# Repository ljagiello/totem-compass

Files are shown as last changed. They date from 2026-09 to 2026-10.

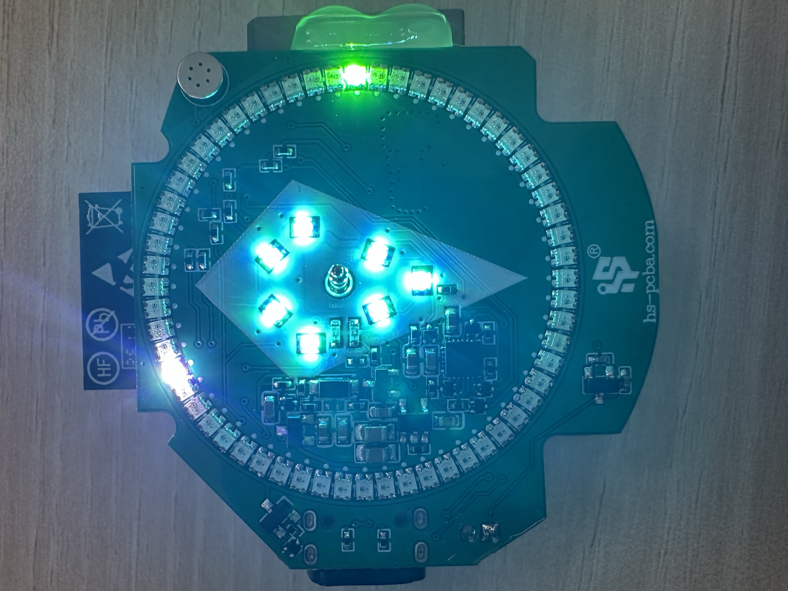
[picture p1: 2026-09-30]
hardware/totem-v3.5-reference/measure/photos/led.jpg

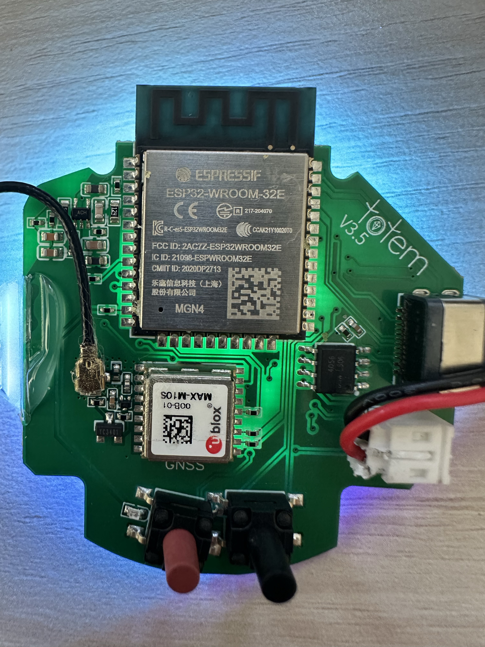
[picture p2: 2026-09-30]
hardware/totem-v3.5-reference/measure/photos/radio.jpg

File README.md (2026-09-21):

# Totem Compass firmware — reverse engineering

Independent, unofficial reverse-engineering notes for the **Totem Compass** ESP32
firmware (**v5.0.3**; v5.0.2 was analyzed first, see
[What changed in 5.0.3](docs/firmware/changes-5.0.3.mdx)), produced by static analysis of the
publicly downloadable firmware images and the companion mobile app, plus a BLE client tested
against the author's own device. Not affiliated with or endorsed by Totem Labs.

## Key findings

- The device is an **ESP32** (Xtensa LX6) running **MicroPython v1.25.0** on **ESP-IDF v5.4**.
- Totem's application is **Python**, frozen into the image as bytecode across **94 frozen modules** in v5.0.3 (96 in v5.0.2), plus 2 non-frozen on-flash `.py` files.
- Three radios share the 2.4 GHz band: **BLE** (phone app), **ESP-NOW** ("Unity Mesh",
  Totem-to-Totem), and **WiFi** (station-mode OTA; the hotspot path is sunset).
- Application messages use a shared `(cat_id, cmd_id)` model with a common chunking layer.

## Documentation

Full docs live in [`docs/`](docs/) as a [Mintlify](https://mintlify.com) site.

```bash
cd docs
npm i -g mint    # or: npx mint@latest
mint dev         # preview at http://localhost:3000
```

Start at [`docs/index.mdx`](docs/index.mdx). The 2.4 GHz protocol capture — with a
completeness matrix — is under [`docs/protocols/`](docs/protocols/).

## Go client: `totemctl`

A Bluetooth LE client that speaks the same protocol as the official app: the
ConnStatus-Ready handshake, Live/Static/Peer records, and the half-duplex TX
handoff. No pairing or keys are needed.

```bash
go install github.com/ljagiello/totem-compass/cmd/totemctl@latest

totemctl scan                     # find Totems (double-press the power button first)
totemctl info                     # name, firmware, battery, position, settings
totemctl watch                    # stream live data and peer updates
totemctl peers                    # bonded Totems and points of interest
totemctl name "Base Camp"         # rename
totemctl compass --lock on --north off --blink on
totemctl power eco --blink on     # or: normal
totemctl wifi scan                # networks the Totem can see
totemctl wifi set <ssid>          # network used for firmware updates; asks for the password
totemctl peer color <mac> hot_pink
totemctl poi add --name "Main Stage" --lat 50.0671 --lon 19.9124 --sticky
totemctl location --lat 50.0671 --lon 19.9124  # feed a phone-style GNSS fix + clock
```

Pick a device with `-d <address substring>`, using an address `totemctl scan`
prints: every Totem advertises as "totem", so the name set with `totemctl name`
cannot select one. Get machine-readable output with `--json`, and log every
frame with `--trace`. `totemctl help <command>` lists each command's flags.

Every global flag can also be set as a `TOTEM_<FLAG>` environment variable
(`TOTEM_DEVICE`, `TOTEM_HALF_DUPLEX`, …) or in a config file with the long flag
names as keys (`device: <address from totemctl scan>`). The default location is
`totemctl/config.yaml` under the user config directory (`~/Library/Application
Support` on macOS, `~/.config` on Linux), or pass `--config`.

`compass` and `power` send a frame that always sets peer blink, which the Totem
does not report, so they need `--blink on|off`; set it once with `blink: on` in
the config file or `TOTEM_BLINK`.

The Ready frame's schema id selects one of two device transmit loops. The
client defaults to the legacy full-duplex loop (schema 0: notifications plus
app-level acks), which works on every platform. The newer half-duplex loop
(`--half-duplex`) sends indications and drops a record unless it is confirmed
within 500 ms; CoreBluetooth subscribes these characteristics for
notifications only, so that mode stalls on macOS.

Verified on hardware from macOS: `scan` and `info` on firmware 4.1.3 and 5.0.3; `watch` and
`compass --lock on|off` round-trips on 4.1.3. The other commands are built from the
v5.0.2/v5.0.3 bytecode (their handlers are identical in both) and covered by unit tests
only.

| Package | Contents |
| --- | --- |
| [`protocol/`](protocol/) | frame builders and decoders, no BLE dependency; tested against vectors built with the firmware's own `struct` formats |
| [`client/`](client/) | scanning, connecting, subscriptions, acks and TX-window handling on [`tinygo.org/x/bluetooth`](https://github.com/tinygo-org/bluetooth) (tested on macOS; the library also supports Linux/BlueZ and Windows) |
| [`cmd/totemctl/`](cmd/totemctl/) | the CLI |

## ESP32 emulator: `totememu`

An ESP32 running TinyGo that joins the ESP-NOW mesh as another Totem: it pairs with a real
Totem through the normal Touch Crystal pairing and then exchanges peer status with it every
radio window. It models the rest of the device too — the halo and the crystal, the Touch
Crystal and the two buttons, the power state and its battery curve, an update over WiFi —
and keeps its name, colour and bonds in flash across a power cut. Hardware-tested against
firmware 5.0.3. See [`docs/reference/esp32-emulator.mdx`](docs/reference/esp32-emulator.mdx).

```bash
tinygo flash -target esp32-generic -ldflags "-X main.owned=<your Totem's MAC>" ./cmd/totememu

totemctl mesh pair                # hold the Totem's Touch Crystal next to the board
totemctl mesh watch               # decode every frame the Totem sends it (--raw, --tx, --json)
totemctl mesh status              # the emulator and its peers
totemctl mesh clock               # give the board this computer's time
totemctl mesh send pos 50.0671 19.9124 3   # where it is
totemctl mesh send sim walk 90             # and where it goes: walk, drive or still
totemctl mesh send batt 40                 # also: sos, heading, flat, unbond, selftest
totemctl mesh send touch crystal hold 1500 # a gesture, as a finger would make it
totemctl mesh send leds                    # what the ring and the crystal are doing
```

The `mesh` commands find the board's USB serial port by itself (or take `--port`,
`TOTEM_PORT`, `port:` in the config file). They open it without toggling DTR/RTS, so the
board does not reboot, and they decode the raw frames on the host with the `mesh` package.

| Package | Contents |
| --- | --- |
| [`mesh/`](mesh/) | ESP-NOW frame codec (peer, locate, Smart Group), tested against frames packed with the firmware's own `struct` formats |
| [`emulator/`](emulator/) | the Totem logic: pairing, radio windows, clock sync, locate reply and relay, Smart Group member, the halo and crystal, the touch and button gestures, the power state and the WiFi update, and a model of the GNSS receiver, compass, motion sensor and battery; host-tested |
| [`store/`](store/) | the settings and bonds a reboot keeps, as an append-only journal in one flash sector |
| [`cmd/totememu/`](cmd/totememu/) | the ESP32 firmware and its serial console |

## Scope & ethics

The firmware analysis is static and no service was attacked; the releases API and firmware
objects are served publicly. The only code run against hardware is `totemctl`, over BLE, and
`totememu`, over ESP-NOW, both on the author's own Totem. See
[`docs/reference/methodology.mdx`](docs/reference/methodology.mdx). Use them only with devices
you own. The mesh and demi-god paths can affect other people's Totems nearby, so `totemctl`
does not send those commands, and `totememu` talks only to the Totems it is built for, never
hosts a Smart Group and never sends demi-god commands.

## License

Licensed under the [Apache License 2.0](LICENSE).

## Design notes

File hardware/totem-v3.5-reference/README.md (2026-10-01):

# Totem v3.5 — reference design

A working circuit built from the parts identified on a Totem v3.5, with the
values chosen by calculation and checked in ngspice.

**This is a reconstruction, not a recovery.** The parts and the MCU pin
assignments are established — the parts off the board, the pins out of the
firmware, both cited in [the hardware page](../../docs/reference/hardware.mdx).
Everything else here is *designed to satisfy those facts*, not traced from the
PCB. Resistor values, the regulator topology, the LED supply arrangement: all
chosen here. Where a value is derived from something the firmware does, the
derivation is shown, and that is the strongest claim any of it makes.

Passive values cannot be recovered from photographs of an assembled board.
What can be done is to work out what they would have to be for the firmware to
behave as it does, and then check that circuit holds up. That is what this is.

## What the firmware pins down

Two constants in the firmware constrain the analog design tightly enough to
solve for it.

### The battery divider is determined, not chosen

The firmware converts its ADC reading with a fixed calibration
(`docs/subsystems/power.mdx`, `compass.dis:1446`):

```python
battery_volt = 0.0017 * self.v_supply.read() + 0.206
```

`ADC.read()` returns 0..4095. Writing the whole chain out, with `k` the
divider ratio, `VFS` the ATTN_11DB full scale and `Voff` the ADC's input
offset:

```
cal(V) = 0.0017 * 4095 * (k*V - Voff)/VFS + 0.206
```

For `cal(V) == V` at every V, both coefficients must match:

```
k    = VFS / (0.0017 * 4095) = 3.3 / 6.9615 = 0.4741
Voff = 0.206 * VFS / 6.9615  = 97.7 mV
```

The offset is not fitted — it falls out of the same two equations, and
**97.7 mV is the ESP32 ADC's well-known input offset**. That it lands there
is the evidence the model has the right shape, and it is why the `+0.206` in
the firmware is an ADC artefact rather than a fudge.

A resistor marked `124` — 120 kΩ — is on the board. Taking that as the top
leg, the ratio asks for 108.2 kΩ below it, and no standard series has that
(E96 goes 107, 110; E192 107, 109). An earlier version named a 108 kΩ
part, which is not made; the nearest that is, 109 kΩ, reads a full cell
17 mV high, over the 10 mV the checks allow. So this board uses
**113 kΩ over 102 kΩ**, both E96 and both made in 0.1%: k within 0.08% of
the firmware's, drawing 19.5 µA.
Simulated, the firmware's own calibration then reads the cell **true to
3.3 mV** across 3.4–4.2 V, against 68 mV for the 120k/100k pair tried first.

### GPIO 39 is a VBUS divider, not the charger's status pin

`modes.is_charging = self.v_in.value()` — high means charging. The TP4056's
`CHRG` is open-drain and pulls **low** while charging, and GPIO 34–39 have no
internal pull of any kind, so an open-drain source would float when idle.
Both facts are wrong for `CHRG` and right for a divider off VBUS, which also
matches the firmware's own name for it: `v_in`, the input voltage.

100 kΩ over 150 kΩ clears the logic threshold at a sagging 4.40 V charger and
stays under the absolute maximum at 5.25 V, with margin at both ends.

## Verification

```
cd sim && python3 check.py
```

Requires `ngspice` (`brew install ngspice`). Each deck computes; `check.py`
decides whether the number is allowed, and prints a line per claim. Current
state: **18 passed, 0 failed, 1 known limit recorded**.

| Block | Result |
| --- | --- |
| `batt_sense` | Pin at 1.993 V on a full cell, inside the ADC's 150–2450 mV window. Calibration true to 3.3 mV. Divider (113k over 102k) draws 19.5 µA |
| `vbus_sense` | 2.64 V at 4.40 V in (165 mV over V<sub>IH</sub>), 3.15 V at 5.25 V (450 mV under absolute max). 21 µA |
| `ldo_headroom` | Rail holds 3.293 V at a 3.4 V cell under a 532 mA peak — 293 mV over the ESP32's minimum. Fails only at 3.107 V, *below* the firmware's cutoff |
| `led_budget` | With the 1515's 15.5 mA per pixel: normal use is 0.15 C, all 67 pixels at full white at the firmware's brightness 0.62 C; 1 C would take 107. Known limit: the pixels want 3.5 V and the firmware runs the cell to 3.15 V |

The digital parts are modelled as current sinks at their datasheet peaks, and
the regulator and charger behaviourally, because no vendor models are to hand.
These verify the design's arithmetic, not anyone's silicon.

The whole board is simulated too, built from the schematic's own netlist
rather than from a hand-written deck:

```
cd sim && python3 board_sim.py
```

**78 passed, 0 failed, 1 known limit**, over five corners (cell at 4.2, 3.8
and 3.4 V; the 2N7002's threshold at 2.1 and 2.5 V). Each corner runs one
4.5-second sequence — off, press on, press while running, ring on and off,
firmware power-off, on again, held through a firmware power-off, released —
and checks the rail, GPIO 4's voltage limits and the cell's idle drain at each
step. Steady-state checks cover the rail at a TX peak with the ring lit across
the firmware's battery bands, every pixel at full white, both sense dividers
and charging. The known limit is the ring's supply at a 3.45 V cell, 3.34 V
against the 1515 LEDs' 3.5 V rating, which the reference board shares: its
ring hangs off the cell the same way.

## The board

`schematic/totem.kicad_pcb`, made by scripts in `pcb/` from the schematic
and from measurements of the reference board's photographs (`measure/`,
whose README says how, and how well, each number is known):

```
cd pcb
KP=/Applications/KiCad/KiCad.app/Contents/Frameworks/Python.framework/Versions/Current/bin/python3
$KP build.py      # outline, parts where the photos put them, nets, planes, rules
python route.py   # the router (numpy, scipy, opencv)
$KP apply.py      # tracks and vias into the board, zones filled
$KP models.py     # 3D models for the parts KiCad's library has none for
python3 fab.py    # everything for the fab and the assembler -> pcb/fab/
```

**To have boards made, hand over `pcb/fab/totem-v3.5-assembly-package.zip`.** It
holds gerbers and drills (and ODB++ and IPC-2581), the BOM and placement file,
assembly drawings, the schematic, a STEP model, and
[`pcb/ASSEMBLY.md`](pcb/ASSEMBLY.md): what to order, how to assemble, bring up
and program the board, and what to measure before ordering.

Four layers, 1.6 mm: signals on both outer layers, In1 solid GND, In2 3V3.
Tracks 0.13 mm and 0.13 mm apart, power nets 0.4 mm with 0.2 mm; vias
0.45/0.2 mm; copper 0.3 mm from the edge — a mainstream 4-layer process with
margin. The GNSS antenna feed is a straight, via-free 0.38 mm microstrip on
F.Cu over In1: 50 Ω on a standard 1.6 mm 4-layer stack-up (about 0.21 mm of
7628 prepreg under the top layer); order that stack-up, or re-size the line
for another. The LED side's ring is powered through a VLED pour outside the
ring, fed at C16 and, past the one place the ring's data has to cross it,
at D159.

Both sides carry parts (the LED side: ring, crystal, motion sensor and
magnetometer, microphone, the charge LEDs, the power latch), so assembly is
double-sided. The placement file is KiCad's;
assembly houses differ in how they read rotations on the bottom side, so
check their preview of the LED side — the ring's orientation rule is that
each LED's DI and VDD pads face out.

**`kicad-cli pcb drc --schematic-parity --severity-all`: 0 violations,
0 unconnected pads, 0 footprint errors.** Three places where the reference
board is closer than KiCad's courtyard and silkscreen margins allow (the
TP4056 0.3 mm from the module, the SOS LED between its switch's legs) are
narrow rules in `schematic/totem.kicad_dru`, each with its reason. The
router (`pcb/route.py`) also checks every net's connectivity itself before
it hands over.

What is the reference board's and what is not:

| | |
| --- | --- |
| Outline, notches, the tab | Measured: ±0.3 mm on the left half and bottom, **±1.3 mm in height on the right side** (the two photos disagree there) |
| ESP32, MAX-M10S, TP4056, LDO, u.FL, P-FET, switches, SOS LED | Measured from their pads |
| The ring | Measured: centre (−2.02, 2.45), radius 18.24 mm, 60 LEDs every 6°, **1.5 mm packages** |
| The crystal, its pogo-pin post, the IMU's site, the microphone | Measured |
| The two charge LEDs and their two resistors in the crystal, the JST's pins | Measured from close-ups of the LED side |
| The motion sensor and magnetometer | This design's: the reference board's ICM-20948 is obsolete, so an ST LSM6DSV16X sits on its site with an LIS2MDL beside it (below) |
| Passives, the latch, the ring's driver | This design's, placed beside what they serve |
| About 25 small parts in the reference board's LED-side cluster below the crystal, and a column of about 8 between the ring and the crystal | Photographed, not copied: their values and nets run under the parts and on inner layers. This design's own circuit does the jobs they must do (latch, ring switch, decoupling) |
| Every trace | Routed here; the original's are not recoverable |

**Measure these on the reference board before ordering** — each is where a
photograph could not settle it:

- **The board's height at the right edge**, and the distance from the USB-C
  to the lower-right notch: the right side is known to ±1.3 mm.
- **The USB-C.** The original's is a through-hole-shell part: on the LED
  side its four plated slots sit 4.80 mm either side of the centre line in
  two rows 3.0 mm apart, with two round holes 6.5 mm apart (measured,
  `measure/`). No catalogue footprint checked matches that (HRO
  TYPE-C-31-M-12, GCT USB4105 and USB4125, SHOU HAN TYPE-C 6P and its
  recessed 6P). The one used here, a power-only GCT USB4135, is the library
  part that clears the ring behind it; its plug face ends up **about 0.6 mm
  or more further in** than the original's (1.75 mm overhang). Check it
  against the case, and measure the original's if it can be taken out.
- **The JST** is the through-hole S2B-PH-K-S on the reference board's own
  pin positions (their solder joints, 1.96 mm apart, show on the LED side);
  its housing overhangs the lower-right chamfer as the original's does.
  Check the cable's exit against the case.
- **Button stem height.** The switches are 6 x 6 mm top-actuated tact
  switches with tall stems that go through the rear cover; the BOM names a
  9.5 mm one. The stem has to be matched to the cover.
- **The touch pogo pin**: a gold spring-loaded pin standing on the 2.5 mm
  pad at the centre of the crystal (close-up photo). Measure its length,
  barrel and travel on the reference unit: its length sets the pressure on
  the crystal.

Two things are derived, not seen:

- **Where the ring starts and which way it counts.** The links between the
  ring's LEDs run on an inner layer on the reference board, so its chain can
  not be followed. The firmware maps a bearing to pixel
  `(60 − bearing // 6) mod 60`, counter-clockwise-positive under its
  Madgwick convention, with pixel 0 along the IMU's +X; the IMU's marking puts
  +X toward the buttons. So D100 is the LED nearest the buttons and the chain
  runs counter-clockwise seen from the LED side. If the compass shows
  mirrored or rotated on the first board, this is where to look.
- **The sensors' axes.** U5 (LSM6DSV16X) and U6 (LIS2MDL) sit square to the
  board and to each other, each with pin 1 at its upper-left seen from the
  radio side (`pcb/build.py`). Their axes in the board's frame follow from
  that, from ST's axis drawings (DS13510 Figure 5, DS12144 Figure 2) and from
  their being on the LED side, which mirrors them. Confirm on the first
  board before trusting a heading: lay it flat and see which axis reads 1 g,
  then turn it and see which magnetometer axis follows north.

### Parts changed from the reference board

The board is built from parts in production. Each was checked on DigiKey or
LCSC on 2026-09-30; these are the ones that changed:

| Reference board / earlier version | Here | Why |
| --- | --- | --- |
| TDK ICM-20948 (U5) | ST **LSM6DSV16X** (U5) + **LIS2MDL** (U6), both on I2C0, interrupts to IO32 and IO33 | DigiKey: obsolete, "no longer manufactured". The ST pair is current and its sensors are better on every figure both datasheets give (table below) |
| CUI CMC-4013-SMT-TR microphone | Same Sky **CMC-4013-2-SMT-TR** | Obsolete; the -2 has the same 4 mm can and -42 dB, and its pads fall inside this footprint's |
| Everlight 19-217 red LED (SOS) | Lite-On **LTST-C191KRKT** | Not available; the green of the same series is discontinued |
| Charger status outputs left open (earlier version) | Two 0603 LEDs, red and green (D4, D5), with 1k each | The reference board has two 0603 LEDs in the crystal below the touch post; colours not visible unlit |
| SMD JST S2B-PH-SM4-TB (earlier version) | THT **S2B-PH-K-S** | The reference board's is through-hole (above) |
| "PTS645SH95SMTR92 LFS" (earlier version) | **PTS645SK95SMTR92 LFS** | The earlier part number does not exist; SK95 is the 9.5 mm SMT variant in stock |
| 108k cell-sense resistor (earlier version) | **109k** | No 108k is made (above) |

The motion sensors, from the three datasheets (TDK DS-000189 Rev 1.6;
ST DS13510 Rev 4, DS12144 Rev 6), typical values:

| | ICM-20948 | LSM6DSV16X + LIS2MDL |
| --- | --- | --- |
| Gyro noise density | 0.015 dps/√Hz | 0.0028 dps/√Hz |
| Gyro zero-rate drift over temperature | ±0.05 dps/°C | ±0.006 dps/°C |
| Accelerometer noise density | 230 µg/√Hz | 60 µg/√Hz |
| Accelerometer offset drift over temperature | ±0.80 mg/°C | ±0.07 mg/°C |
| Magnetometer initial offset | ±300 µT | ±6 µT |
| Magnetometer noise | not specified | 0.3 µT RMS |

The LIS2MDL's datasheet asks for currents above 10 mA to be kept "a few
millimeters away" (section 5.2): it sits 4.8 mm inside the ring's LEDs and
13 mm from the latch, and the router keeps every power net's track and via
3.5 mm from its centre (`MAG_KEEPOUT` in `pcb/route.py`). The charger, 5.4 mm
away on the radio side, carries its current only while charging.

## The schematic, and its ERC

```
cd schematic && python3 totem.py
```

Requires `skidl` (`pip3 install --user skidl`). The circuit is described as
code rather than drawn, which makes the connectivity machine-checkable:
SKiDL's ERC looks for pins left floating and for nets with two things driving
them. It writes `totem.net`, a KiCad netlist, and `totem.erc`.

**Current state: 0 ERC errors and 0 ERC warnings.**

An earlier version left the TP4056's `CHRG` and `STDBY` status outputs open
and ERC reported both. They now drive the two charge LEDs the reference
board has in its crystal, so nothing is left open on purpose.

Netlist generation separately reports 27 `No footprint for …` errors. Those
are not design faults — no footprints are assigned because this is a
schematic-level design with no board layout intended.

Getting there took four real corrections, which is the argument for running it
at all rather than drawing a diagram and trusting it:

- Three `POWER-OUT` conflicts, where I had the TP4056's two `BAT` pins and the
  cell all declared as independent drivers of `VBAT`. Pins 5 and 6 are one
  node on the die, and the cell shares that node rather than fighting it.
- A fourth on `GND`, from declaring connector grounds as drivers.
- `TEMP` left floating. The TP4056 needs it tied off when no thermistor is
  fitted, which is easy to forget and silent when forgotten.
- The regulator's `EN` left floating — which is where the GPIO 4 power gate
  has to live, so the warning was pointing at a missing part of the design.

A fifth was mine rather than the design's, and is worth recording because of
how it hid. Trying to silence the two status-pin warnings, I imported a name
SKiDL 2.3.0 does not export. The script then died on the import — but the
run before it had been `rm -f totem.erc` followed by the script with output
sent to `/dev/null`, so an empty file was left behind and read back as a
clean result. **An absent report is not a passing one.** `check.py` fails
loudly on a missing measurement for the same reason; this checker now
insists the ERC file exists before believing it.

### Real symbols, and what that bought

Parts come from **KiCad's own symbol libraries** wherever they exist —
ESP32-WROOM-32E, MAX-M10S, ICM-20948, WS2812B, and the passives — so the
netlist carries real package pin numbers rather than labels invented here.
Only the TP4056 is still declared inline, because KiCad has no symbol for it.

This is not cosmetic. On the module, pins 4 and 5 are named `SENSOR_VP` and
`SENSOR_VN` — GPIO 36 and GPIO 39, the microphone and the VBUS sense.
Wiring against the real symbol is what puts those on the correct physical
pins. Two things the real symbols caught that a hand-written pin list could
not:

- **`EN` was unconnected.** The ESP32 will not run with its enable floating,
  and it needs the pull-up and capacitor that give it a power-on reset. The
  hazard of a pin list written by hand is that a pin nobody thought of is
  also a pin nobody notices is missing.
- **`RESV` is typed NO-CONNECT** on the ICM-20948 symbol, and I had tied it
  to ground. The symbol is authored from the datasheet, so it wins.

### The sheet

```
python3 gen_sch.py                                    # writes totem.kicad_sch
kicad-cli sch erc --output totem_erc.rpt totem.kicad_sch
kicad-cli sch export svg --output . totem.kicad_sch   # writes totem.svg
```

**Open `totem.kicad_sch` in KiCad.** It is generated from the same `totem.py`
the ERC checks, so the drawing cannot drift away from the netlist, and it
embeds KiCad's own symbol definitions — the drawing of a resistor is KiCad's
drawing of a resistor.

It is drawn the way a schematic is drawn. **Rails carry KiCad's power
symbols** at each pin, which is how every real sheet does it and which took
about 150 labels off the drawing. **Short point-to-point runs are wired**, so
a divider or an RC is a line you can follow. **Signals with several
destinations keep a label**, which is also what a real sheet does.

A first version put a label on every pin instead. It passed ERC and was
unreadable — nothing on it *looked* connected, which fails the only job a
schematic has.

Long routes are deliberately not drawn, and ERC is the reason. Routing every
two-ended net with an automatic corner produced this:

```
[multiple_net_names]: Both ESP_EN and POWER_EN are attached to the same items
```

A wire endpoint had landed on another net's wire and shorted two separate
nets together — a drawing that looked right and was electrically wrong. Runs
longer than 45 mm are labelled rather than routed for that reason. Laying
those out properly is hand work in KiCad, on top of this file.

**KiCad's own ERC: 0 errors, 2 warnings.** Both are explainable and left
reported. `SDO/AD0` is the ICM-20948's address-select pin strapped low, which
KiCad notes because a bidirectional pin is sitting on a power net. `PROG` is
isolated because U3 is not on the sheet at all — the TP4056 has no KiCad
symbol, so it is the one part that cannot be drawn, and `gen_sch.py` says so
when it runs rather than quietly omitting it.

Getting there took three rounds, each of which is a thing a hand-drawn sheet
would have hidden:

- **124 off-grid endpoints**, from a 40 mm margin that is not a multiple of
  KiCad's 1.27 mm grid. With a label on every pin, one careless constant is
  one violation per pin.
- **35 unconnected pins**, now carrying explicit no-connect markers, which is
  how a schematic says "deliberately" rather than leaving a reader to guess.
- **A symbol that drew as nothing.** `AP2127K-3.3` *extends* `AP2204K-1.5`,
  so its own block holds properties and no pins at all. Embedded as it comes,
  the regulator would have landed on the sheet with no pins to attach a wire
  to. `kicad_sexp.py` flattens inherited symbols for that reason.

### The earlier drawing, and why it went

SKiDL 2.3.0 cannot draw this circuit: both `generate_svg` and
`generate_schematic` crash in its `kicad10` backend on the real multi-unit
symbols (`gen_svg.py:310`, `AttributeError: 'NoneType' object has no
attribute 'net'`). That is why `gen_sch.py` exists and writes the sheet
directly.

An earlier SVG did exist, made when the parts were simplified inline
definitions, and it was **deleted rather than kept**: once the parts became
real symbols it no longer matched the netlist, and a picture that disagrees
with the netlist is worse than no picture.

## Three findings worth keeping

**The firmware protects the hardware, not the other way round.** The 3V3 rail
only collapses below the ESP32's 3.0 V minimum at a cell voltage of 3.107 V.
The firmware gives up on the cell around 3.4 V, so it always stops first —
about 290 mV of margin.

**Every pixel at full white is 2.41 A, or 2.41 C.** A 1000 mAh pouch cell is
good for about 1 C, so the ring simply cannot be filled white at the default
brightness; the ceiling is 27.8 pixels. This is not a flaw in the design, it
is a constraint the firmware already respects — it lights north and the peers,
and eco mode blanks the ring entirely. It does mean any future animation that
fills the ring has a current budget to answer to.

**The pixels are under-supplied at the bottom of the discharge.** WS2812B want
VDD ≥ 3.5 V and the firmware runs the cell to 3.4 V, leaving them 100 mV
short. The strips cannot move to the 3V3 rail instead — that is further below
their minimum, and 2.4 A through a linear regulator is not a circuit anyone
builds. Either the fitted pixels are a low-voltage variant, or colour accuracy
degrades near empty. Both are testable on the bench; neither is settled here.

A fourth is a caution rather than a finding: 481 mW in the pass element at a
full cell would be 120 °C of rise in a SOT-23-5 at θ<sub>JA</sub> ≈ 250 °C/W.
That figure is the **peak**, at a 500 mA radio transmit burst with a
low duty cycle, so it is transient and the average is far below it. A design
that drew that continuously would need a different package or a switcher.

## Not covered

- **The reference board's traces and inner layers.** Not recoverable from an
  assembled board; this board is routed afresh (see "The board").
- **The GNSS UART pins** on the module side are taken from the firmware's
  `UART(1, rx=16, tx=17)`, not traced.
- **The `J22B` SOT-23-5 and the `A7` / `65KS` SOD-123s** on the LED side.
  Legible markings, nets untraced. The `A7` is the usual marking of a
  1N4148W, which this design's latch uses; the rest are left out rather than
  drawn in wrongly. (What was listed here as a separate "U6" SOIC-14 marked
  `I2948` is the IMU itself, photographed at an angle.)
- **The power gate's topology** is designed to the firmware's behaviour, not
  recovered: GPIO 4 read as an input while running, re-opened as an output and
  driven low to switch off. It is simulated in every corner above.

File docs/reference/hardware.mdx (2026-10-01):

---
title: "Totem hardware"
description: "The parts on a Totem v3.5 board and the nets between them, read off the PCB and matched to the pins the firmware drives."
---

Every other page here was derived from the firmware image. This one starts at the other end:
a **Totem v3.5** opened up and photographed, then matched against the pins the firmware
actually drives. Each net below has a part at one end and a cited line of bytecode at the
other.

<Warning>
  **This is a net-level schematic, not a reverse-engineered one.** It says which parts exist
  and what each MCU pin is connected to. It does not give passive values, series resistors,
  divider ratios or trace routing: those live under the components and on inner layers, and
  no photograph of an assembled board can recover them. Nothing here is guessed to fill a
  gap — where the answer is not known, the page says so.
</Warning>

Confidence markers mean what they do elsewhere in these docs. **Confirmed** additionally
means a part number legible on the silkscreen, or a count taken from the photograph and
matched independently in the bytecode. **Inferred** means the photograph is consistent and
nothing contradicts it.

<Note>
  **To build one:** a working board designed from this page is in
  [`hardware/totem-v3.5-reference`](https://github.com/ljagiello/totem-compass/tree/main/hardware/totem-v3.5-reference).
  It has the reference board's outline and its major parts where the photographs put them;
  its passive values and traces are its own, and it uses parts in production where the
  original's are not: an ST LSM6DSV16X and LIS2MDL in place of the obsolete ICM-20948, among
  others (its README, Parts changed). The file to hand to a fab and an assembler is
  `pcb/fab/totem-v3.5-assembly-package.zip`, with
  [`ASSEMBLY.md`](https://github.com/ljagiello/totem-compass/blob/main/hardware/totem-v3.5-reference/pcb/ASSEMBLY.md)
  inside: what to order, how to assemble, bring up and program the board.
</Note>

## Bill of materials

| # | Part | Marking | Role |
| --- | --- | --- | --- |
| U1 | **Espressif ESP32-WROOM-32E** | `ESP32-WROOM-32E`, FCC ID `2AC7Z-ESP32WROOM32E`, IC `21098-ESPWROOM32E`, CMIIT ID `2020DP2713` | Application CPU, WiFi, BLE and ESP-NOW, with its own PCB meander antenna |
| U2 | **u-blox MAX-M10S** | `MAX-M10S`, `u-blox`, silkscreen `GNSS` | GNSS receiver: GPS, Galileo, BeiDou and GLONASS concurrently |
| U3 | **TP4056 LiPo charger** | `4056`, lot `L30B`, SOP-8 | Single-cell linear charger, between J1 and J2, with its programming resistors alongside. The marking is a bare `4056`, so a marking-compatible clone is not excluded |
| U4 | **Regulator (probable)** | `ACH`, SOT-23-5 | Sits in a group of capacitors on the radio side. Package, position and decoupling are those of a 3V3 LDO; a three-letter code is shared across manufacturers, so **no part is claimed** |
| U5 | **InvenSense ICM-20948** | `I2948`, `B23LA1`, `2602` | The 9-axis part: gyroscope, accelerometer **and** magnetometer in one 3x3 mm QFN-24 on the LED side, on I²C bus 0. The firmware names it — `c_icm20948_mag.Icm20948Mag` ([Navigation](/subsystems/navigation)) — and its on-die magnetometer is an AK09916 reached through `imu.mag()`. The marking agrees: `I2948` is TDK's top mark for the ICM-20948, `2602` a 2026 week-2 date code. It is legible only at a grazing angle under flash; head-on the lid looks blank, and an earlier version of this table listed the two views as two parts (`U5`, unmarked, and `U6`, a "SOIC-14" — the QFN's edge pads seen obliquely). **There is no separate magnetometer chip on this board** |
| D? | **Diode** | `A7`, SOD-123 | The standard marking for a 1N4148W small-signal diode |
| Q? | **SOT-23-5** | `J22B` (also read `J2ZB`) | On the LED side beside the IMU; nets untraced |
| Q? | **SOT-23** | `63K5`, `UMW` | On the LED side in the cluster below the crystal; UMW is the maker's mark. Part not identified, nets untraced |
| D?, D? | **Two 0603 single-colour LEDs** | — | On the LED side, inside the crystal below the touch post, each with an 0603 resistor beside it (close-up photographs). **Inferred:** the TP4056's charge-status LEDs (`CHRG`, `STDBY`), which nothing in the firmware drives. Colours not visible unlit |
| — | **Chip resistor** | `124` | 120 kΩ |
| MK1 | **MEMS microphone** | — | Ported can beside the halo. Read as an ADC level, not an audio peripheral |
| DS1…DS60 | **Halo ring** | — | 60 addressable RGB LEDs, WS2812-style, GRB order (**confirmed**). **1.5 x 1.5 mm packages**: measured 1.50 mm wide at a 1.91 mm pitch on an 18.24 mm radius (`hardware/totem-v3.5-reference/measure/`), which a 2 x 2 mm WS2812B-2020 could not fit; castellated pads on the ring's outer and inner edges, as the XL-1515RGBC-WS2812B's |
| DS61…DS67 | **Touch Crystal cluster** | — | 7 more under the moulded light pipe (**confirmed**), mirror-symmetric about the ring's vertical axis around a central spring post: pairs at three heights and one below |
| DS68 | **SOS indicator** | — | A discrete LED on its own pin, not part of either strip |
| SW1 | **Power button** | black cap | Tactile switch. Also the power latch — see below |
| SW2 | **SOS button** | red cap | Tactile switch |
| TP1 | **Touch Crystal post** | — | A gold spring-loaded (pogo) pin standing on a pad at the centre of the crystal, pressing on the light pipe (close-up photographs) |
| J1 | **USB-C receptacle** | — | Through-hole shell: four plated slots and two round holes show on the LED side. Charging only. The board has no USB-UART bridge (the one QFN is the IMU, above) and the ESP32-WROOM-32E has no USB of its own, so no data can reach the module through this port; updates come over Wi-Fi ([OTA](/subsystems/ota)) |
| J2 | **JST battery connector** | — | Two-pin, red and black. Through-hole: its two pins' solder joints show on the LED side, 1.96 mm apart (the PH series' 2 mm pitch) |
| J3 | **u.FL / IPEX connector** | — | One coaxial pigtail, sitting **directly below U2** with U1 carrying its own PCB antenna. The GNSS antenna |
| BT1 | **LiPo cell** | `805080`, `1000mAh`, `3.7Wh`, `3.7V`, dated `2023.05.18` | Single cell in the housing |
| — | **PCB** | `Totem v3.5`, `hs-pcba.com` | Board revision and contract manufacturer |

## Schematic

```mermaid
flowchart TB
    USB["J1 USB-C"] -->|VBUS| CHG["U3 TP4056<br/>single-cell charger"]
    CHG <-->|BAT| J2["J2 JST"]
    J2 <--> BT["BT1 LiPo 1000mAh 3.7V"]
    J2 -->|VBAT| LDO["U4 regulator<br/>SOT-23-5 'ACH'"]
    LDO -->|3V3| U1

    U1["U1 ESP32-WROOM-32E<br/>CPU + WiFi + BLE + ESP-NOW"]

    J2 -.->|divider| A34["GPIO 34 ADC<br/>battery volts"]
    CHG -.->|"CHRG, open drain"| A39["GPIO 39 in<br/>is_charging"]
    A34 --> U1
    A39 --> U1

    U1 ---|"UART 115200, UBX"| U2["U2 u-blox MAX-M10S<br/>GPS+GAL+BDS+GLO"]
    U2 --- J3["J3 u.FL antenna"]

    U1 ---|"I2C0 SDA 25 / SCL 26"| U5["U5 ICM-20948<br/>gyro + accel + magnetometer"]

    MK1["MK1 MEMS microphone"] -->|"GPIO 36 ADC"| U1
    SW2["SW2 SOS button"] -->|"GPIO 0, pull-up"| U1
    TP1["TP1 touch pad"] -->|"GPIO 27 cap touch"| U1
    SW1["SW1 power button"] <-->|"GPIO 4 in/out"| U1
    U1 -->|"GPIO 4 driven low"| GATE["external power gate"]
    GATE -.->|releases| LDO

    U1 -->|"GPIO 18 data"| RING["DS1-DS60 halo ring"]
    U1 -->|"GPIO 19 enable"| RING
    U1 -->|"GPIO 21 data"| CRY["DS61-DS67 crystal"]
    U1 -->|"GPIO 14"| SOSLED["DS68 SOS LED"]
```

## Net list

Every row's pin comes from the firmware and is cited; the destination is what the
photographs show at the other end.

| Net | Pin | Direction | Destination | Source |
| --- | --- | --- | --- | --- |
| `RING_DATA` | **GPIO 18** | out | DS1…DS60 | [LEDs](/subsystems/leds) |
| `RING_EN` | **GPIO 19** | out, pull-up | Halo ring | [LEDs](/subsystems/leds) |
| `CRYSTAL_DATA` | **GPIO 21** | out | DS61…DS67 | [LEDs](/subsystems/leds) |
| `TOUCH` | **GPIO 27** | cap touch | TP1 | [Power](/subsystems/power) — literal confirmed, role inferred |
| `BTN_PWR` / `PWR_LATCH` | **GPIO 4** | in, pull-up; re-opened as out | SW1 and the power gate | [Power](/subsystems/power) |
| `BTN_SOS` | **GPIO 0** | in, pull-up | SW2 | [Power](/subsystems/power) |
| `SOS_LED` | **GPIO 14** | out, pull-down | DS68 | [Power](/subsystems/power) |
| `VBAT_SENSE` | **GPIO 34** | ADC, `ATTN_11DB` | Divider off BT1 | [Power](/subsystems/power) |
| `CHG_PRESENT` | **GPIO 39** | in | A divider off VBUS, not U3's `CHRG` — see below | [Power](/subsystems/power) |
| `MIC` | **GPIO 36** | ADC, `ATTN_11DB` | MK1 | [Power](/subsystems/power) |
| `I2C0_SDA` | **GPIO 25** | bidirectional | U5 | [Navigation](/subsystems/navigation) |
| `I2C0_SCL` | **GPIO 26** | out | U5 | [Navigation](/subsystems/navigation) |
| `GNSS_TX` / `GNSS_RX` | **not recovered** | UART | U2 | [Navigation](/subsystems/navigation) |

The pull-ups named above are the ESP32's **internal** ones, since that is what the firmware
asks for (`Pin.PULL_UP`). Whether external pull-ups are also fitted — on I²C they normally
must be — is not visible.

## Notes on the interesting nets

### GPIO 4 is the power button and the power latch

While the Totem runs, GPIO 4 is an input with a pull-up and reads SW1. To switch off, the
firmware re-opens the *same pin* as an output and drives it low, releasing an external
hardware gate:

```python
Pin(4, Pin.OUT, Pin.PULL_UP).off()
```

That is the real "off" ([Power](/subsystems/power)). Button and latch share one net, so the
board cannot read the button while it is asserting the latch — which is exactly what powering
down means.

### Charging and regulation are separate parts

U3 is a **charger only**: a TP4056 takes VBUS from the USB-C receptacle and charges the cell,
and that is all it does. It does not supply the board. The 3V3 the ESP32 runs on comes from
U4, the SOT-23-5 sitting in its own group of capacitors, fed from the battery rather than
from USB — which is why the Totem runs identically on and off the cable, and why `GPIO 34`
reads the cell rather than the supply.

`GPIO 39` is **not** wired to the TP4056's `CHRG` pin, though that is the first guess and I
made it here before checking. Two facts rule it out:

- `modes.is_charging = self.v_in.value()` ([Power](/subsystems/power)), so the pin reads
  **high** while charging. `CHRG` is open-drain and pulls **low** while charging. The
  polarity is backwards.
- GPIO 34–39 on the ESP32 are input-only and have **no internal pull resistors at all**, and
  `Pin(39, Pin.IN)` asks for none. An open-drain output with no pull-up would float whenever
  it was not charging, and the firmware would read noise.

The firmware's own name for it is `v_in` — input voltage. A divider from VBUS satisfies both
facts: high when the cable is in, pulled to ground by the lower resistor when it is out, and
the thing being sensed is the supply rather than the charger's state.

### The microphone is a loudness sensor

`mic.read_u16` on GPIO 36 feeds Vibe Mode, which drives the halo from sound level
(`new_vibe.dis:478`). Nothing in the image decodes audio, and there is no I²S peripheral in
play: the MEMS part is sampled as an analogue level.

### The GNSS link is binary, and the firmware configures it

The receiver is driven over **UBX** at 115200 with `CFG-UART1OUTPROT-NMEA` **off** and
`CFG-MSGOUT-UBX_NAV_PVT_UART1` on, so it emits NAV-PVT every epoch and no `$G…` text at all
([Navigation](/subsystems/navigation)). The Totem does not merely read its receiver, it tells
it what to be.

### Both LED strips are one peripheral

Ring and crystal are separate data pins but the same driver, timing and wire order: WS2812
timings of 400/850/800/450 ns through `machine.bitstream`, three bytes per pixel, **GRB**,
no white channel ([LEDs](/subsystems/leds)).

## What is not known

These are gaps, not omissions, and each one names the photograph that would close it:

| Unknown | What would resolve it |
| --- | --- |
| U4 (`ACH`) and Q? (`J22B`) | Same: legible, unidentified. Three- and four-letter codes are reused across manufacturers |
| GNSS UART pin numbers | The traces leaving U2 are visible but not followable past the module's pads; a deeper decode of the UART init is the better route |
| Passive values, divider ratios, series resistors | A bare board, or the manufacturer's files. Not recoverable from an assembled one — the single `124` above is the exception that shows the rule |
| External pull-ups on I²C | Same |

Flash with the halo switched off is what produced most of the markings above; the earlier set
had the board lit by its own LEDs, which erased them. It also took a grazing angle to read
U5's laser marking at all: head-on, the lid reads as blank.

## How this differs from the emulator board

The [ESP32 emulator](/reference/esp32-emulator) runs on a LILYGO T-Beam SUPREME — a different
board with different parts:

| | Totem v3.5 | T-Beam SUPREME |
| --- | --- | --- |
| MCU | ESP32-WROOM-32E | ESP32-S3 |
| GNSS | u-blox MAX-M10S | u-blox MAX-M10S, the same module and firmware (SPG 5.10) |
| GNSS protocol | UBX binary, NMEA off, firmware-configured | NMEA text, **no configuration sent at all** |
| Power | integrated path, GPIO 4 latch | AXP2101 PMU on I²C |
| IMU and magnetometer | one ICM-20948 on I²C bus 0, 9-axis | two parts: QMI8658 on SPI, QMC6310 at 0x3c on I²C |
| Microphone | yes, GPIO 36 | none |
| LEDs | 60 + 7 addressable | none |

The T-Beam SUPREME is sold with either a u-blox MAX-M10S or a Quectel L76K, so the emulator
asks its receiver at boot and logs the answer (`gnss receiver`, and `gnss=` on the status
line). The bench board's receiver was identified that way: its UBX-MON-VER reply reads `MOD=MAX-M10S`,
`FWVER=SPG 5.10`, and it rejects Quectel's `PCAS` commands. Left unconfigured it solves from
GPS, Galileo, BeiDou and QZSS at once (its GSA sentences carry system IDs 1, 3, 4 and 5), with
GLONASS off.

Measured side by side on one desk, in the same minute: **the Totem reported 18 satellites and
±2.2 m, the T-Beam 5–8 satellites and 3–13 m.** The receiver is not the reason: it is the same
part. What is known to differ is what surrounds it. The Totem's firmware configures its
receiver and the emulator sends nothing, and the bench T-Beam has no cell fitted, so its
receiver has no backup power and every power-up is a cold start. Which of these (or the antenna,
or how long each had been running) accounts for the gap has not been measured. Everything the
emulator derives from its own position — a peer's bearing most of all — inherits the gap until
it is.

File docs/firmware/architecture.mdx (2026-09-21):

---
title: "Application architecture"
description: "The MicroPython application: 94 frozen modules (v5.0.3) and how they are layered."
---

## Layered view

Totem's firmware is a MicroPython application organized into a small number of
packages plus a set of top-level modules — **94** frozen modules in v5.0.3 (v5.0.2: 96;
the unused `imu_fusion.py` and `io_mgr.py` were removed). From the bottom up:

```text
┌─────────────────────────────────────────────────────────────┐
│  Application    compass.py · compassing.py · main.py          │
│                 project_main.py · new_vibe.py · chat_msg.py    │
├─────────────────────────────────────────────────────────────┤
│  Comms          f_ble/ (BLE)   espnow*/peer* (ESP-NOW mesh)    │
│                 data_upload_v2 · svc_ble_transfer · ota_ble    │
├─────────────────────────────────────────────────────────────┤
│  Sense & act    ubx_gnss · imu_fusion_auto · mag_wmm_data      │
│                 leds · animations · touch_button_v2             │
│                 button · device_power · ds18x20                 │
├─────────────────────────────────────────────────────────────┤
│  Platform lib   f_lib/ (wifi, requests, task_mgr, rtc, gzip,   │
│                 tarfile, logger, file_mgr, firmware_ota…)       │
├─────────────────────────────────────────────────────────────┤
│  Runtime        MicroPython v1.25.0 · asyncio · espnow · ble    │
│                 (native, on ESP-IDF v5.4)                       │
└─────────────────────────────────────────────────────────────┘
```

## Packages

### `f_lib/` — platform library

Reusable infrastructure used by everything above it.

| Module | Role |
| --- | --- |
| `wifi.py`, `wifi_v2.py` | station/AP control, connect, scan |
| `requests.py` | HTTP client (used by OTA and cloud sync) |
| `task_mgr.py`, `async_helpers.py`, `generators.py` | asyncio task orchestration |
| `event_manager.py` (top-level) | pub/sub event bus (`evt_*` events) |
| `rtc_mem.py` | the RTC-memory allocator — frames retained in `machine.RTC().memory()` across a reset |
| `rtc_v2.py` | *not* RTC storage: `class RTCv2(machine.RTC)` adding calendar/timestamp maths |
| `file_mgr.py`, `gzip.py`, `tarfile.py`, `unpack.py` | file + archive handling for `.tgz` OTA packages |
| `firmware_ota.py`, `firmware_rollback.py`, `firmware_helpers.py` | OTA slot write + rollback |
| `neopixel_v2.py` | the addressable-LED driver — `leds.py` imports `NeoPixel` from here |
| `bitwise.py`, `helpers.py`, `logger.py` | utilities and structured logging |

### `f_ble/` — Bluetooth LE

| Module | Role |
| --- | --- |
| `peripheral.py` | builds the BLE advertising payload (`gen_advertise_payload`) |
| `ble_lite.py` | `BleLite` GATT peripheral: `advertise`/`advertise_burst`, `enable`/`disable`, `register_services`, `add_characteristic`, connection lifecycle (`irq_cb`, `disconnect`) |
| `ble_data.py` | GATT data types: `Characteristic` (flag bits), `Service`, `Conn` (connection status), `BleErr` |
| `chunking.py` | fragmenting large payloads into chunks (`FileTransfer`, `gen_transfer_buff`, `download_ota`/`download_vfs`) |
| `file_upload.py` | chunked file transfer with resume/ACK (`FileUploader`: `request`, `_send_header`, `_stream`, pause gates) |

### `f_ota/` — update engine

| Module | Role |
| --- | --- |
| `main.py` | OTA orchestration |
| `hotspot.py` | phone-hotspot update flow (`totemupdate` SSID) — now **sunset**; WiFi OTA (`Performing Firmware update via WiFi`) is the active update path |
| `install_ota.py` | write + activate the new slot |
| `config.py`, `system.py`, `f_assets.py` | update config, system helpers, asset fetch |

## Top-level modules by subsystem

<Tabs>
  <Tab title="Compass & nav">
    `compass.py`, `compassing.py`, `ubx_gnss.py`, `nav_helpers.py`, `nav_logger.py`,
    `imu_fusion_auto.py`, `mag_wmm_data.py`, `task_mag_declination.py`
  </Tab>
  <Tab title="LEDs">
    `leds.py`, `animations.py`, `f_lib/neopixel_v2.py`.
    (`neopixel.py` and `apa106.py` are also frozen but are
    [dead code](/reference/modules) — nothing imports them.)
  </Tab>
  <Tab title="Input & sensors">
    `button.py`, `touch_button_v2.py`, `peripherals.py`, `ds18x20.py`, `onewire.py`,
    `new_vibe.py`
  </Tab>
  <Tab title="Mesh & peers">
    `espnow.py`, `espnow_conn_v2.py`, `espnow_msg.py`, `aioespnow.py`,
    `peer_auto_bond.py`, `peer_helpers.py`, `peer_management.py`
  </Tab>
  <Tab title="Comms & upload">
    `ble_controller.py`, `ble_core.py`, `ble_manager.py`, `svc_ble_transfer.py`,
    `data_upload_v2.py`, `ota_ble.py`, `ota_block_writer.py`, `ota_callback.py`,
    `ota_daemon.py`, `chat_msg.py`
  </Tab>
  <Tab title="Power & system">
    `device_power.py`, `wdt_manager.py`, `stats.py`, `debugger.py`,
    `demi_god.py`, `flashbdev.py`, `inisetup.py`, `webrepl.py`, `mip/`
  </Tab>
</Tabs>

The full list with one-line descriptions is on the [module reference](/reference/modules),
which also rates each module **DECODED / PARTIAL / NAME-ONLY** so you can tell which of
the roles above were read out of the bytecode and which are still guesses. Of the 68 Totem
application modules, 28 are decoded, 27 are partial, and 13 have never been read.

## Concurrency model

The application is **asyncio-based**. `f_lib/task_mgr.py` and the frozen `asyncio`
package schedule long-running coroutines (BLE service loop, mesh outbox drain, GNSS
polling, LED animation ticks, background checks). Many tasks wait on `evt_*` events from
the `event_manager` bus before doing work, so subsystems can be paused and resumed — for
example, `evt_ble_active` and `evt_battery_usable` gate BLE and battery-dependent tasks,
and Vibe Mode (`new_vibe`) waits on events such as `evt_non_eco_mode` and
`evt_led_override_off`. (The v5.0.2 log lines `task started, waiting on enable events` /
`task cancelled` came from Vibe Mode's `_DBG` telemetry and no longer exist in v5.0.3.)

In v5.0.3 `compass.start` launches the ESP-NOW comms task through
`enow_v2.communicate_supervised`, which restarts it if it crashes (v5.0.2 launched
`communicate_v2` directly).

A separate async watchdog-feed loop (`wdt_manager.py` / `WdtManager`) runs alongside
`task_mgr` and asyncio: it feeds the hardware WDT via `wdt_feed_loop` / `feed_now`, but
is disabled while any `WdtConditions` condition or `WdtBlockers` blocker is active
(`_should_enable` returns False). v5.0.3's blockers are `log rotate`, `vfs write`, and the
new `wlan kick` (`WLAN_KICK = 2`, set by `ble_manager` around its WiFi-driver kick). When
the loop is running, a stalled event loop stops the feed and lets the watchdog fire.

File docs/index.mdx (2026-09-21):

---
title: "Totem Compass Firmware"
description: "Reverse-engineering documentation for the Totem Compass ESP32 firmware, version 5.0.3."
---

<Note>
This is independent, unofficial reverse-engineering documentation produced by static
analysis of publicly downloadable firmware images. It is not affiliated with or
endorsed by Totem Labs. No services were attacked. Findings come from reading the firmware
binaries and the companion mobile app. The BLE protocol was additionally exercised with the
`totemctl` client against the author's own device (firmware 4.1.3 and 5.0.3), and the ESP-NOW
mesh with an [ESP32 emulator](/reference/esp32-emulator) that bonded with that device; where
that changed a conclusion, the page says so.
</Note>

## What this documents

The **Totem Compass** is a festival navigation and social device: a handheld puck with
a ring of addressable LEDs (called the "halo" in the companion app; `RING_PX_COUNT` in
firmware), a light-up capacitive touch crystal (the app's "Touch Crystal";
`CRYSTAL_PX_COUNT` plus the ESP32 `touch_pad` peripheral), a GNSS receiver, an IMU, and
three 2.4 GHz radios. Groups of Totems bond into a mesh so friends can find
each other, send taps and messages, and navigate to a shared point.

This site documents firmware **v5.0.3** at the level recoverable from the binary. It started
from v5.0.2; [What changed in 5.0.3](/firmware/changes-5.0.3) lists the differences.

- The firmware is an **ESP32** application built on **ESP-IDF v5.4**.
- The device runs **MicroPython v1.25.0**; all of Totem's own logic is **Python**,
  frozen into the image as compiled bytecode across **94 modules** (plus 2 on-flash VFS
  source files, `boot.py` and `webrepl_cfg.py`, for 96 total `.py` files; v5.0.2 had 96
  frozen modules).
- Three radios share the 2.4 GHz band: **BLE** (phone app), **ESP-NOW** (Totem-to-Totem
  mesh, called the "Unity Mesh" in the companion app; `MODE_ESP_NOW_*` / `MESH_*` in
  firmware), and **WiFi** (station-mode OTA updates; the device-hosted hotspot path is sunset).

<CardGroup cols={2}>
  <Card title="Firmware architecture" icon="microchip" href="/firmware/architecture">
    MicroPython app layout, the 94 frozen modules, and how they fit together.
  </Card>
  <Card title="2.4 GHz protocols" icon="tower-broadcast" href="/protocols/overview">
    BLE, ESP-NOW mesh, WiFi OTA — message format, categories, and framing.
  </Card>
  <Card title="Navigation stack" icon="location-crosshairs" href="/subsystems/navigation">
    u-blox GNSS, AssistNow, IMU fusion, and World Magnetic Model declination.
  </Card>
  <Card title="OTA & download URL" icon="download" href="/reference/download-url">
    How updates are fetched and how the firmware URL is constructed.
  </Card>
</CardGroup>

## Firmware at a glance

| Property | Value |
| --- | --- |
| Product | Totem Compass |
| Version | 5.0.3 (S3 branch `totem`), release id 339: `f_ota/system.py` constants `release_code = '5.0.3'`, `release_id = 339`; the device reports the same in its BLE Static Data |
| SoC | ESP32 (original), Xtensa dual-core (LX6, inferred), chip id 0 (inferred; `ESP_CHIP_ID_ESP32`) |
| Framework | ESP-IDF v5.4 (`-dirty`) |
| Runtime | MicroPython v1.25.0 (`MicroPython v1.25.0-dirty on 2026-09-16`) |
| Build date | Sep 12 2026, 16:11:34 |
| Image size | 1,699,872 bytes |
| SHA-256 (image file) | `bfe1f5a4c39790d068ab4f041a6a56766f4b21f48289518d83d831b323450dc4` (of the flashable `.bin`; matches the release API and the download) |
| App ELF SHA-256 | `97a29359fa06661ac57840a7d041650ed1fdb08aca8712ec2373d91ea37b5777` (`esp_app_desc_t.app_elf_sha256`, pins the source ELF; a distinct value from the image-file hash above) |
| Flash | 4 MB, DIO @ 40 MHz (read from the image header via `esptool`) |
| Segments | 7 (see [memory map](/firmware/memory-map)) |

## How complete is this?

The **inventory** is complete: all 94 frozen modules are identified and every one of them
appears in these docs. The **analysis** is not.

Of the 68 modules that are Totem's own code (the other 26 are stock MicroPython and empty
package inits), 28 have had their behaviour read out of the bytecode, 27 are partly
decoded, and **13 are documented by name only and have never been read** — including
`f_lib/logger.py`, which 41 of the other modules import. By volume of disassembly, that is
roughly 55% decoded, 35% partial, 10% untouched.

The [module reference](/reference/modules) rates every module individually and ranks what
is left, so you can tell a verified claim from a plausible guess before relying on it.

## How to read this documentation

Findings are graded by how directly the binary supports them:

<AccordionGroup>
  <Accordion title="Confirmed" icon="circle-check">
    Directly present in the image: version strings, module names, GATT UUIDs,
    struct/format strings, log messages, and the observed `(cat_id, cmd_id)` pairs.
  </Accordion>
  <Accordion title="Inferred" icon="circle-half-stroke">
    Strongly implied by symbol names and log text but assembled by the analyst
    (for example, the role of a module or the meaning of a command namespace).
  </Accordion>
  <Accordion title="Needs bytecode disassembly" icon="circle-question">
    Exact numeric values that live only inside frozen bytecode — the complete
    `cmd_id` enumeration and the precise binding of each `struct` format to a message.
    See [methodology](/reference/methodology) for how to close these gaps.
  </Accordion>
</AccordionGroup>

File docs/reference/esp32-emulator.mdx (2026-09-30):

---
title: "ESP32 emulator"
description: "An ESP32 running TinyGo that joins the ESP-NOW mesh as another Totem."
---

`cmd/totememu` turns a stock ESP32 into a Totem on the [ESP-NOW mesh](/protocols/espnow-mesh).
It pairs with a real Totem over the air, and from then on the two exchange peer status every
radio window like any two bonded Totems. It is written in Go and built with TinyGo and
[`tinygo.org/x/espradio`](https://github.com/tinygo-org/espradio).

A Totem's GNSS receiver, magnetometer, motion sensor and power chip are modelled too, so the
emulator reports a position that moves, a compass, a battery that drains and a clock
(see [simulated hardware](#simulated-hardware)). On a board that has those parts, its own
drivers replace the model — which is what the [T-Beam S3 Supreme](#the-t-beam-s3-supreme)
does for the position, the clock, the battery and the orientation.

**Hardware-tested** on 2026-09-19 with an ESP32-D0WD-V3 and a Totem on firmware 5.0.3:

- the bond completed through the normal Touch Crystal pairing;
- the Totem unicast its status to the emulator every second, and acknowledged every frame the
  emulator sent;
- a walk at 5 km/h and a drive at 50 km/h arrived with the position, speed, compass, heading of
  motion and clock the firmware expects, including the duplicate status a Totem sends once a
  peer is more than 30 m away;
- the bond came back by itself after the board rebooted.

On 2026-09-20, with the settings store and the `rx` command:

- the settings sector survived a power cycle: the name, the boot count and the bond came
  back, and the bonded peer was in the node before the radio heard anything;
- an injected locate request was answered, and relayed with the hop count stepped and the
  last-hop position replaced by the board's own;
- an injected Smart Group invitation was joined while pairing was open, and the board never
  transmitted a `(7,0)` host beacon.

## Layout

| Package | Role |
| --- | --- |
| `mesh` | codec for the peer `(0, cmd)`, locate `(2,0)` and Smart Group `(7,x)` frames, field by field as in [message format](/protocols/message-format#peer-frame-0-cmd). Tested against frames packed by CPython's `struct` with the firmware's own formats, and fuzzed. |
| `emulator` | the Totem itself: pairing handshake, radio windows, clock sync, locate reply and relay, Smart Group member. Pure Go that takes frames and the time, and returns frames to send, so it is tested on the host with scenario tests and a fuzz target. |
| `emulator` (sensors) | `SensorSource`, and a `Sim` that walks or drives a track, keeps an odometer, drains a battery and points a compass. |
| `emulator` (orientation) | `OrientationTracker`, the firmware's two-state upright-or-flat machine with its thresholds, dwell times and hold times. Host tested. |
| `gnss` | NMEA in, fixes out, for a board with a receiver. Plain Go over bytes nobody on this side chose, so it is tested and fuzzed on the host. |
| `cmd/totememu` | the firmware: radio setup, the ESP-NOW receive ring, the serial console. Builds only with TinyGo (`tinygo && (esp32 \|\| esp32s3)` build tags). |
| `cmd/totememu/ring` | the receive ring's C (`ring.h`) compiled for the host, so it can be tested and fuzzed. |
| `store` | the settings a reboot keeps — the name, the crystal colour and the bonds, as a Totem keeps `config.json` — as an append-only journal in one flash sector. Pure Go, so it is tested and fuzzed on the host. |
| `cmd/totememu` (flash) | that journal's backend: the board's own SPI flash, driven from IRAM with the cache off. One driver per chip — `flash_esp32.*` and `flash_esp32s3.*` — because the two gate their caches differently. |
| `cmd/totememu` (board) | the parts of a specific board: `board_esp32s3.go` for its buses and pin map, and `pmu_`, `gnss_`, `imu_` and `chip_` files for what is on them. |

## Build and flash

Two binaries: the firmware, built with TinyGo and flashed to the board, and `totemctl`, built
with the ordinary Go toolchain and run on your machine. Everything below that begins `totemctl`
needs the second one, so it is worth having first:

```bash
go build -o totemctl ./cmd/totemctl
```

Then the firmware:

```bash
tinygo flash -target esp32-generic -port /dev/cu.usbserial-0001 \
  -ldflags "-X main.owned=8c94df7b0478" ./cmd/totememu
```

`main.owned` lists the ESP-NOW (WiFi station) MACs of your own Totems, comma-separated. It is
the MAC that `totemctl info` shows. `main.name` sets the name other Totems display (default
`emu_totem_` plus the last four hex digits of the board's MAC, such as `emu_totem_abb0`).

To pair, put the Totem next to the board and hold its Touch Crystal until the pairing
animation starts (about 1.2 s). The emulator notices the Totem's bond request and pairs
back. Bonding needs **RSSI ≥ −25 dBm** on both sides, so the two must nearly touch. The board
keeps the bond in flash, so a reboot comes up still bonded; it also takes a bond back when a
Totem that kept it in `config.json` sends a status frame.

## The T-Beam S3 Supreme

The emulator also runs on a LILYGO T-Beam S3 Supreme, an ESP32-S3 board that has the parts a
Totem has. On it the position, the speed, the course, the clock, the battery and the
orientation are read from hardware instead of modelled. The heading waits on one command, and
the reason is worth reading: a magnetometer **is** fitted and it works — it is the field around
it that is not the Earth's, until `mag calibrate` measures the difference (see below).

```bash
tinygo flash -target esp32s3-generic -port /dev/cu.usbmodem2101 \
  -ldflags "-X main.owned=8c94df7b0478" ./cmd/totememu
```

The USB-C socket goes straight to the chip, so there is no bridge chip and **no button to
hold**: a 1200-baud open on the running firmware's port drops the board into the ROM's
USB-Serial/JTAG, which is what `tinygo flash` then talks to.

That same wiring is why `totemctl` opens the port with DTR and RTS **deasserted** on a port
whose USB vendor id is Espressif's `303A`. On a board with a bridge chip, DTR and RTS reach
the chip through the auto-reset circuit, which pulls EN low only when RTS is asserted and DTR
is not, so asserting both — the library default — leaves the board running. Inside the S3
there is no such circuit and RTS drives EN directly, so the port merely being open held the
chip in reset: three seconds of reading returned nothing, and with both lines deasserted the
same read returned the boot log and every line after it.

### What is read, and what is not

| Reading | Where it comes from |
| --- | --- |
| Position, speed, course, clock | GNSS receiver on UART1, NMEA parsed by the `gnss` package. Which receiver (the board ships with a MAX-M10S or an L76K) is asked at boot, not assumed: see [Hardware](/reference/hardware) |
| Battery, and whether a cell is fitted at all | AXP2101 power chip on the second I2C bus |
| Orientation | QMI8658 IMU on the SPI bus, through `OrientationTracker` |
| Heading | the console until `mag calibrate` is run, then the QMC6310 magnetometer (below) |

The magnetometer is a **QMC6310 at 0x3c**, the N variant; the vendor's map allows for a U at
0x1c or a QMC6309 at 0x7c, and neither of those acknowledges. It identifies itself, its
register map is a magnetometer's, and it measures — but what it measures on this bench is
**2.27 gauss**, against an Earth field of 0.25 to 0.65 anywhere on the surface.

The reading is the same to three digits on every boot — around (1.92, -1.20, 0.00) g — which
is what a *fixed* magnetic offset looks like: something on the board or mounted with it,
rather than anything moving nearby. That is ordinary, it is called hard iron, and it is
removed by turning the sensor through every orientation and taking the center of the box the
readings sweep out. It is what the firmware's own 2D and 3D calibration runs do. Until it has
been done a bearing from this part would be confidently wrong, so the board takes none and
says so in the log, and the heading stays on the console.

`mag calibrate` is that turn. It watches for twenty seconds, takes the extremes each axis
reaches, and the center of the box they sweep out is the offset — then the heading comes from
the magnetometer, tilt-compensated with the IMU's pitch and roll, and keeps coming until the
board is rebooted. **It needs someone to pick the board up and turn it over**, slowly, through
every face.

A turn that was not one is refused rather than believed, which is the part worth testing: on a
board left sitting on a bench the twenty seconds gathered 389 readings whose axes moved 0.023,
0.026 and 0.046 gauss, against a floor of 0.15, and the calibration was declined. The center
of a reading that never moved is just where it was pointing, and accepting it would leave the
heading exactly as wrong as before while the board stopped saying it had no compass.

Two things this cost, both worth knowing before trusting a reading from this part:

- **It was written off as absent first.** Read over a bus that had not yet been made reliable,
  0x1c and 0x7c returned nothing and 0x3c returned 0xff — which reads as "no magnetometer, and
  the thing at 0x3c is the display". All three conclusions were wrong. Absence is established
  by a write now, because a write is the only transaction whose NACK this driver reports.
- **A range that did not stick.** The vendor's reset is 0x80, a pause, then zero, and writing
  the range in place of that final zero left the register reading 0x00 — the part stayed on its
  default scale and every reading came out six times too small, with nothing downstream able to
  tell. The driver writes the range and then reads it back.

The power chip is the gate to everything else: it feeds the sensors (ALDO1), the sensor bus
itself (ALDO2) and the GNSS receiver (ALDO4), and LILYGO ship ALDO4 switched off. The sensors
also have to be power **cycled** rather than switched on, which is LILYGO's own conclusion for
this board — "in order to avoid bus occupation, during initialization, the SD card and QMC
sensor are powered off and restarted" — with a quarter second between.

An operator can still take any reading back by hand. `pos`, `heading`, `batt`, `flat` and
`clock` all work, and the ones that hardware also fills say in the log that they have stopped
being read from it, because [`Controls`](#console) means a command must not quietly do nothing.

### Three things in TinyGo that do not reach this board

Worth writing down, because each one looked like broken hardware:

- **The console reads nothing.** `machine.Serial` on the S3 is the USB Serial/JTAG controller,
  and its driver moves bytes out of the receive FIFO in exactly one place: `Buffered`. The
  interrupt handler only masks the interrupt, and `ReadByte` answers `(0, nil)` on an empty
  buffer rather than an error — so the ESP32's "read it and check `err`" reported success for a
  byte nobody typed, and fed the line reader NULs forever while the host's input sat unread.
- **A UART at 9600 baud runs at the wrong speed.** `UART.Configure` sets `CLKDIV` to
  `40000000/baud` and nothing else. The integer part of that register is twelve bits, and 4166
  does not fit in 4095, so the value lands wrapped. On the board that arrived as 154 bytes of
  `0x00` in a second — a line that reads as a break rather than as data. The driver now
  pre-divides the crystal the way ESP-IDF does.
- **I2C stops working after a transaction or two, silently.** Ten reads of the AXP2101's
  identity register returned 0x4a once and then 0xff nine times; ten reads of a status register
  holding 0x20 alternated 0x20, 0xff, 0x20, 0xff. Nothing in the driver resets the controller
  after a failure, so no amount of retrying recovers it — and a failed *read* is not even
  reported, because a NACK on a transaction ending in a read is dropped. Every transaction now
  runs `Configure` first, and with that the same twenty reads all came back correct.

The last of those is also why the `i2c` command identifies parts by a known register value
rather than sweeping addresses: a sweep asked whether an address acknowledged, a question this
driver cannot answer, and reported 112 devices on each bus — every address, including two
magnetometer variants at once and an IMU that is wired to SPI.

**Hardware-tested** on 2026-09-28 with a T-Beam S3 Supreme (ESP32-S3FN8, 8 MB flash, base MAC
`48:ca:43:5a:cd:14`):

- boots, and the console works both ways over USB-Serial/JTAG;
- ESP-NOW starts, and the radio receives: the `selftest` command counted 209 frames on the mesh
  channel in three seconds;
- the flash driver's self-test passes on its scratch sector — erase 13 ms, a 64-byte write
  141 µs, the ROM descriptor reading device 0xc84017 — and the settings survive a reboot, with
  the boot count and journal sequence both climbing;
- the AXP2101 identifies itself, reports no cell fitted, and brings up all three rails;
- the PCF8563 clock is ticking;
- the GNSS receiver sends NMEA that parses with nothing rejected, and reports no fix indoors:
  `$GNRMC,001655.00,V,,,,,,,290926,,,N,V*18`;
- the IMU identifies itself and reads gravity: (-0.827, 0.046, 0.541) g, a magnitude of 0.989;
- the magnetometer identifies itself and measures a field, of 2.27 gauss, which is why no
  heading is taken from it yet.

One thing to expect indoors: the odometer follows the receiver, and a receiver with four
satellites and fourteen metres of claimed accuracy reported 127 km/h and a position wandering
hundreds of metres. Movement is only counted when the receiver says it is moving and the step
is larger than the accuracy it claims — which took the bench drift from 890 m in three minutes
down, but cannot make a bad fix good. A real Totem's odometer has the same dependency.

The front panel is a button and nothing else here. LILYGO's map gives this board a button on
GPIO0 and lists no LED, and every pin it does use — so the LED a bare ESP32 module has on
GPIO2 is not driven on this one. A pin that looks free on the silkscreen is still somebody
else's to wire.

Not yet tested on this board: a bond with a real Totem. An unbonded Totem transmits nothing —
it unicasts to its bonded peers and broadcasts only while pairing — so there is nothing to hear
until a Touch Crystal is held next to the board, which is a physical step.

## Watching the mesh

`totemctl mesh` talks to the board over USB serial and decodes on the host, with the same
`mesh` package, every frame your Totem sends it:

```bash
totemctl mesh watch          # decoded frames and events until Ctrl-C
totemctl mesh watch --raw    # plus each frame's bytes
totemctl mesh watch --tx     # plus the frames the emulator sends
totemctl mesh watch --json   # one JSON object per frame, every field
totemctl mesh status         # the emulator and its peers
totemctl mesh pair           # wait for a bond while you hold the Touch Crystal
totemctl mesh clock          # give the board this computer's time
totemctl mesh send sos on    # any console command below
```

```text
14:10:14 ← 8c94df7b0478  -15 dBm  status "LCFs totem"  37.586700,-122.007362 ±1m alt 24m  azimuth 121° flat  batt 53% 3.81V  fw 5.0.3  up 20h59m0s  clock 14:10:15.100
```

The commands pick the only USB serial port with an ESP32 bridge chip (CP210x, CH34x, FTDI or
Espressif USB), or take `--port`. They open it with DTR and RTS asserted and leave them so: on
ESP32 boards the auto-reset circuit pulls EN low when RTS is set without DTR, so a monitor that
clears both on open (pyserial's `dtr=False, rts=False`) reboots the emulator. The commands
switch the console to JSON lines with `format json` and back to text when they exit. With
`--trace` they log every console line.

The ESP32 only receives frames addressed to itself or broadcast. Status frames your Totem
unicasts to its other peers do not reach it.

## Console

The UART console (115200 baud) logs with `log/slog` and takes commands. `tinygo monitor
-port <port>` shows it directly:

| Command | Effect |
| --- | --- |
| `pair` | open a 6 s pairing window, as a long hold does |
| `status` | this device and each peer: name, RSSI, last heard, position, battery |
| `pos <lat> <lon> [accuracy m]`, `pos off` | report a GNSS fix (latitude ±90, longitude ±180, accuracy 0-127 m, default 5), or none (the default) |
| `heading <deg>` | compass azimuth to report, 0-359; while a simulation runs it steers the track too, the way a Totem points where it is going |
| `sim still\|walk\|drive [bearing]`, `sim off` | run or stop the simulated hardware |
| `flat on\|off` | report the Totem lying down or upright |
| `batt <0-100> [charging]` | battery level |
| `clock <unix ms>` | set the wall clock (`totemctl mesh clock` sends this computer's). Between 2020 and 2038: a peer frame carries the time as an int32 of seconds, as the firmware does, and a clock outside that cannot be put on the air |
| `sos on\|off` | the SOS flag |
| `unbond <mac>` | delete a peer and send it the `(0,2)` notice |
| `log debug\|info\|warn\|error` | log level; `debug` logs every frame heard and sent, as hex |
| `format text\|json` | log lines as slog text or as JSON (what `totemctl mesh` uses) |
| `touch crystal\|power\|sos tap\|double\|triple\|hold [ms]` | make a gesture on an input |
| `leds` | what the ring and the crystal are doing |
| `color <name>` | the crystal's default colour, from the firmware's 13 |
| `power`, `power on\|off` | the power state, or switch the device off and on as the button held does |
| `ota [update]` | the last update, or run one |
| `rx <src mac> self\|all <rssi> <hex frame>` | feed the node a frame as though the radio had heard it, for the paths that need a second Totem |
| `store`, `store forget` | the saved settings and bonds, or forget them: the flash and the live bonds both, as a factory reset does |
| `flash` | check the flash driver on its scratch sector: erase, write, read back |
| `i2c` | read each part the board should carry and say whether it answers with the identity it should |
| `mag`, `mag calibrate` | the magnetic field, or a 20 s turn to measure the hard iron around it |
| `selftest` | count every 802.11 frame on channel 6 for 3 s, to check the receiver |
| `help` | list the commands |

The console is parsed by `emulator.ParseCommand`, which rejects values out of range (and
`NaN` or `Inf` coordinates) with a `bad command` warning rather than put them on the air. It is
fuzzed on the host.

## Simulated hardware

A Totem has a GNSS receiver, a magnetometer, a motion sensor and a power chip. On a board
without them the `emulator` package provides a `Sim` that behaves like one, so the emulator
reports what a Totem in someone's hand would:

```bash
totemctl mesh send pos 37.5868 -122.0074 3   # where the walk starts
totemctl mesh clock                          # the board has no clock of its own
totemctl mesh send sim walk 90               # walk east; drive is 50 km/h, still holds position
totemctl mesh send flat on                   # lying down: peers then expect status every second
totemctl mesh send batt 40                   # battery level, and "batt 40 charging"
```

```text
→ 8c94df7b0478  status "emu_totem_abb0"  37.586800,-122.002060 ±5m alt 12m 50km/h  azimuth 90° heading 89° upright  batt 94% 4.07V  fw 5.0.3  clock 15:30:35.142
```

The simulation moves the position along the bearing (a walk wanders, a drive holds its
course), keeps the odometer, derives the heading of motion from the last 10 m as
`get_heading_mot` does, drains the battery and reports satellites and a solution id.

**The clock matters for more than the display.** With one, the node holds wall-clock radio
windows and advertises the time to peers the way a Totem with a GNSS lock does
(`rtc_method` 1); without one it borrows a peer's clock and stays quiet about it
(`rtc_method` 2). A board that has just booted counts from 1970, so the node refuses any
clock before 2020 rather than push that at a peer whose own clock is not set.

`SensorSource` is the seam: `Sim` on a board with no sensors, and a board's own GNSS,
magnetometer, motion sensor and power chip where they exist. `Controls` is the other half
of it, the settings `pos`, `heading`, `flat`, `batt` and `clock` drive. Both the simulation
and the fixed reading take them, so the same console command works whichever is installed;
a source that reports real hardware and takes no settings says so instead of accepting the
command and changing nothing.

## The rest of the device

A Totem is more than its radio, and the emulator now models the rest of
it: what the ring and the crystal are doing, the three inputs, the power
state, and an update over WiFi. Each is grounded in the firmware where the
disassembly gives a number, and says so where it does not.

### The halo and the crystal

Sixty ring pixels (`RING_PX_COUNT`) and seven in the crystal
(`CRYSTAL_PX_COUNT`), the 13-colour palette from `project_data.Colors`
with the exact RGB values, and the animations the LED task plays as events
arrive: the pairing breathe, the fill when a peer bonds, the countdown
when one is deleted, the SOS blink, the demi-god flash, the white 30%
progress ring of a download (`PROGRESS_RGB`) and the orange fill of a
failure (`ERROR_RGB`). The charger going in replays the power-up ring, as
`power_conn_new` does once `v_in` has read high for three 100 ms samples
— a contact that bounces on the way into the socket does not set it off,
and neither does a poll rate, because the wait is 300 ms of clock rather
than a count of polls. It only goes on over a resting ring: plugging in
during an alarm, a pairing window or an update leaves those showing. At
rest the ring is the compass: a lit pixel, with
its neighbours feathered, pointing at the bonded Totem, in the colour that
peer was given when it bonded (`shuffle_bond_colors`).

Frame timings are the one thing the firmware keeps out of reach — they
live in undisassembled bytecode — so the ones here are chosen to look like
the device, at 25 ms a frame.

```text
leds
leds state="pairing, crystal teal, ring 60/60 lit, brightness 100%"
```

On a board with an APA106 ring, `emulator.LEDs().Ring()` is what to write
to it. On a stock dev board there is one LED, on GPIO2, and it follows the
crystal: enough to see a pairing breathe, an SOS blink, and the dark of a
device that has powered down.

### Touch and the buttons

The Touch Crystal and the power and SOS buttons all report the same
gestures — taps counted inside a window, and holds — and `compass` wires
each to a callback:

| Input | Gesture | What it does |
| --- | --- | --- |
| Touch Crystal | hold ~1.2 s | start pairing |
| Power | single tap | `toggle_brightness` |
| Power | double tap | `user_enable_ble` |
| Power | hold 800 ms | `device_off` |
| SOS | single tap | `sos_mute` — the alarm keeps going out, the blinking stops |
| SOS | hold 800 ms | `start_sos` |
| SOS | triple tap | `start_ota` |
| SOS | long hold 10 s | `compass_reset` (not emulated; the bonds stay) |

The recogniser takes edges, not gestures, so the same code serves a real
pin, a capacitive reading and the console. v5.0.3's 30 ms edge lockout is
there, and so is the wait before touch is enabled after a boot. A hold
fires when it matures, not when the finger lands, so a three-second hold
of the crystal opens its pairing window 1.2 s in and keeps it open for
the full six seconds.

A device that has been powered down answers one gesture — the power
button held, which turns it back on — and its strip stays dark: on a
board whose LED follows the crystal, switching it off switches the light
off.

```bash
totemctl mesh send touch crystal hold 1500   # pair, as a finger would
totemctl mesh send touch sos hold 900        # start the alarm
totemctl mesh send touch sos tap             # mute it
```

The BOOT button on GPIO0 is wired to the SOS button, so those gestures can
also be made by hand.

### Power

The battery curve is `get_batt_pct`'s own breakpoint table, decoded from
the 232-byte constant in `peripherals.py`: 58 pairs of millivolts and a
raw level, from 4120 mV down to 3190, with the percentage taken as
`(raw*1000//605 + 5)//10`. So 4.12 V reads 100%, 4.0 V reads 86% and
3.8 V reads 50%, and anything above 4.12 V reads full — a Totem on its
charger reports 4.48 V at 100%.

The learned maximum (`config.batt_max_volts`) rescales a reading only
when it is *below* the table's top, lifting it so a pack that no longer
reaches 4.12 V still reads full at its own ceiling; above the top there
is no rescale at all. It is learned the way `one_min_coro` learns it:
only while charging, and only once the peak stops rising, stored as that
peak less 0.04 V.

The mode follows the battery — normal, eco, low below 3.45 V — and below
3.15 V the device powers itself down rather than brown out, which a peer
sees as the status frames stopping. That is a different number from the
one the gauge reaches zero at: the table's flat end is 3.19 V, so a
Totem reports 0% for a stretch and keeps running. A pack on the charger
never hits the cutoff, however flat it reads. The mode is not settable by hand, because the next battery
reading five milliseconds later would undo it: change the battery with
`batt` instead. Light sleep is accounted the way the firmware logs it,
including the two reasons it stays awake: a radio window about to open,
and a clock sync that has not finished. The watchdog model is
`wdt_manager`'s: the feed loop runs only while no blocker is held, and a
flash write holds `vfs write`.

The sleep is accounted, not taken: the board stays awake. A Totem light-sleeps between
radio windows and still keeps its link, and the board could do the same, but the counter is
what a peer can see the effect of — the mode in a status frame, and a device that has
powered down going quiet. Powering down is the emulator's deep sleep: the radio windows
stop, frames are no longer answered, and only a held power button brings it back.

### WiFi OTA

The update client runs the firmware's exchange against
`api.totemportal.com`: POST the release poll, GET `contents.json`, pick the
`.bin` (or the `.tgz` for a preview), read the version out of the name
between `_v` and the extension, download it with the progress ring
running. A device that has switched itself off is refused first — there is
no rebooting a device that has already stopped — and then the battery
gate, as `Battery too low for OTA update` does. A board wired without a
power chip is exempt, but only if it was built with `NoPowerChip` — never
because it happens to read zeroes. A reading of 0 V and 0% is also what a
dead cell and a failed ADC report, and those two are exactly what the gate
is for, so the flag is written the way round where forgetting it keeps the
gate on.

The emulator stops before writing a slot: it has one image, and losing it
would take the board off the mesh. Everything up to that point is real,
including the refusals — the exchange is plain HTTP with no key, no
signature and no TLS, so a release object with no `ota_url`, an index that
is not a JSON array, or a name with a path in it are all rejected rather
than followed. `FuzzOTAServer` covers exactly that.

```bash
totemctl mesh send ota update
ota failed err="ota: battery too low for an update: 20%"
```

## Settings that survive a reboot

A Totem keeps its name, its crystal colour and every bond in `config.json` on its
filesystem. The board has no filesystem, so the `store` package keeps the same things in one
4 KB flash sector as an append-only journal: a save appends a record, and only a full sector
costs an erase. Bonds go back into the node before the radio starts, so the emulator comes up
already bonded.

```text
settings restored name=emu_totem_abb0 peers=1 boots=3 seq=4 free=3816
bond restored mac=8c94df7b0478 name="LCFs totem"
```

A save happens when something a person changed is different from what is on the flash: a
bond gained or lost, the name, the crystal colour, the brightness, the SOS mute. The
counters the device keeps ride along with those rather than causing a write of their own,
because a counter that grows on its own would put a record on the flash every time anything
so much as looked at the settings.

Only the boot count comes back. The total light sleep and the highest cell voltage seen are
written as a snapshot of what the device last reported — `store` prints them — but not read
back, because the firmware keeps both in `modes`, whose constructor sets them to zero: they
start again at every boot, and a power cycle is a boot.

Everything read back is untrusted — a write cut short by a reset, a previous firmware, or
noise — so a record is believed only if its header and checksum agree, and a sector that
makes no sense boots with defaults rather than failing. `FuzzScan` covers exactly that.

Flashing the board erases the sector with the rest of the chip, so a reflash starts from
defaults; a power cut does not.

The driver underneath is the fiddly part, because on the ESP32 the code itself runs from
flash through the MMU cache. Touching flash means turning that cache off, and while it is off
the CPU cannot fetch an instruction or a constant from flash — so the operations live in
IRAM, take every address they need as data, and each is its own function (a branch on an
operation number compiled into a jump table, which lives in flash, and the board jumped into
`0xbad00bad`). An erase takes about 51 ms with interrupts off, so the settings are written
only when a bond or a setting actually changed.

Two things about this board are worth knowing if you port it: its flash ships without block
protection but the ROM's erase still refuses anything past the `chip_size` in the ROM's own
descriptor, and the bootloader leaves that at 2 MB on a 4 MB part — so the sector sits just
under 2 MB rather than at the end of the chip.

## Injecting frames

Some paths need a second Totem: a locate relay, a Smart Group invitation. `rx` feeds the node
a frame as though the radio had heard it, so they can be exercised on the board itself:

```bash
totemctl mesh send rx 8c94df7b0478 all -70 a7740200...   # a locate request from your Totem
totemctl mesh send rx 8c94df7b0478 self -20 a7740000...  # a status frame, unicast to the board
```

An injected frame is not a way around the rules. It goes to the same parser, the same
duplicate check and the same scope test as one off the air: a frame whose source is not one
of your Totems is dropped, and what the board sends in answer still has to pass `allowedTX`.

## Radio setup

`espradio` starts the WiFi station, and the firmware then applies the Totem's settings from
`EspConn.power_on` through the WiFi blob functions that `espradio` links but does not wrap:
`esp_wifi_set_protocol(STA, WIFI_PROTOCOL_LR)`, `esp_wifi_set_channel(6)`,
`esp_wifi_set_max_tx_power(84)` (21 dBm) and `esp_wifi_config_espnow_rate(STA,
WIFI_PHY_RATE_LORA_250K)`. The send reports confirm rate `0x29`.

<Warning>
`espradio` v0.3.0's ESP-NOW receive trampoline passes nine arguments to Go, and clang
adjusts the stack around that call with `MOVSP`. When the Go side has spilled the caller's
register window, the `MOVSP` raises `AllocaCause` (EXCCAUSE 5). TinyGo's ESP32 exception vector
treats that as fatal; ESP-IDF handles it in `_xt_alloca_exc`. The board crashed this way about
12 s after the first bond (`EXC 00000005 401906e4 …`). The firmware therefore registers its own
receive callback. That callback only copies each frame into a ring buffer, without calling Go
from the WiFi task, and the main loop drains the buffer every 5 ms. The UART receive interrupt
also stops firing once the WiFi blob runs, so the console polls the UART FIFO.
</Warning>

## Untrusted input

Everything that reaches the emulator from outside is fuzzed, and the fuzz targets run in CI:

| Input | Where | Target |
| --- | --- | --- |
| ESP-NOW frames off the air | `mesh.Parse` | `FuzzParse`, `FuzzHalf` |
| Frames, signal strength and timing into the device logic | `emulator.Node` | `FuzzNode`, which also interleaves console commands |
| Console command text | `emulator.ParseCommand` | `FuzzParseCommand` |
| Raw serial bytes | `emulator.LineReader` | `FuzzLineReader` |
| The board's own output, read by the CLI | `totemctl mesh` | `FuzzConsoleLine` |
| Frames arriving in the C receive ring | `cmd/totememu/ring.h` | `FuzzRing`, which compiles the same header for the host |
| What a flash sector holds after a reset, a previous firmware or a wild write | `store.Open` | `FuzzScan` |
| A saved settings record | `store.State` | `FuzzStateDecode` |
| A settings record put back into a live node — bonds, coordinates, colours and a timestamp | `emulator.Node.Restore` | `FuzzRestore` |
| What an update server answers, over plain HTTP | `emulator` OTA client | `FuzzOTAServer` |
| Edges from a bouncing pin or a jittering touch reading | `emulator` input recogniser | `FuzzInput` |
| Animations, dials and jumps in time | `emulator.LEDs` | `FuzzLEDs` |

## Scope

The emulator only listens to and talks to the Totems in `main.owned`:

- Frames from any other sender are dropped unread.
- Unicasts go only to owned Totems. `emulator` checks every outgoing frame in one place, and
  the tests assert this for every frame.
- It relays only locate frames that an owned Totem originated. **This is the one place the
  emulator knowingly does less than the firmware.** A Totem relays a locate frame from any
  origin and sheds it only under load, past a budget, too close to the last hop, or outside
  its node slots; see [the relay rules](/protocols/espnow-mesh#locate-requests--relay).
  Refusing them outright means the board never transmits on behalf of a device its owner
  does not own, which near other people's Totems is the difference between joining their
  mesh and staying out of it.

  `Config.RelayUnowned` turns the firmware's behaviour on, off by default. It opens the
  locate path — and only the locate path — to senders outside `owned`, and applies the two
  budgets the firmware applies there (20 requests, 10 replies). Peer, Smart Group and
  demi-god frames from an unowned sender are still dropped unread either way, and unicasts
  still only go to owned Totems. What it does not model, because a board sitting beside one
  Totem cannot reach any of it: `is_rx_overloaded`, the `load_fps`/`pending_tx` pair, and
  the node slots, which need six or more nearby nodes before they shed anything.
- It never hosts a Smart Group, because a host's finalize makes every member delete its
  existing peers.
- It never sends demi-god commands.

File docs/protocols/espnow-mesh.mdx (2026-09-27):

---
title: "ESP-NOW mesh (Unity Mesh)"
description: "The Totem-to-Totem 2.4 GHz protocol: framing, bonding, peer sync, and relay."
---

The **Unity Mesh Network** is Totem-to-Totem communication built on **ESP-NOW** —
Espressif's connectionless 2.4 GHz protocol that sends frames directly to a peer MAC
without an access point. Implemented in `espnow.py`, `espnow_conn_v2.py`,
`espnow_msg.py`, `aioespnow.py`, and the `peer_*` modules.

## Why ESP-NOW

- **No infrastructure**: works anywhere, no WiFi network or internet.
- **Low latency, low power**: short frames, radio can sleep between them.
- **Direct + broadcast**: unicast to a bonded peer, or broadcast for discovery and
  [demi-god](/protocols/demigod) commands.

## Application frame

Every ESP-NOW frame — unicast and broadcast alike — begins with a fixed 2-byte
**SyncWord** followed by a category/command header, then a payload whose layout is
selected by the `(cat_id, cmd_id)` pair (see [message format](/protocols/message-format)).

```text
byte   0    1    2      3       4 .. N
      +----+----+------+-------+-----------------------------+
      | A7 | 74 |cat_id|cmd_id | payload (per (cat,cmd) map) |
      +----+----+------+-------+-----------------------------+
       SyncWord  \_____ 2B ____/
```

| Field | Offset | Value | Grade |
| --- | --- | --- | --- |
| SyncWord | `[0:2]` | bytes `0xA7 0x74` (on the wire: `0xA7` then `0x74`) | Confirmed |
| `cat_id` | `[2]` | uint8 category | Confirmed |
| `cmd_id` | `[3]` | uint8 command | Confirmed |
| payload | `[4:]` | struct selected by `(cat_id, cmd_id)` | Confirmed |

**Validation is SyncWord match + length only — there is no CRC or checksum on the ESP-NOW
frame.** There is no in-band length field: the receiver uses the ESP-NOW MAC frame length
plus the expected struct size. The checks, in order (**Confirmed**, `EspConn.recv` at
`espnow_conn_v2.dis:6560-6890` and `Parser.aread` at `:7444-7650`):

1. The driver must have handed up both a MAC and a payload, and the MAC must be in
   `e.peers_table` — MicroPython's ESP-NOW module puts every sender there on receipt, and it
   is also where the per-frame **RSSI** comes from (`peers_table[mac][0]`).
2. `len(frame) >= 4` and `frame[0:2] == b'\xa7\x74'`, else
   `Invalid ESP-NOW message SyncWord or length`.
3. `(cat_id, cmd_id)` must be a key of `TOTEM_MSG_MAP`, else
   `Unknown Message` with `body` `x{:02x},x{:02x}`.
4. `struct.unpack(fmt, frame[2:calcsize(fmt)+2])` — the slice is exactly sized, so a frame
   shorter than `calcsize(fmt) + 2` raises inside the parser task rather than being rejected
   politely. This is the "length check": there is no upper bound, and trailing bytes are
   ignored.

`recv` also drops some frames before step 3:

| Dropped | Condition |
| --- | --- |
| `(2,0)` | `len(frame) <= 23`, or `gnss_data.location` is `None` |
| `(2,1)` | always |
| `(5,0)` | always (the unused chat category) |

`(2,0)` frames that pass never reach `aread` at all: `recv` calls `handle_mesh_msg` and
`Parser.compass_mesh` inline, each wrapped in `try/except Exception` (`Could not parse mesh`,
`Mesh processing failed`). Everything else is dispatched to `parser.aread` as a task.

<Note>
Both `Invalid Checksum value for: {}` and
`Invalid payload size for: {} | expected: {}, received: {} | Total Errs: {} / {}` belong to
the u-blox UBX GNSS parser (`ubx_gnss`, a Fletcher CK_A/CK_B check), **not** the ESP-NOW path
— the only validation log the ESP-NOW module (`espnow_conn_v2`) emits is
`Invalid ESP-NOW message SyncWord or length`. A custom ESP-NOW client computes no checksum —
prepend `0xA7 0x74`, set `cat_id`/`cmd_id`, and append the payload.
</Note>

## Channel

The mesh operates on a fixed **home channel — channel 6** (`self.channel = 6`, hardcoded in
`espnow_conn_v2.__init__`; the only write to `self.channel` in the module — Confirmed). A peer
on a different channel is rejected outright:

```text
Peer channel is not equal to the home channel, send fail!
Peer channel is not support, need to change channel
```

WiFi and BLE coexist with the mesh on this one radio — the firmware exposes combined
run-modes (`MODE_ESP_NOW_WIFI`, `MODE_ESP_NOW_WIFI_BLE`) so ESP-NOW runs alongside them
rather than being switched off. Because every peer must stay on the shared home channel,
any WiFi activity that retunes the radio to another channel (for example a WiFi firmware
download) would interrupt mesh delivery until the radio returns to the home channel.

## Long-range PHY

The mesh always runs on **Espressif Long Range** (`WIFI_PROTOCOL_LR`, protocol bitmap `0x08`,
LR only). `EspConn.check_mode` knows three `(pm, protocol)` pairs, and v5.0.3 only uses the
two LR ones: mode 0 `(PM_NONE, LR)` for ESP-NOW alone, and mode 2 `(PM_PERFORMANCE, LR)`
while BLE is active. Mode 1 (802.11 b/g/n) has no callers. A non-Espressif NIC, or an ESP32
not put into LR mode, therefore **cannot** exchange frames with a Totem: a client must be an
Espressif device configured with `WIFI_PROTOCOL_LR` on channel 6. `power_on` also sets
`txpower=21` (dBm; the driver caps it at 20).

The LR data rate is set on the ESP-NOW object, not via `wlan.config(lorate=...)`:
`EspConn.power_on` and `EspConn.recover` both call `self.e.config(rate=41)`, and 41 = `0x29` =
`WIFI_PHY_RATE_LORA_250K`. `power_on` also sets `self.e.config(rxbuf=3072)` before activating
the radio. v5.0.3's WiFi-kick path re-applies the rate after restarting the driver.
A client should use **LR 250K** to match. *(PHY and rate: Confirmed in v5.0.2 and v5.0.3, and
on hardware: an ESP32 set up this way bonds with a 5.0.3 Totem, see
[ESP32 emulator](/reference/esp32-emulator). Earlier versions of this page said the IDF
default of 500K applied; that was wrong.)*

## Peers & bonding

"Bonding" here is a **Totem-to-Totem** relationship (distinct from BLE bonding with the
phone). A bonded set of Totems is a friend group that syncs positions.

| Concept | Symbols / logs |
| --- | --- |
| Peer registry | `config.peers` (keyed by the peer's MAC as 12 lowercase hex digits, saved to `config.json`), `peer_management.py`; `add_new_bond` is the phone (BLE) path for adding a peer or point of interest |
| P2P pairing | `start_pairing`, `pair_nearby`, `Register sender as peer to bond to`, `Bonding to Peer`, `Deleting Peer with failed bond: {}` |
| Auto-bond (Smart Group) | `start_smart_group`, `Autobonding to Peers`, `auto_bond_timeout`, `auto_bond_client_timeout`, `Abandoning auto-bond group` |
| Promo bond | `[create_promo_bond] Created Bond!`, `Peer already exists` (a local point of interest, not over the air) |
| Re-bond | `Already a Peer, allow re-bonding`, `Both devices already bonded` |
| Proximity gate | `BONDING_RSSI` = `-25` dBm, `SMART_GROUP_RSSI` = `-45` dBm, `PEER_CHECK_RSSI` = `-3` — Confirmed |
| Saved fields | `_PEER_BLACKLIST`: the volatile `Peer` attributes (`last_msg`, `msg_rx`, `mesh_next_msg`, …) left out of `config.json`, not a list of blocked MACs |
| Limits | ESP-NOW peer table capped at the C-module limits `MAX_TOTAL_PEER_NUM` / `MAX_ENCRYPT_PEER_NUM`; the frozen-Python guard rejects when `len(peers) > modes.max_peers` (9, `Max ESP-NOW peers reached`). Bonds capped by `max_bonds`, default **8** (`Cannot have more than {} bonds`) — Confirmed |

Bonding events drive LED animations: `anim_add_peer`, `anim_bonding_ctdwn`
(countdown), `anim_peer_del_ctdwn`, `add_peer_animation`.

### Pairing (P2P bond)

The normal bond between two Totems is a handshake of **category 0, command 1** peer frames
(the same 108-byte frame as the [peer status](#peer-status-and-radio-windows), see
[message format](/protocols/message-format#peer-frame-0-cmd)). It is **Confirmed** from the
bytecode (`Compass.start_pairing`, `Compass.pair_nearby`, `Parser._peer`) and on hardware.

**Trigger.** A long hold on the Touch Crystal. `TouchButton` defines the three thresholds —
`_short_hold_ms = 360`, `_long_hold_ms = 1200`, `_ex_hold_hold_ms = 7200`
(`touch_button_v2.dis:293-301`) — and `Compass.touch_button_cb`, for touch features 1 and 3,
binds `cb_short_hold` to `start_bonding_countdown`, `cb_long_hold` to `start_pairing` and
`cb_ex_long_hold` to `start_smart_group` (it re-asserts `set_long_hold_ms(1200)` first; the
peer-management feature 2 raises it to 3000 instead). The owners of both Totems hold them
within the same few seconds. `start_pairing` refuses while a Smart Group is active or when
the Totem already has `max_bonds` (8) peers, and it opens a **6 s** window: the signature is
`start_pairing(is_init=True, timeout_sec=6)` and the body is
`asyncio.wait_for(pair_nearby(), timeout_sec)` (`compass.dis:1194-1199`). A timeout logs
`Pairing Timed Out`. All **Confirmed**.

**Handshake.** While pairing, each Totem runs `pair_nearby`, which every `randrange(50, 100)` ms
sends:

1. a **broadcast** `gen_peer_msg(cmd_id=1, is_ack=0)` (ack byte at offset 18 = 0) until it has
   picked a partner, then
2. a **unicast** `gen_peer_msg(cmd_id=1, is_ack=1)` to that partner.

The receiver (`Parser._peer`) acts on a command-1 frame only while it is pairing itself and
only at **RSSI ≥ `BONDING_RSSI` (−25 dBm)**, i.e. with the two devices practically touching:

| Frame received | Condition | Action |
| --- | --- | --- |
| cmd 1, any ack | not pairing | ignored |
| cmd 1, any ack | RSSI < −25 | `RSSI too poor to bond: {}` |
| cmd 1, any ack | Smart Group heard < 1 s ago | `Skip P2P bonding when auto-bonding` |
| cmd 1, any ack | no partner yet, sender unknown | `Register sender as peer to bond to`: `add_peer(mac)`, new `Peer` (colour, crystal pixel, `mesh_grp`) in `config.peers`, `bond_mac = sender`, `temp_bond = sender` |
| cmd 1, any ack | sender already a peer, heard < 6 s ago | `Both devices already bonded`: **5 unicast ack-1 frames, 80 ms apart**, then `cb_already_bonded` |
| cmd 1, **ack 1** | `bond_mac == sender` | `Bonding to Peer`: bond complete, `temp_bond` cleared, add-peer animation |

When the window closes (`cancel_pairing`), a partner that never sent an ack-1 frame
(`temp_bond` still set) is deleted again: `Deleting Peer with failed bond: {}`. After a
completed first bond with the phone connected, the Totem runs `ble_first_bond_burst`:
`send_burst(interval_ms=300, burst_duration_ms=6000)`, so 20 frames over 6 s — **Confirmed**.

```mermaid
sequenceDiagram
  participant A as Totem A (pairing)
  participant B as Totem B (pairing)
  A->>B: broadcast (0,1) ack 0, every 50-99 ms
  B->>A: broadcast (0,1) ack 0
  Note over A,B: RSSI ≥ −25 dBm: each registers the other (bond_mac, temp_bond)
  A->>B: unicast (0,1) ack 1, every 50-99 ms until the 6 s window ends
  B->>A: unicast (0,1) ack 1
  Note over A,B: ack 1 from bond_mac: "Bonding to Peer", peer saved in config.json
  A->>B: unicast (0,0) status in every radio window
  B->>A: unicast (0,0) status
```

There are no keys and no challenge: the bond is the two entries in `config.peers`, keyed by the
ESP-NOW source MAC (the STA MAC, `machine.unique_id()`). The peer-frame `target_mac` field is
always zero in 5.0.3 and is never read. A `(0,2)` unbond notice is sent to a deleted peer, but
5.0.3 receivers ignore it.

### Smart Group (auto-bond)

A Smart Group bonds a whole group at once. It uses category 7 (see
[message format](/protocols/message-format#smart-group-beacon-70)):

1. The **host** (extra-long hold) picks `smart_grp_uid = randint(1, 65534)` and broadcasts a
   `(7,0)` beacon with instruction **1** every **333 ms** for up to **40 s**. The beacon carries
   the host's position, the group UID, the time left and the member list (MAC + position +
   colour per member). It does not carry RSSI: receivers measure it.
2. A **client** that is pairing and hears a beacon at **RSSI ≥ `SMART_GROUP_RSSI` (−45 dBm)**
   — or one whose `smart_grp_uid` already matches, at any RSSI — broadcasts a `(7,1)` join
   (join flag +1) twice, 200 ms apart (`Sent Smart Group join cmd`). The host adds it (up to
   `max_bonds`) and each join extends the window by up to 12 s. A client that finds its own
   MAC in the member list sets `smart_grp_uid` and waits.
3. The host finishes with instruction **3** (shuffled colours) or **−1** (abandon), each as a
   300 ms × 1.6 s `send_burst`. On instruction 3, every member runs
   `peer_management.auto_bond_to_peers`, which awaits `delete_all_peers()` — **every existing
   peer is deleted** — and then creates a fresh `Peer` for every other member, with the
   position and colour the beacon carried. Wrong-group frames are ignored (`Incorrect
   auto-bond group, ignore request`); a `−1` frame cancels on a UID match, or whenever the
   receiver is not in a group at all.

`Parser._smart_group` keeps a second, tighter RSSI mark: a beacon at **RSSI ≥ −35** (a
hardcoded literal, not `SMART_GROUP_RSSI`) also stamps `modes.smart_grp_last_nearby`, which
is how the Totem knows the host is still right next to it. **Confirmed**
(`espnow_conn_v2.dis:10118-10126`).

<Warning>
Hosting a Smart Group near other people's Totems can wipe their friend lists: a member that
accepts instruction 3 deletes every peer it had. Only host with Totems you own.
</Warning>

## Encryption — there is none

**All ESP-NOW traffic is cleartext — broadcast *and* unicast.** No PMK is ever
programmed and no LMK is ever set, so the ESP-NOW link layer runs entirely unencrypted.
This is confirmed, not inferred:

- The ROM ESP-NOW C-module exposes `set_pmk`, `lmk`, and `encrypt`, but those qstrs appear
  in **no frozen module's `qstr_table`** — no Python code ever references them.
- `add_peer(mac)` is always called with a single positional argument, so `lmk` defaults to
  `None` and `encrypt` defaults to `False`. The concept of ESP-NOW encryption exists in the
  ROM module but is never used.
- There is also **no application-layer authentication** on the ESP-NOW path — no token,
  HMAC, challenge/response, or signature.

<Warning>
There is no confidentiality or authenticity on the mesh. Any Espressif device on channel 6
in Long-Range mode can read every peer sync, position, and chat message and can inject
valid frames. The only gates are RSSI proximity (for bonding) and msg-UID de-duplication —
neither is a security control.
</Warning>

<Note>
The IDF strings `PMK is NULL`, `set lmk fail`, `Encryption Failed`, and
`Do not support encryption for multicast address` are the ESP-IDF ESP-NOW layer's own
messages; their presence in the image does **not** mean the app uses encryption. The app
never sets a PMK or LMK.
</Note>
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

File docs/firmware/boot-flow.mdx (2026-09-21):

---
title: "Boot & power states"
description: "From reset to the application main loop, and the device power modes."
---

## Boot sequence

```mermaid
flowchart TD
  A[ESP32 ROM] --> B[2nd-stage bootloader]
  B --> C{OTA data valid?}
  C -->|yes| D[boot selected OTA app slot]
  C -->|no / invalid| E[fall back to factory / previous]
  D --> F[MicroPython starts]
  F --> G[_boot.py: mount VFS via flashbdev]
  G --> H[inisetup.setup: first-run format if mount fails]
  H --> BP[boot.py: stock template, no-op]
  BP --> I[main.py: from ota_daemon import *]
  I --> OD[ota_daemon: firmware_rollback.cancel]
  OD --> PM[from project_main import *]
  PM --> RM[rtc_mem.reload, then start 1]
  RM --> K[asyncio.run main: start task set]
```

- The bootloader validates the appended image SHA-256 and the OTA-data partition,
  then jumps into the selected app slot. Failed or rolled-back updates land on the
  previous good slot (see [OTA](/subsystems/ota)).
- `_boot.py` mounts `bdev` at `/` through `flashbdev.py`, and on `OSError` falls back to
  `inisetup.setup()`, which formats LittleFS2 and writes `boot.py` and `main.py`.
- `boot.py` (a VFS file, distinct from the frozen `_boot.py`) is the unmodified
  MicroPython template and does nothing. Both the frozen `main.py` and the `main.py`
  `inisetup` writes to the VFS contain the same three lines.
- `main.py` is, in its entirety, `try: from ota_daemon import *` / `except ImportError: pass`.
- `ota_daemon.py` calls `f_lib.firmware_rollback.cancel()` — marking the running slot
  valid and cancelling rollback — then does `from project_main import *` inside a `try`
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

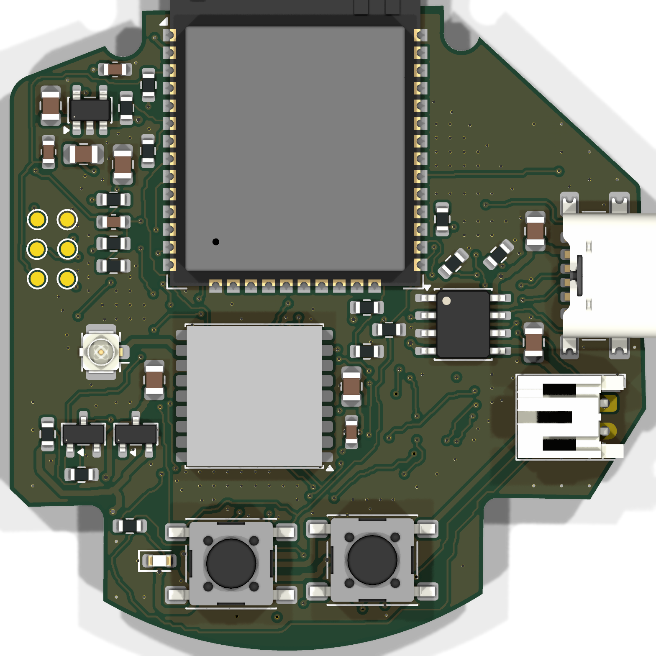
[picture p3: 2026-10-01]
hardware/totem-v3.5-reference/pcb/fab/render-top.png

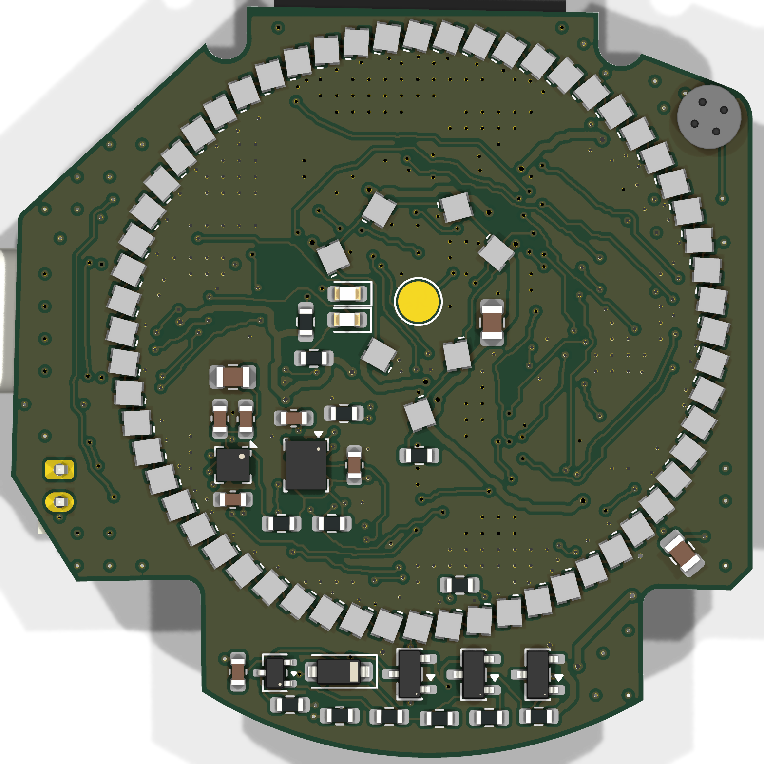
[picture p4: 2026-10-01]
hardware/totem-v3.5-reference/pcb/fab/render-bottom.png

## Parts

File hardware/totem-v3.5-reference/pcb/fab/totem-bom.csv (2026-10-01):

Comment | Designator | Footprint | Quantity | Side | Manufacturer | MPN | Note
100n | C1,C7,C12,C19,C21 | C_0603_1608Metric | 5 | Bottom | Samsung | CL10B104KB8NNNC | 0603 X7R 50 V
220n | C8 | C_0603_1608Metric | 1 | Bottom | Samsung | CL10B224KB8NNNC | 0603 X7R 50 V, low ESR: the LIS2MDL's set/reset capacitor
10u | C16,C17,C20 | C_0805_2012Metric | 3 | Bottom | Samsung | CL21A106KAYNNNE | 0805 X5R 25 V
1N4148W | D1 | D_SOD-123 | 1 | Bottom | Diodes Inc. | 1N4148W-7-F
BAT54W | D2 | SOT-323_SC-70 | 1 | Bottom | Diodes Inc. | BAT54W-7-F
red | D4 | LED_0603_1608Metric | 1 | Bottom | Lite-On | LTST-C191KRKT | 0603 red
green | D5 | LED_0603_1608Metric | 1 | Bottom | Lite-On | LTST-C191KGKT | 0603 green
XL-1515RGBC-WS2812B | D100,D101,D102,D103,D104,D105,D106,D107,D108,D109,D110,D111,D112,D113,D114,D115,D116,D117,D118,D119,D120,D121,D122,D123,D124,D125,D126,D127,D128,D129,D130,D131,D132,D133,D134,D135,D136,D137,D138,D139,D140,D141,D142,D143,D144,D145,D146,D147,D148,D149,D150,D151,D152,D153,D154,D155,D156,D157,D158,D159,D200,D201,D202,D203,D204,D205,D206 | LED_XL-1515RGBC-WS2812B | 67 | Bottom | XINGLIGHT | XL-1515RGBC-WS2812B | 1.5 x 1.5 mm addressable RGB; moisture sensitive, bake per datasheet
electret | MK1 | CUI_CMC-4013-SMT_RingGap | 1 | Bottom | Same Sky (CUI Devices) | CMC-4013-2-SMT-TR
AO3401A | Q1 | SOT-23 | 1 | Bottom | Alpha & Omega | AO3401A
2N7002 | Q2,Q3 | SOT-23 | 2 | Bottom | Nexperia | 2N7002,215
4.7k | R7,R8 | R_0603_1608Metric | 2 | Bottom | Yageo | RC0603FR-074K7L | 0603 1% 100 mW
33 | R11,R12 | R_0603_1608Metric | 2 | Bottom | Yageo | RC0603FR-0733RL | 0603 1% 100 mW
100k | R14,R18 | R_0603_1608Metric | 2 | Bottom | Yageo | RC0603FR-07100KL | 0603 1% 100 mW
10M | R15 | R_0603_1608Metric | 1 | Bottom | Yageo | RC0603FR-0710ML | 0603 1% 100 mW
1M | R16 | R_0603_1608Metric | 1 | Bottom | Yageo | RC0603FR-071ML | 0603 1% 100 mW
10k | R17,R19,R26 | R_0603_1608Metric | 3 | Bottom | Yageo | RC0603FR-0710KL | 0603 1% 100 mW
1k | R27,R28 | R_0603_1608Metric | 2 | Bottom | Yageo | RC0603FR-071KL | 0603 1% 100 mW
touch pogo pin | TP1 | TestPoint_Pad_D2.5mm | 1 | Bottom | - | - | SMT spring-loaded (pogo) pin on a 2.5 mm pad, length to suit the crystal; hand-fitted, see ASSEMBLY.md
LSM6DSV16X | U5 | LGA-14_3x2.5mm_P0.5mm_LayoutBorder3x4y | 1 | Bottom | STMicroelectronics | LSM6DSV16XTR | 6-axis IMU, LGA-14L; moisture sensitive
LIS2MDL | U6 | LGA-12_2x2mm_P0.5mm | 1 | Bottom | STMicroelectronics | LIS2MDLTR | 3-axis magnetometer, LGA-12; keep it clear of magnetised tools and parts
1u | C2,C18 | C_0603_1608Metric | 2 | Top | Samsung | CL10A105KB8NNNC | 0603 X5R 50 V
10u | C3,C5,C10,C11,C13,C14,C15 | C_0805_2012Metric | 7 | Top | Samsung | CL21A106KAYNNNE | 0805 X5R 25 V
100n | C4,C6 | C_0603_1608Metric | 2 | Top | Samsung | CL10B104KB8NNNC | 0603 X7R 50 V
red | D3 | LED_0603_1608Metric | 1 | Top | Lite-On | LTST-C191KRKT | 0603 red
USB4135-GF-A | J1 | USB_C_Receptacle_GCT_USB4135-GF-A_6P_TopMnt_Horizontal | 1 | Top | GCT | USB4135-GF-A | power-only USB-C, 6 pin
LiPo 1000mAh | J2 | JST_PH_S2B-PH-K_1x02_P2.00mm_Horizontal | 1 | Top | JST | S2B-PH-K-S(LF)(SN) | battery connector, THT side entry; the cell is off-board (totem-offboard.csv)
u.FL | J3 | U.FL_Hirose_U.FL-R-SMT-1_Vertical | 1 | Top | Hirose | U.FL-R-SMT-1(10) | GNSS antenna connector
AO3401A | Q4 | SOT-23 | 1 | Top | Alpha & Omega | AO3401A
2N7002 | Q5 | SOT-23 | 1 | Top | Nexperia | 2N7002,215
113k | R1 | R_0603_1608Metric | 1 | Top | Yageo | RT0603BRD07113KL | 0603 0.1% thin film: cell-sense divider
102k | R2 | R_0603_1608Metric | 1 | Top | Yageo | RT0603BRD07102KL | 0603 0.1% thin film: cell-sense divider
100k | R3,R9,R10,R24,R25 | R_0603_1608Metric | 5 | Top | Yageo | RC0603FR-07100KL | 0603 1% 100 mW
150k | R4 | R_0603_1608Metric | 1 | Top | Yageo | RC0603FR-07150KL | 0603 1% 100 mW
2k | R5 | R_0603_1608Metric | 1 | Top | Yageo | RC0603FR-072KL | 0603 1% 100 mW
330 | R6 | R_0603_1608Metric | 1 | Top | Yageo | RC0603FR-07330RL | 0603 1% 100 mW
10k | R13,R22 | R_0603_1608Metric | 2 | Top | Yageo | RC0603FR-0710KL | 0603 1% 100 mW
5.1k | R20,R21 | R_0603_1608Metric | 2 | Top | Yageo | RC0603FR-075K1L | 0603 1% 100 mW
2.2k | R23 | R_0603_1608Metric | 1 | Top | Yageo | RC0603FR-072K2L | 0603 1% 100 mW
power | SW1 | SW_SPST_PTS645Sx43SMTR92 | 1 | Top | C&K | PTS645SK95SMTR92 LFS | 6x6 SMD tact, 9.5 mm; stem length to be matched to the rear cover
SOS | SW2 | SW_SPST_PTS645Sx43SMTR92 | 1 | Top | C&K | PTS645SK95SMTR92 LFS | 6x6 SMD tact, 9.5 mm; stem length to be matched to the rear cover
ESP32-WROOM-32E | U1 | ESP32-WROOM-32E | 1 | Top | Espressif | ESP32-WROOM-32E-N4 | 4 MB flash, as the firmware image
MAX-M10S | U2 | ublox_MAX | 1 | Top | u-blox | MAX-M10S-00B | moisture sensitive, bake per u-blox before reflow
TP4056-42-ESOP8 | U3 | SOIC-8-1EP_3.9x4.9mm_P1.27mm_EP2.29x3mm | 1 | Top | NanJing Top Power | TP4056-42-ESOP8
AP2112K-3.3 | U4 | SOT-23-5 | 1 | Top | Diodes Inc. | AP2112K-3.3TRG1

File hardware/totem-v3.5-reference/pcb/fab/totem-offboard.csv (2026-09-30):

Item | Quantity | Specification | Note
Li-Po cell | 1 | 3.7 V 1000 mAh, 1S, with protection, JST PH 2.0 mm 2-pin plug | Check the plug's polarity against J2 before connecting: PH leads are not standardised
GNSS antenna | 1 | L1 1575.42 MHz, U.FL (IPEX MHF1) plug, passive patch or flex | The reference unit's antenna was not identified; its cable is visible in the photos
Programming adapter | 1 | 3.3 V USB-to-UART with DTR/RTS, pogo pins or wires to TP2-TP7 | The board has no USB data: see ASSEMBLY.md, Programming
Enclosure, crystal, rear cover | 1 | from the reference unit | Not part of this design

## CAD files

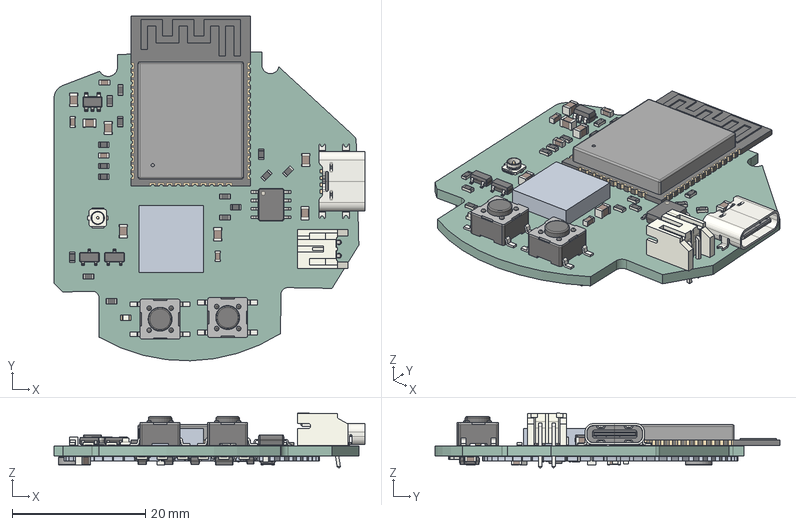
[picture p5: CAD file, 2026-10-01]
hardware/totem-v3.5-reference/pcb/fab/totem-v3.5.step
46.7 x 51.7 x 8.25 mm
R_0603_1608Metric x 28
C_0805_2012Metric x 10
ublox_MAX
SOIC-8-1EP_3.9x4.9mm_P1.27mm_EP2.29x3mm
JST_S2B_PH_K
SW_SPST_PTS645Sx43SMTR92 x 2
C_0603_1608Metric x 10
SOT-23 x 5
SOT-23-5
USB_C_Receptacle_6P_TopMnt_Horizontal_GCT_USB4135-GF-A
U.FL_Hirose_U.FL-R-SMT-1_Vertical
ESP32-WROOM-32E
LED_0603_1608Metric x 3
LED_XL-1515RGBC-WS2812B x 67
SOT-323_SC-70
LGA_14_3x25mm_P05mm_LayoutBorder3x4y
D_SOD-123
LGA_12_2x2mm_P05mm
CUI_CMC-4013-SMT
totem_PCB

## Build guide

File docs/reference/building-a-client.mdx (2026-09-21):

---
title: "Building a custom client"
description: "A practical reference for implementing your own client that talks to your own Totems over BLE, the ESP-NOW mesh, and a custom OTA server — no keys required."
---

This page collects everything a from-scratch client needs to talk to Totems you own:
the BLE GATT link the phone app uses, the ESP-NOW mesh frame, a drop-in OTA server, and
the chunked-transfer header. Every value here is verified against the recovered
`firmware_v5.0.3.bin` image (and unchanged from v5.0.2 unless marked). The BLE parts are
also tested on hardware. Confidence is graded **Confirmed** / **Inferred** / **Partial**
throughout.

## No cryptographic secrets are required

The single most important fact for a client author: **you need no keys, no pairing, no
signatures, and no shared secret** to interoperate. Nothing on the application path is
authenticated or encrypted (**Confirmed**).

| Path | Protection a client must handle |
| --- | --- |
| ESP-NOW (broadcast **and** unicast) | none — entirely cleartext, no PMK/LMK ever programmed |
| BLE GATT | none — no pairing/bonding/encryption; an unpaired central can read and write |
| Application messages (BLE + mesh) | none — no token, HMAC, challenge/response, or signature anywhere |
| OTA | integrity only — SHA-256 hash, **no** firmware signature, fetched over plain HTTP |

<Note>
  The ESP-NOW ROM module *contains* the concept of encryption (`set_pmk`, `lmk`,
  `encrypt`), but no frozen Python module references those symbols, and `add_peer(mac)` is
  always called with a single positional argument, so `lmk=None` and `encrypt=False`. The
  only crypto in the image is the bundled (and, on the app path, unused) mbedTLS stack plus
  the OTA SHA-256. `ble_keys.bin` holds optional BLE reconnect secrets — not required to
  connect.

  On the BLE side this is checkable directly: `BleLite.enable` calls `ble.active(True)` and
  nothing else, and the **only** `ble.config()` call anywhere in the 94 frozen modules is
  `ota_ble`'s `mtu=512` — no `bond`, `mitm`, `le_secure` or `io` option is ever set, and the
  IRQ handler has no encryption or passkey branch (**Confirmed**).
</Note>

## BLE client

The Totem is a BLE **peripheral**; your client is the **central**. No pairing is required.
A working reference implementation in Go, `totemctl`, lives in this repository
(`protocol/`, `client/`, `cmd/totemctl/`). It has been verified against a real device on
firmware 4.1.3 and 5.0.3.

### Connect

Bluetooth is off until the user **double-presses the power button**; the crystal breathes
blue while it advertises. The primary advertisement carries the flags, the 128-bit service
UUID and the local name `totem`; the appearance spills into the **scan response**, so a
passive scan sees the name and UUID but not the appearance (**Confirmed** — see
[advertising](/protocols/ble#advertising)). Advertising interval is 50 ms.

| Item | Value |
| --- | --- |
| Service UUID | `7913b588-0000-4635-b066-baa2cfc197cf` |
| Advertised name | `totem` (appearance 1361, in the scan response) |
| Pairing / bonding | not required |

`ble_core.py` registers these characteristics under the service, all with GATT flags
`0x3E` (READ | WRITE | WRITE_NO_RESP | NOTIFY | INDICATE):

| Characteristic UUID | Name | Role | Value buffer |
| --- | --- | --- | --- |
| `7913b588-0001-4635-b066-baa2cfc197cf` | `chars__conn_status` | control / handshake: the client writes here, and the device announces handoffs and disconnects here | **84** B |
| `7913b588-0002-4635-b066-baa2cfc197cf` | `chars__data_transfer` | application data | **185** B |
| `7913b588-0003-4635-b066-baa2cfc197cf` | `chars__on_demand` | **v5.0.3+ only**: file-upload chunks, used only if the client announced upload support | device → client only |

Direction is fixed: **client → device is a GATT write**; **device → client is
notify/indicate** (on connection handle 0 — the firmware passes a literal `0` to both
`gatts_notify` and `gatts_indicate`, so it only ever serves one central). Subscribe to
**both** `…-0001` and `…-0002`; a single write must fit the target characteristic's value
buffer above, whatever the MTU (**Confirmed**, `ble_manager.dis:4308-4400`).

<Warning>
  **Do not poll with GATT reads.** `Characteristic.write` only ever calls
  `gatts_notify(0, handle, data)` — the `gatts_write` branch that would update the readable
  attribute value is unreachable in this build. The characteristic you read back is
  whatever *you* last wrote. All device data arrives as notifications or indications
  (**Confirmed**, `f_ble_ble_data.dis:528-563`).
</Warning>

MTU is client-negotiated: the device never calls `gattc_exchange_mtu` and sets no preferred
MTU on the app path, so it starts at 23 and adopts whatever `_IRQ_MTU_EXCHANGED` reports
(**Confirmed**). macOS negotiates 256 (observed on hardware, not derivable from the image).

Right after connecting the device asks for a 10–20 ms connection interval, slave latency 0
and a 12 s supervision timeout via `gap_conn_param_update(0, 10000, 20000, 0, 12000)`.

### Handshake (ConnStatus-Ready)

<Steps>
  <Step title="Subscribe">
    Enable notifications on `…-0002` and `…-0001`.
  </Step>
  <Step title="Report app state (optional)">
    Write `[0x03, 0x00, bits]` to `…-0001`: bit0 isActive, bit1 isFocused, bit2 isLocked,
    bit3 isUiClosed, bit4 isService, bit5 lets the device drop BLE on its own schedule.
  </Step>
  <Step title="Write the Ready frame">
    Write `[0x00, 0x01, 0x01, 0x00]` to `…-0001` **within 15 s** of connecting (v5.0.3
    schedules a disconnect for silent links). A last byte of `0x00` selects the **legacy
    full-duplex** transmit loop, which works on every platform. A nonzero `frame_schema_id`
    selects the half-duplex loop, which
    [stalls on macOS/iOS](/protocols/ble#transmit-modes). v5.0.3 accepts an optional 5th
    byte whose bit 0 announces file-upload support; leave it out unless you implement uploads.
  </Step>
  <Step title="Request and acknowledge records">
    Write `(0x01, 0x01)` to `…-0002` to request Static Data. In the legacy loop the device
    repeats Static Data, the WiFi list and Peer Sync until you acknowledge them with
    `(0x01, 0x00)`, `(0x02, 0x00)` and a cat-6 command such as `(0x06, 0x08)` — any command
    in the category clears its pending flag, because `recv_data_msgs` just assigns
    `controller.<cat>_cmd_id = cmd_id`. **Peer Sync is pending from the start**
    (`Controller.__init__` leaves `peer_cmd_id = 1`), but the device withholds it until
    Static Data has been acknowledged (`Static data not yet sent, skipping BLE Peer Sync`).
    Live Data then arrives every ~3 s, and Peer Pings whenever a peer changes — one per loop
    pass, and only while the last Live Data was under 10 s ago. Read them with the `gen_*`
    layouts below.
  </Step>
  <Step title="Send commands, then disconnect">
    Write commands to `…-0002` at any time; the full list is in the
    [command map](/protocols/message-format#categories). To disconnect gracefully, write
    `[0x00, 0x03]` to `…-0001` — that sets `is_graceful_disconn`, so the device does *not*
    auto-reconnect afterwards. Drop the link without it and the device silently re-advertises
    for 45 s.
  </Step>
</Steps>

<Info>
  `recv_status_msgs` applies these gates (**Confirmed**, `ble_manager.dis:2753-3119`):
  `conn_mode == 1` clears pending static/peer requests; `frame_schema_id > 0` sets TX ready
  and makes the legacy loop exit in favour of `send_data_v2`; TX **owner** is set only when
  both hold — the `evt_is_tx_owner.set()` lives inside the `frame_schema_id > 0` branch.
  A short frame is not an error: `conn_mode` and `frame_schema_id` default to `0` when the
  write is under 3 or 4 bytes, and `is_upload_supported` to `0` under 5. The ids
  **25, 45, 59, 72** are real `EXTENDED` schema variants, but no BLE record layout depends
  on the schema id. In the half-duplex loop the device waits for the ATT confirmation of
  every indication (500 ms timeout), hands TX to the app with a 12-byte
  `[0x04, 0x02, 0x02] + 00×9` **indication** on `…-0001`, and expects `[0x04, 0x03, 0x02]`
  (bit 1) to take it back; `[0x04, 0x03, 0x01]` (bit 0) revokes it instead. See
  [Half-duplex & comms handoff](/protocols/ble#half-duplex--comms-handoff).
</Info>

### Keeping the link alive

The device watches `controller.status__conn`. If it is anything but `1` for **15 s** it
counts a stall, logs `App never sent ConnStatus within {} ms - link treated as hung`, and
raises `evt_ble_schedule_disconn`; the scheduled-disconnect manager then drops the link and
parks BLE for 30 s (90 s, and with no fast-reconnect bursts, after two hung links in a row).
Sending the Ready frame promptly is the whole fix. (**Confirmed**,
`ble_manager.dis:3840-3890` and `compass.dis:5747-6039`.)

Before it goes away the device announces its intent on `…-0001`, **three times, 50 ms
apart**, as a 10-byte frame (**Confirmed**, `ble_manager.dis:4934-5084`):

| Frame | Meaning |
| --- | --- |
| `[0x00, 0x02]` + `00×8` | plain disconnect |
| `[0x00, 0x05]` + `<ii` | scheduled: `(reconn_start_ms, reconn_duration_ms)` — reconnect in N ms, advertising for M ms (M ≥ 10 000) |

A client that handles `[0x00, 0x05]` can schedule its own rescan instead of hunting blind.
During the off window the device also advertises a connectable **1.2 s burst every ~8 s**,
so a client that keeps scanning will usually reconnect before the window ends.

Setting bit 5 of the app-runtime byte (`[0x03, 0x00, bits]`) is what *permits* the routine
version of this cycle: `espnow_conn_v2` only requests a scheduled disconnect when
`modes.is_ble_auto_reconn` is set **and** the app has reported itself inactive (bit 0 clear)
for more than 10 s (`[ESP-NOW] | App allows BLE Auto Reconnect` → `[ESP-NOW] | Requesting
BLE Scheduled Disconnect`). Leave bit 5 clear and the device stays connected — the 15 s
hung-link guard is the only other thing that raises the event (**Confirmed**,
`espnow_conn_v2.dis:3030-3160`).

### Messages to read (BLE `gen_*` layouts)

<Warning>
  The BLE GATT layouts are **not** the ESP-NOW layouts. The same `(cat_id, cmd_id)` key is
  reused by two transports with different struct layouts — for example BLE `gen_live_data`
  `(0x03,0x01)` is a 69-byte record, while `TOTEM_MSG_MAP (3,1)` is 20 bytes. A BLE client
  must use the `gen_*` layouts here; a mesh client must use the [mesh map](#esp-now-mesh-client).
</Warning>

All BLE records prefix `buff[0:2] = (cat_id, cmd_id)`. **Confirmed** layouts:

**Live Data `(0x03, 0x01)`** — `gen_live_data`, `struct <bfi3fb4Bi3b2hbiffb3ibHBBb` at
offset 2 (69 B). Fields in order:

| # | code | Field |
| --- | --- | --- |
| 1 | `b` | sat_count |
| 2 | `f` | p_acc, m (−1 = None) |
| 3 | `i` | altitude, m (−500 = None) |
| 4 | `f` | latitude, ° |
| 5 | `f` | longitude, ° |
| 6 | `f` | batt_volts, V |
| 7 | `b` | esp-now channel |
| 8 | `B` | power_bits (power_mode in bits 0-2) |
| 9 | `B` | max_hop_cnt |
| 10 | `B` | mesh_rx |
| 11 | `B` | mesh_relayed |
| 12 | `i` | unix_ts, s |
| 13 | `b` | color_id |
| 14 | `b` | orientation |
| 15 | `b` | solution_id |
| 16 | `h` | heading, ° |
| 17 | `h` | azimuth, ° |
| 18 | `b` | speed (cap 127, −1 = None) |
| 19 | `i` | odometer |
| 20-21 | `ff` | reserved ×2 (always 0) |
| 22 | `b` | reserved (always −1) |
| 23 | `i` | uptime, s |
| 24 | `i` | age |
| 25 | `i` | reserved (always 0) |
| 26 | `b` | power_level: battery health, 2 = low |
| 27 | `H` | reserved (always 0) |
| 28 | `B` | flags |
| 29 | `B` | reserved (always 0) |
| 30 | `b` | batt_pct |

The `flags` byte (field 28) is `pack_flags(is_sos, is_eco, led_brt ≥ GLOBAL_BRT,
gnss_location_set, power_level == 2, is_charging, 0, is_mag_cal_needed)`: bit 2 is normal
(undimmed) brightness and bit 4 is low battery.

The reserved fields hold these constants in every published firmware (3.2.12 to 5.0.3), and
the official app reads and discards them, so a client can ignore them.

**Static Data `(0x01, 0x02)`** — `gen_static_data`. `buff[2] = total_len & 255`,
`buff[3:9] = MAC` (6 B), then `struct <biHBBBbBBBbhhiiibbb` at offset 9 (34 B), then three
UTF-8 strings concatenated from offset 43. There are no per-string prefixes: their lengths
are the struct's last three fields.

| Region | Field |
| --- | --- |
| `buff[2]` | total_len & 255 |
| `buff[3:9]` | device MAC (6 B) |
| struct @9: `b` | reserved (always 0) |
| `i` | age |
| `H` | release_id |
| `B B B` | ver_major, ver_minor, ver_patch |
| `b` | color_id |
| `B` | settings_flags (bit0 persistent north, bit1 compass lock; the app reads bit3 as bond chat) |
| `B` | capabilities (bit0 = half-duplex loop; 1 in 5.x, 0 in 4.1.3) |
| `B` | service_id |
| `bhhiii` | 6× reserved (always 0; the app discards them) |
| `b b b` | len(device_name), len(branch), len(wifi_ssid) |
| strings @43 | device_name, git branch (`N/A`), wifi_ssid (`""`) |

**Peer Ping `(0x06, 0x02)`** — `gen_peer_ping`. `buff[2]` = total length, `buff[3:9]` =
peer MAC (6 B), `buff[9]` = mesh hops, then `struct <ffbbh4BHbb4BiihBbf` at offset 10 (40 B):
lat, lon, p_acc, speed, bearing, flag byte A, r, g, b, 0 (the app's `dtim`), name length, rssi, msg_rx, msg_tx,
mesh_rx, mesh_send_count, last_update, last_coords_unix, distance_diff, flag byte B,
orientation, volts. Then the peer name (from offset 50) and `<bH` = (batt_pct, release_id).
A = `pack_flags(sos, is_poi, is_mesh, is_stale, is_collected, 0, is_unknown, 0)`,
B = `pack_flags(is_hidden, is_locked, 0×6)`. The app reads A's bit 5 as `isIdle`; the
firmware always sends 0 there. `is_unknown` is set once a peer has had no
coordinates for 2 h (v5.0.3; 4 h in v5.0.2).

**Peer Sync `(0x06, 0x07)`** — `gen_peer_sync`: a peer-MAC list,
`[0x06, 0x07, total_len & 255, peer_count, mac0(6), mac1(6), …]`.

## ESP-NOW mesh client

To join the mesh peer-to-peer instead of going through a phone, send/receive raw ESP-NOW
frames on the fleet's channel. The repository's Go `mesh` package encodes and decodes these
frames, and the `emulator` package plus `cmd/totememu` run a complete Totem on an ESP32 with
TinyGo: see [ESP32 emulator](/reference/esp32-emulator).

### Radio setup

| Item | Value |
| --- | --- |
| Channel | **6** (`self.channel = 6`, the only write to it; there is no `set_channel`) |
| Interface | WiFi station; the ESP-NOW address is the STA MAC (`machine.unique_id()`) |
| PHY | `WIFI_PROTOCOL_LR` only (protocol bitmap `0x08`), in every mode 5.0.3 uses |
| LR rate | **250 K**: `EspConn` calls `e.config(rate=41)` (`WIFI_PHY_RATE_LORA_250K`) |
| TX power | `txpower=21` dBm (the driver caps it at 20) |
| Encryption | none — `add_peer(mac)` with no `lmk` |

The fleet is pinned to channel 6 (**Confirmed**, and on hardware); ESP-IDF drops off-channel
frames, so a mesh client **must** match it.

### Frame layout

```text
┌──────────┬──────────┬────────┬────────┬───────────────────────────┐
│ SyncWord │ SyncWord │ cat_id │ cmd_id │ payload (struct-packed)   │
│  0xA7    │  0x74    │  u8    │  u8    │ variable                  │
└──────────┴──────────┴────────┴────────┴───────────────────────────┘
  [0]        [1]        [2]      [3]      [4:]
```

- **SyncWord** = the 2 bytes `0xA7 0x74` (literal in the image).
- Validation is **SyncWord match + `len >= 4` + a per-`(cat, cmd)` payload-size check**.
- There is **no CRC or checksum** on the ESP-NOW frame. (The rodata string
  `Invalid Checksum value for: {}` belongs to the u-blox UBX GNSS parser, not this path.)
- Mesh dedup UID is a `uint16 randint(1, 65534)` at mesh-frame offset 20;
  `MSG_EXP_MSECS = 150000` ms.

### Payload formats (`TOTEM_MSG_MAP`, corrected)

<Warning>
  Earlier analyses decoded the map's qstr-immediates with `>>2`, producing bogus "handler
  names" (`disconn_animation`, `device_power`, `dev_info`, `disabled`, …). Those are decode
  artifacts and are **wrong**. ESP32 MicroPython (REPR_A) tags qstr-immediates as
  `(o & 7) == 2` with value `o >> 3`; under the correct `>>3` decode **every** value is a
  `struct` format string. The corrected table follows (**Confirmed**).
</Warning>

Every payload leads with the echoed `(cat_id, cmd_id)` as `BB`.

| `(cat, cmd)` | Format | Size |
| --- | --- | --- |
| `(0,0)` / `(0,1)` / `(0,2)` | `<BBffbbhbbb6B` | 23 B |
| `(1,0)` | `<BBB7bHbb` | 14 B |
| `(1,2)` | `<BBiffHii` | 24 B |
| `(1,5)` | `<BB9B8bhh4B` | 27 B |
| `(1,6)` | `<BBbbB` | 5 B |
| `(1,7)` | `<3Bbb` | 5 B |
| `(2,0)` | `<BB6BffbbHbbbhhBBi` | 33 B |
| `(3,1)` / `(3,2)` | `<BBHH4b4BHHBb` | 20 B |
| `(7,0)` | `<BBffbbbHbbH` | 19 B |
| `(7,1)` | `<BBHbffb` | 14 B |

`EXTENDED` longer variants — `(cat, cmd) → {frame length → fmt}`. The keys are total frame
lengths including the SyncWord, not schema ids (for `(0,0)`, 72 means "72 bytes or more"):

| `(cat, cmd)` | Frame length | Format | Size |
| --- | --- | --- | --- |
| `(0,0)` | 25 | `<BBffbbhbbb6B` | 23 B |
| `(0,0)` | 59 | `<BBffbbhbbb6Bhii4BhHehhffbB` | 57 B |
| `(0,0)` | 72 | `<BBffbbhbbb6Bhii4BhHehhffbBBiiBBb` | 69 B |
| `(1,6)` | 5 | `<BBbbB` | 5 B |
| `(1,6)` | 29 | `<BBbb9BBB3i` | 27 B |
| `(2,0)` | 45 | `<BB6BffbbHbbbhhBBiffh` | 43 B |

Every field is now labelled (**Confirmed**): see the peer, locate and Smart Group tables in
[message format](/protocols/message-format#peer-frame-0-cmd). The 6-byte MAC in the `(0,*)`
frames is a target MAC that 5.0.3 always leaves zero; the sender is identified by its ESP-NOW
source address. Bonding and timing are in [ESP-NOW mesh](/protocols/espnow-mesh#pairing-p2p-bond).

## Custom OTA server

You can point a Totem at your own OTA server; it needs **no signing key** (SHA-256 only,
plain HTTP). The contract (**Confirmed**):

<Steps>
  <Step title="Device announces">
    `POST http://api.totemportal.com/devices/{MAC}/ota` (plain HTTP, no auth) with JSON body
    `{version, endpoint_id, device_type_id, lat, lon, gnss_time, release_id}`.
  </Step>
  <Step title="Server replies with a release object">
    Expose `ota_url, version, product, branch, release_code, release_id`.
  </Step>
  <Step title="Device fetches the manifest">
    `GET {ota_url}/contents.json` — a JSON **array** of filenames. The device picks the
    entry ending `.bin` (firmware) or `.tgz` (preview).
  </Step>
  <Step title="Download, verify, flash">
    The device downloads the chosen file, verifies **SHA-256 only**, flashes, reboots, and
    reports back with `POST …/ota?updated`.
  </Step>
</Steps>

<Note>
  A device WebSocket to `api.totemportal.com` (`ws://`) carries push OTA triggers shaped
  like `{"cmd":…}` (**Partial**). A demi-god ESP-NOW OTA trigger also exists
  (`demigod_gen_ota_update`), but its exact `(cat, cmd)` and struct are **not recovered** —
  do not fabricate them.
</Note>

## Chunked transfer

Only needed if your client accepts the device's **log uploads** (v5.0.3) or does BLE OTA.
A client that sends the plain 4-byte Ready frame never receives uploads. Layouts
(**Confirmed**, `f_ble_chunking.dis:383-492` and `f_ble_file_upload.dis:591-745, 1165-1300`;
details in [chunking](/protocols/message-format#chunking)):

- **Transfer header** (announce / finish), **indicated** on `…-0001`: `[0x02, 0x02]` +
  `struct '<HBBBiHiB'` = file_id, status_id, action_id, file_type_id, byte_pos, chunk_no,
  file_size, flags (v5.0.3: bit0 last chunk, bit1 from compass). Then the 32-byte SHA-256 at
  `buff[18:50]`, the name length at `buff[50]`, the name from `buff[51]`, and `err_no` right
  after it. `file_id = sha256[0] | sha256[1] << 8`.
- **Chunk** (v5.0.3), **notified** on `…-0003`: `[0x00, 0x02]` + `struct '<HHiH'` = file_id,
  length, byte_pos, chunk_no, then the data (`CHUNK_HDR_SZ = 12`). The payload size is
  `min(mtu - 3, 247) - 12` — 235 bytes at MTU 256, and 8 bytes if the MTU is still 23. A
  write that fails with `OSError` is retried up to 3 times, 160 ms apart.
- **App reply**, written to `…-0001` (v5.0.3): `(0x02, 0x03)` + `struct '<HbBBiHiB'`, 18 bytes
  in total — the device parses it as `'<BBHbBBiHiB'` from offset 0 and ignores anything
  shorter than 18 bytes or carrying a `file_id` other than the one in flight. It reads
  file_id, status, action, chunk: `status ∈ {2, 3, 4}` is terminal, `action 4` = resume at
  `chunk` (or chunk 1 if `chunk` is 0), `action 1` = ready. A reply longer than 50 bytes may
  carry `err_no` after the name, exactly as the device's own header does.

| Field | Enum values |
| --- | --- |
| `status_id` | 1 = normal / in-progress, 4 = error / abort (the device sends 1 for announce and completion, 4 to abort) |
| `action_id` | 0 = header / announce, 1 = last-chunk / complete, 4 = resume (app → device) |
| `file_type_id` | **2** for a log upload to the app |

<Note>
  `file_type_id` is not the `save_to` enum. `SAVE_TO_VFS = 1`, `SAVE_TO_OTA = 2`,
  `UPLOAD_TO_APP = 3` are internal destinations passed to `FileTransfer(save_to=…)` and
  never appear on the wire; `_upload` separately sets `file.file_type_id = 2`, and that is
  the byte you receive (**Confirmed**, `f_ble_file_upload.dis:1495-1530`).
</Note>

Overall result codes, from the uploader's own summary line
(`result: {} (1=done 2=no app 3=retry 4=failed 5=cancel 6=abort)`):
`1 done, 2 no-app, 3 retry, 4 failed, 5 cancel, 6 abort`.

While an upload is streaming the uploader takes `ble.noncrit_owner = 'upload'`, which lets
it delay the half-duplex TX handoff by up to 2 s
(`[send_data_v2] Non-critical hold expired ({}); handing off`).

## Still missing / confirm on-device

These are known-structure-but-unconfirmed items. Verify them against your own hardware
before relying on them:

| Item | Status | How to confirm |
| --- | --- | --- |
| Home channel | 6 (**Confirmed**, hardware-tested); no `set_channel` exists | — |
| `frame_schema_id` / transmit mode | **Confirmed and hardware-tested**: `0` = legacy loop, which notifies (works on macOS), `> 0` = half duplex, which indicates (stalls on macOS/iOS) | `totemctl --trace info`, or add `--half-duplex` to compare |
| Negotiated MTU | **Partial** — the device sets no preferred MTU, so this is the central's choice; 256 observed on macOS | watch `mtu_payload` effects on upload chunk size |
| Half duplex on Linux / Android / Windows | **Untested** (those stacks confirm indications, so it should work) | `totemctl --half-duplex --trace watch` on such a host |
| Mesh payload field semantics | **Confirmed**; peer frames and the pairing handshake hardware-tested with the ESP32 emulator | — |
| Locate relay and Smart Group on the air | **Confirmed** from bytecode, not yet hardware-tested | run the emulator with `pos` set, far enough from the Totem for its peer to go stale |
| Demi-god OTA frame | **Partial / missing** | `(cat, cmd)` + struct not recovered — do not fabricate |
| Runtime-only values | **Partial** | venue code, group id, and device name live in runtime state / bytecode, not the static image |

## Safety

<Warning>
  Interoperate only with **Totems you own.** Because the mesh is unauthenticated and
  unencrypted, the demi-god ESP-NOW broadcast path can affect **nearby** devices — its only
  gate is RSSI proximity plus message-UID dedupe, with no signature or HMAC. Do not send
  demi-god or mesh commands against devices you do not own; broadcasting near other people's
  Totems can change their behaviour without their consent.
</Warning>

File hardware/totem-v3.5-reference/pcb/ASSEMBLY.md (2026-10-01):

# Totem v3.5 reference board: fabrication and assembly

Everything needed to have this board made, assembled, brought up and
programmed. Made by `pcb/fab.py` from `schematic/totem.kicad_pcb`; the
design's reasoning is in `../README.md`.

## What is in the package

| File | For | What it is |
| --- | --- | --- |
| `totem-v3.5-gerbers.zip` | PCB fab | Gerber X2, 4 copper layers, mask, paste, silk, outline; Excellon drills (plated and unplated) with maps; `totem-netlist.ipc`, the IPC-D-356 netlist for electrical test |
| `totem-v3.5-odb.zip`, `totem-v3.5-ipc2581.zip` | PCB fab | The same board as ODB++ and IPC-2581 C (zipped XML), for fabs that take one file |
| `totem-bom.csv` | Assembler | One line per part: value, designators, footprint, quantity, side, manufacturer, MPN, note |
| `totem-cpl.csv` | Assembler | Pick-and-place: designator, X, Y (mm), side, rotation |
| `totem-v3.5-assembly-top.pdf`, `-bottom.pdf` | Assembler | Every part's outline with its designator, pads, pin 1 and polarity marks. The bottom sheet is drawn as seen from the bottom |
| `totem-offboard.csv` | You | What is bought but not placed: cell, GNSS antenna, programming adapter |
| `totem-v3.5-schematic.pdf` | Everyone | The schematic |
| `totem-v3.5.step` | Mechanical | The assembled board, for checking the case |
| `render-top.png`, `render-bottom.png`, `views/` | Everyone | 3D renders; copper, mask and silk of each side |
| `totem-v3.5-board-stats.txt` | PCB fab | Board size, layer count, hole and pad counts |

## Ordering the bare board

| | |
| --- | --- |
| Layers | 4: F.Cu signals, In1 solid GND, In2 3V3, B.Cu signals |
| Size | 45.75 x 46.36 mm, routed outline with notches (no V-score) |
| Thickness | 1.6 mm |
| Stack-up | Standard 1.6 mm 4-layer with about **0.21 mm of 7628 prepreg** between F.Cu and In1 (JLCPCB JLC04161H-7628 or equivalent) |
| Impedance | **One controlled line:** GNSS_RF, 0.38 mm on F.Cu over In1 = 50 Ω on that stack-up. On any other stack-up, re-size it first |
| Copper | 1 oz outer, 0.5 oz inner |
| Minimums used | Track and space 0.13 mm; vias 0.45 mm / 0.2 mm drill (power 0.6 / 0.3); copper 0.3 mm from the edge |
| Finish | **ENIG**: the 0.5 mm-pitch LGAs (U5, U6), castellated modules (U1, U2) and 1.5 mm LEDs want flat pads |
| Mask / silk | Green / white both sides, as the reference board. Vias tented |
| Test | Electrical test against `totem-netlist.ipc` |

## Assembly

**Double-sided SMT, reflow both sides, and one through-hole part.**
Assemble the **bottom (LED side) first**: small parts only (ring, crystal,
motion sensor and magnetometer, microphone, charge LEDs, latch). Then the
**top (radio side)**: ESP32 module, GNSS module, charger, USB-C,
switches. The heavy parts then see one reflow, and upright. **J2**, the
battery connector, is through-hole: hand or selective solder it last.

- **Stencil:** 0.12 mm, both sides. The ring's 1.5 mm LEDs and the
  sensors' 0.5 mm pitch set this.
- **Moisture:** the LEDs (D100-D159, D200-D206), U2 (MAX-M10S), U5
  (LSM6DSV16X) and U6 (LIS2MDL) are moisture sensitive. Bake to their
  datasheets if their floor life has run out.
- **The magnetometer (U6):** keep magnetised tools, magnetic pick-up heads
  and magnets away from it once placed. A strong field shifts its offset
  (its datasheet excludes drift from magnetic shock from its offset
  figure); calibrate it in the finished unit regardless.
- **Profile:** lead-free (SAC305). The WS2812-type LEDs are the most
  heat-sensitive parts on the board: keep the peak and time above
  liquidus within the XL-1515 datasheet's limits.
- **Rotations, bottom side:** assembly houses read bottom-side rotation in
  the CPL differently. Check their placement preview against
  `totem-v3.5-assembly-bottom.pdf` before they run it. The rule for the
  ring: every LED's **DI and VDD pads face out** from the ring, and its
  triangle mark is on the DO/GND side. D100 is the LED nearest the buttons,
  and the chain runs counter-clockwise seen from the LED side.
- **Inspection:** X-ray U5 and U6 (LGA, no visible joints) and the
  modules' ground pads; AOI the ring for tombstoned or rotated LEDs.
- **Not placed:** TP2-TP7 are bare pads for a pogo jig. There is nothing to
  place on them.

### By hand, after reflow

1. **TP1, the touch pogo pin.** A gold surface-mount spring-loaded pin
   soldered upright on the 2.5 mm pad in the centre of the crystal, LED
   side, as on the reference board. Its length sets the pressure on the
   crystal. Match it to the reference unit (see "Before ordering").
2. **J2**, if the assembler did not fit it: S2B-PH-K-S, through-hole, its
   opening toward the board's centre and its housing over the corner.
3. **Cell:** 3.7 V 1000 mAh Li-Po on J2. **J2 pin 1 is + (VBAT), pin 2 is
   GND.** JST PH leads are not wired the same way by every seller, so check
   the plug before connecting.
4. **GNSS antenna** on J3 (U.FL).

## Bring-up

Do it without a cell first, from a current-limited bench supply.

1. **Before power:** check that VBAT, VSYS, +3V3 and VBUS are not shorted
   to GND. TP2 is +3V3 and TP3 is GND.
2. **Supply on J2:** 3.8 V, limit 100 mA, + on pin 1. The board draws
   almost nothing while off: the latch keeps VSYS off.
3. **Press SW1 (power):** VSYS comes up, and +3V3 on TP2 reads **3.3 V**.
   It stays on after release, because the latch holds itself from +3V3.
4. **USB-C on J1**, with the supply swapped for a discharged cell: the
   TP4056 charges at **600 mA** (R5 = 2 k). The charge LEDs in the crystal
   show it: **D4 (red) while charging, D5 (green) once full**, both only
   with USB-C plugged in. D3, the red LED by the SOS button, is the
   firmware's (SOS), not the charger's.
5. **Program** (below). The firmware then drives the ring and the crystal.
   All 67 pixels at full white is 0.62 C at the firmware's brightness. Run
   that once to check every pixel, and look for a dark one in the chain.

The design's numbers (rails under load, sense dividers, latch behaviour
over cell voltage and FET threshold) are in `../README.md`, Verification.

## Programming

The ESP32 has no USB, and the USB-C carries power only, so the board is
flashed over UART0 through the pads:

| Pad | Signal | Adapter |
| --- | --- | --- |
| TP2 | +3V3 | 3.3 V (only if the board is not powered itself) |
| TP3 | GND | GND |
| TP4 | TXD0 | RX |
| TP5 | RXD0 | TX |
| TP6 | EN | RTS (reset) |
| TP7 | IO0 | DTR (boot) |

`esptool` drives EN and IO0 through RTS and DTR on its own. Without those
lines: hold **SOS (SW2)**, which is IO0, while resetting. The firmware image
is not part of this package.

## Before ordering

These could not be settled from photographs. Measure them on the reference
unit (`../README.md`, The board):

- **The right edge:** its height, and the USB-C slot to the lower-right
  notch. Known only to ±1.3 mm.
- **USB-C position against the case.** Its plug face sits about 0.6 mm
  further in than the original's. The JST is on the original's pin
  positions.
- **Switch stem length** against the rear cover. The BOM names a 9.5 mm
  PTS645.
- **The touch pogo pin's length** and barrel diameter.

**Known limit:** the XL-1515 LEDs are rated from 3.5 V, and the ring runs
from the cell, which the firmware takes down to 3.15 V. The reference board
has the same arrangement.

**What this board is:** the reference unit's outline, and its major parts
where the photographs put them. The passives and every trace are this
design's own, not a copy of the original's (`../README.md`).

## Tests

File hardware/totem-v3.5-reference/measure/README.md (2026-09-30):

# Measuring the board from two photographs

Everything the PCB takes from the reference board — its outline, where the
parts sit, the ring and crystal geometry — is measured here from two
photographs, `photos/radio.jpg` (the ESP32/GNSS side) and `photos/led.jpg`
(the LED side). `run_all.sh` redoes all of it in order.

## The radio side

A phone photograph is not a scale drawing: this one has visible perspective
(the tab's top edge is 0.5 mm higher at one end while the sides are
vertical), and a single px-per-mm figure was off by up to 4% across the
board. So the photo is mapped to the board plane by a homography fitted to
features whose spacing is known exactly:

| Feature | Known | Fit |
| --- | --- | --- |
| ESP32-WROOM-32E castellated pads, 38 | 1.27 mm pitch, footprint positions | along-row residual 34 µm rms |
| MAX-M10S castellated pads, 18 | 1.10 mm pitch | spans 8.798 / 8.722 mm against 8.800 |

The fit uses only a pad's position along its row; across the row it only
asks the row to be straight, since where the sampling line was drawn is not
a measurement. TP4056 leads were tried and dropped: gull-wing shoulders put
their centroids 3-6% off.

The board frame is then fixed by the left edge (1600+ clean points), and
the edge is traced from the green mask and fitted stretch by stretch
(`fitall.py` lists the boxes and each fit's residual). Every edge keeps its
measured angle: an earlier version snapped near-orthogonal edges to the
axes, and the LED-side photo showed that moved the right side by up to
1.5 mm.

## The LED side

This photo is turned a quarter and seen from below: the USB-C's four shell
slots and two locating holes are along its bottom edge, the ESP32's antenna
overhang is off its left. Its 60-LED ring images round to 1%, so the photo
itself is close to a similarity. It is registered to the outline by the
edges that are clean from this side — the lower-left notch, the tab, the
lower-right notch — and the USB-C slots measured on the other side
(`register_led2.py` explains the two registrations and why the affine one
is kept).

## What is known how well

| Quantity | Uncertainty | Why |
| --- | --- | --- |
| Outline, left half and bottom | ±0.3 mm | fitted edges, 10-50 µm rms each; calibration within 1% |
| Outline, right edge and USB-C | ±1.3 mm in y | the two photos disagree by this much on the right side; each is self-consistent there. **Measure with calipers before ordering**: USB-C slot to lower-right notch, and the board's height at its right edge |
| Lower-right notch's outer corner | ±0.5 mm | under the JST on the radio side; its chamfer is taken from the LED side |
| Upper-left outside corner radius | ±0.5 mm | the u.FL cable crosses it |
| Ring centre and radius | ±0.15 mm | 29 LEDs, radial rms 122 µm |
| Ring start and direction | derived, not seen | the DOUT->DIN links are on an inner layer; see the hardware README |

Photos were converted from the originals to JPEG (quality 95); the
geometry is unchanged, individual numbers can move by a few µm on re-run.

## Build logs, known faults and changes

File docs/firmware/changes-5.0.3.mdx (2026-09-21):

---
title: "What changed in 5.0.3"
description: "Function-level differences between firmware v5.0.2 (release 335) and v5.0.3 (release 339)."
---

v5.0.3 (release 339, built Sep 12 2026) is a hardening release on the same ESP-IDF v5.4 /
MicroPython v1.25.0 base. **The BLE and ESP-NOW wire formats are unchanged.** Every record
layout, `TOTEM_MSG_MAP`, `EXTENDED` and `COMM_SPEED` entry is identical. Clients written for
v5.0.2 keep working, and the new BLE features are opt-in.

The comparison reconstructs every frozen module from both images, disassembles them with
MicroPython's own `mpy-tool.py`, and diffs them function by function (see
[methodology](/reference/methodology#diffing-firmware-versions)). **73 modules are identical,
21 changed, 2 were removed.**

<Note>
  **The 73/21 split is CONFIRMED** by two independent comparisons of the 94 modules
  common to both images: SHA-256 of the raw `.mpy` files, and a line diff of the
  disassembly with the source-path header stripped. Both agree exactly, and neither
  reports a module that the other does not.

  The [methodology](/reference/methodology#diffing-firmware-versions) page says 74/20,
  and is not contradicting this: it compares decoded functions, which ignores the
  line-number table a `.mpy` carries. The next note is the one module that separates
  the two counts.

  The 21 changed modules are `espnow_conn_v2`, `compass`, `ble_manager`, `ubx_gnss`,
  `project_data`, `f_ble/file_upload`, `compassing`, `peripherals`, `new_vibe`, `ota_ble`,
  `f_lib/file_mgr`, `nav_logger`, `f_ble/ble_lite`, `ble_controller`, `f_ble/chunking`,
  `ble_core`, `f_ble/ble_data`, `button`, `wdt_manager`, `peer_helpers`, `f_ota/system`.
</Note>

<Note>
  **Twenty of those 21 changed their code. `ble_controller.py` did not.**

  A `.mpy` differs whenever the module is recompiled, because source line numbers move
  and the line-number table is embedded in the file. Comparing the disassemblies with the
  source path, the raw bytecode blob and the line-info table stripped — leaving qstrs,
  object tables, preludes and decoded instructions — `ble_controller` is **byte-for-byte
  identical** between the two releases: the same 105-entry qstr table, the same 17-entry
  object table, the same instructions in all 14 code objects (**confirmed**). Every
  line-info entry moved by exactly +2 without compounding, which is two blank or comment
  lines inserted above `class BleBlockers` and nothing else.

  So a hash diff is the right tool for "what might have changed" and the wrong one for
  "what did". The other twenty differ in instructions, not just in line numbers.
</Note>

<Note>
  The diff is complete across all 94 modules — it compares bytecode, so it does not depend
  on anyone having understood the module. Knowing *that* a function changed is not the
  same as knowing what it does. Of the 21, 15 are rated DECODED and 6 PARTIAL on the
  [module reference](/reference/modules) — `ble_controller.py` was the last NAME-ONLY one
  and has since been read, which is how the recompile-only finding above came out. Where
  a change below is described in
  behavioural terms, that description comes from reading the bytecode; where it is
  described as "internal", it does not.
</Note>

## At a glance

| Area | Change |
| --- | --- |
| Image | 1,692,352 → 1,699,872 bytes; DROM +6,528 B, IROM +996 B; new build date and hashes ([firmware image](/firmware/overview)) |
| Modules | 96 → 94 frozen: `imu_fusion.py` and `io_mgr.py` removed (neither was imported in v5.0.2) |
| BLE | third characteristic `…-0003`; optional upload-capability byte in Ready; 15 s hung-link guard; log upload over BLE actually wired up |
| ESP-NOW | TX back-pressure, relay shedding under load, supervised comms task, `NO_MEM` no longer triggers a reboot |
| Device | battery-% curve, button debounce, Vibe mode tuning, stale-peer handling, BLE schedule hardening, WiFi-driver "kick" |

## BLE

| Change | Effect on clients |
| --- | --- |
| New characteristic `7913b588-0003-…` (`chars__on_demand`, queue 3) | carries upload chunks only; ignore it unless you accept uploads |
| Ready frame accepts a 5th byte; bit0 = app supports uploads (`is_upload_supported`) | optional; a 4-byte Ready keeps uploads suspended |
| Hung-link guard: no Ready within **15 s** → stall logged, disconnect scheduled; after 2 stalls in a row BLE stays off 90 s (was 30 s) | send Ready promptly |
| `(2,3)` on `…-0001` routes to `FileUploader.on_header` | the upload reply channel |
| `(12,3)` phone-fix flags bit0 = phone has internet (`ble_ticks_app_internet`); `(6,9)` cloud updates also mark it | optional; one of the upload gates |
| Transfer header's last byte becomes `pack_flags(is_last_chunk, is_origin_compass)`; `CHUNK_HDR_FMT = '<HHiH'`, `CHUNK_HDR_SZ = 12`, `UPLOAD_TO_APP = 3` defined | the v5.0.2 uploader imported these names without defining them: it was dead code |
| `Characteristic.indicate` serialised by a module-level `asyncio.Lock`; `OSError` (link down) handled | fewer crashes on disconnect; still 500 ms confirmation timeout |
| Half duplex: `evt_tx_idle` plus a 2 s "non-critical hold" before handing TX to the app | none for legacy-mode clients |
| Live Data timestamp is 0 when the clock reads before 2024-01-01 (was: when `evt_rtc_ready` unset) | same field, different gate |
| `BleLite` tracks the negotiated MTU (`mtu_payload()`); WiFi-driver kick (`wifikick`, `_kick_task`) with WDT blocker | internal |
| `ble_schedule_mgr` caps the "outbox empty" wait at 20 s and waits for the uploader to go idle | fewer hung scheduled disconnects |

Unchanged: the command map, all `gen_*` record layouts, and both transmit loops. The legacy
full-duplex loop that works on macOS behaves exactly as in v5.0.2; see
[transmit modes](/protocols/ble#transmit-modes). A v5.0.3 device was tested end to end with
`totemctl`.

## ESP-NOW mesh

The module body of `espnow_conn_v2` (imports, message maps, class construction) is opcode-
identical. Changes are inside `EspConn` ([details](/protocols/espnow-mesh#transmit-back-pressure-v503)):

- **All-peer sends** unicast to non-POI peers in a rotating order, limited by an estimate of
  free driver TX buffers.
- **Back-pressure:** sends are dropped locally (`tx_skipped`) when no buffers are free.
- **`ESP_ERR_ESPNOW_NO_MEM`** is treated as back-pressure. In v5.0.2 it set
  `is_silent_reboot`.
- **Relay shedding:** mesh frames from non-peers are no longer relayed when the receiver
  drops frames or the TX pool is busy.
- **Supervisor:** `communicate_supervised` restarts the comms task after a crash.
- **Bonding:** an already-bonded requester gets five peer ACKs. A Smart Group cancel now also
  matches by UID.

The LR PHY rate is 250K (`e.config(rate=41)`) in **both** versions. Earlier docs said 500K.

## Device behaviour

| Area | v5.0.3 |
| --- | --- |
| Battery % | top of the voltage table (4.13–4.38 V) removed: 4.12 V now reads 100% (was 61%), 3.8 V reads 50% (was 31%) |
| Buttons | the 50 ms post-press `debounce` coroutine is replaced by a 30 ms edge lockout on press and release |
| Vibe mode (`new_vibe`, 1.9 → 1.10) | sound-reactive ring effect: faster auto-gain (13 → 25), cleaner peak hold, ~30% dimmer; debug telemetry removed |
| Peers | `is_unknown` after 2 h without coordinates (was 4 h); stale peers use the proximity display (nearby by RSSI ≥ −41) |
| Nav logging | fast `events.bin` rotation (≥ 1024 B) while the uploader has no backlog |
| Promo | `activation_check`, never called in v5.0.2, now runs; it carries a time-limited "Totem Secret Meetup" POI (2026-09-21, 03:20–04:00 UTC) |
| Peer management | restores the default crystal colour when it ends while the device is upright |
| Watchdog | new `WLAN_KICK` blocker |
| Files | async `gen_file_hash` (SHA-256) and `get_oldest_file` in `f_lib/file_mgr.py` |
| Debug builds only | SOS single tap triggers a BLE log upload |

## Removed modules

| Module | What it was |
| --- | --- |
| `imu_fusion.py` | an older Madgwick `Fusion` / `Cal` implementation with no importer; `imu_fusion_auto.py` (unchanged) is the fusion engine |
| `io_mgr.py` | a stub containing only `import io` |

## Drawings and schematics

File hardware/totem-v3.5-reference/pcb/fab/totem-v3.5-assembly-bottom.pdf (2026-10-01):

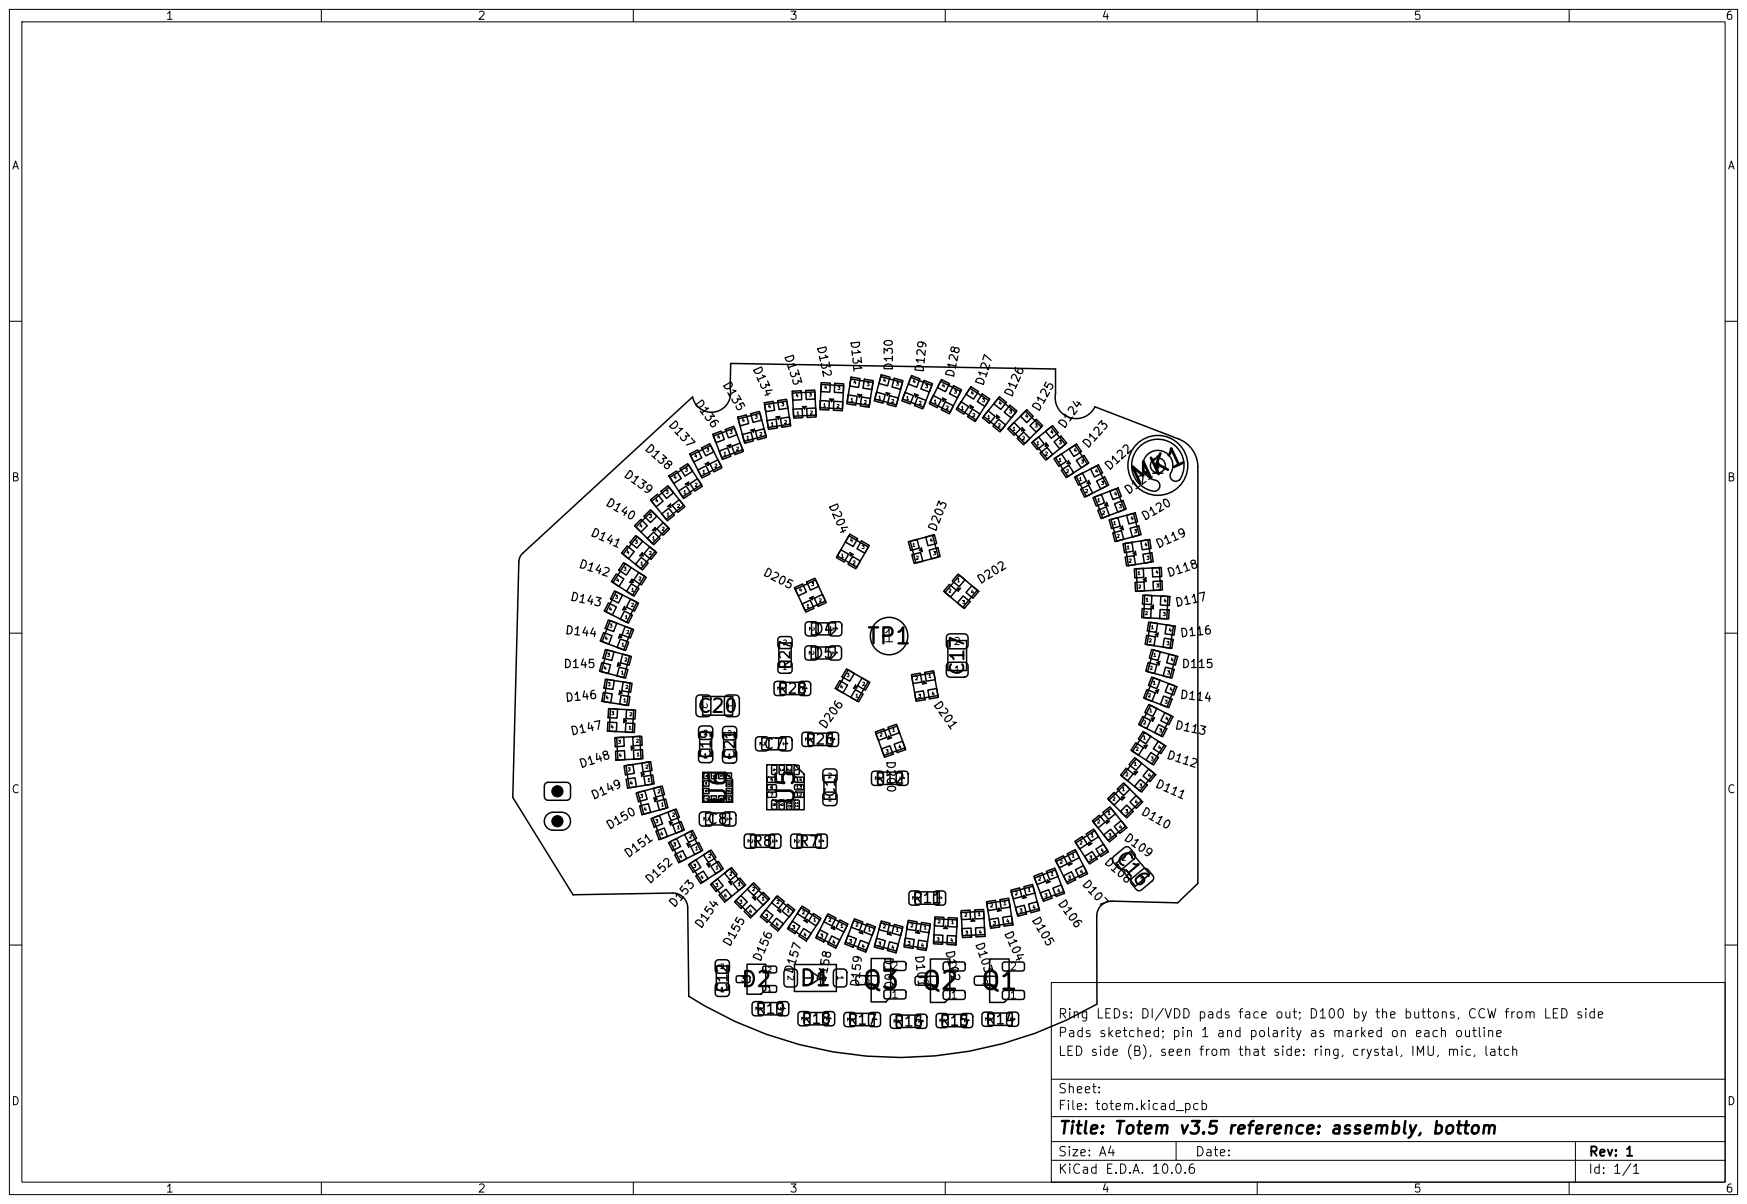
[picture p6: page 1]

Pads sketched; pin 1 and polarity as marked on each outline
LED side (B), seen from that side: ring, crystal, IMU, mic, latch

Sheet:
File: totem.kicad_pcb
Title: Totem v3.5 reference: assembly, bottom

Size: A4 | Rev: 1
KiCad E.D.A. 10.0.6 | Id: 1/1

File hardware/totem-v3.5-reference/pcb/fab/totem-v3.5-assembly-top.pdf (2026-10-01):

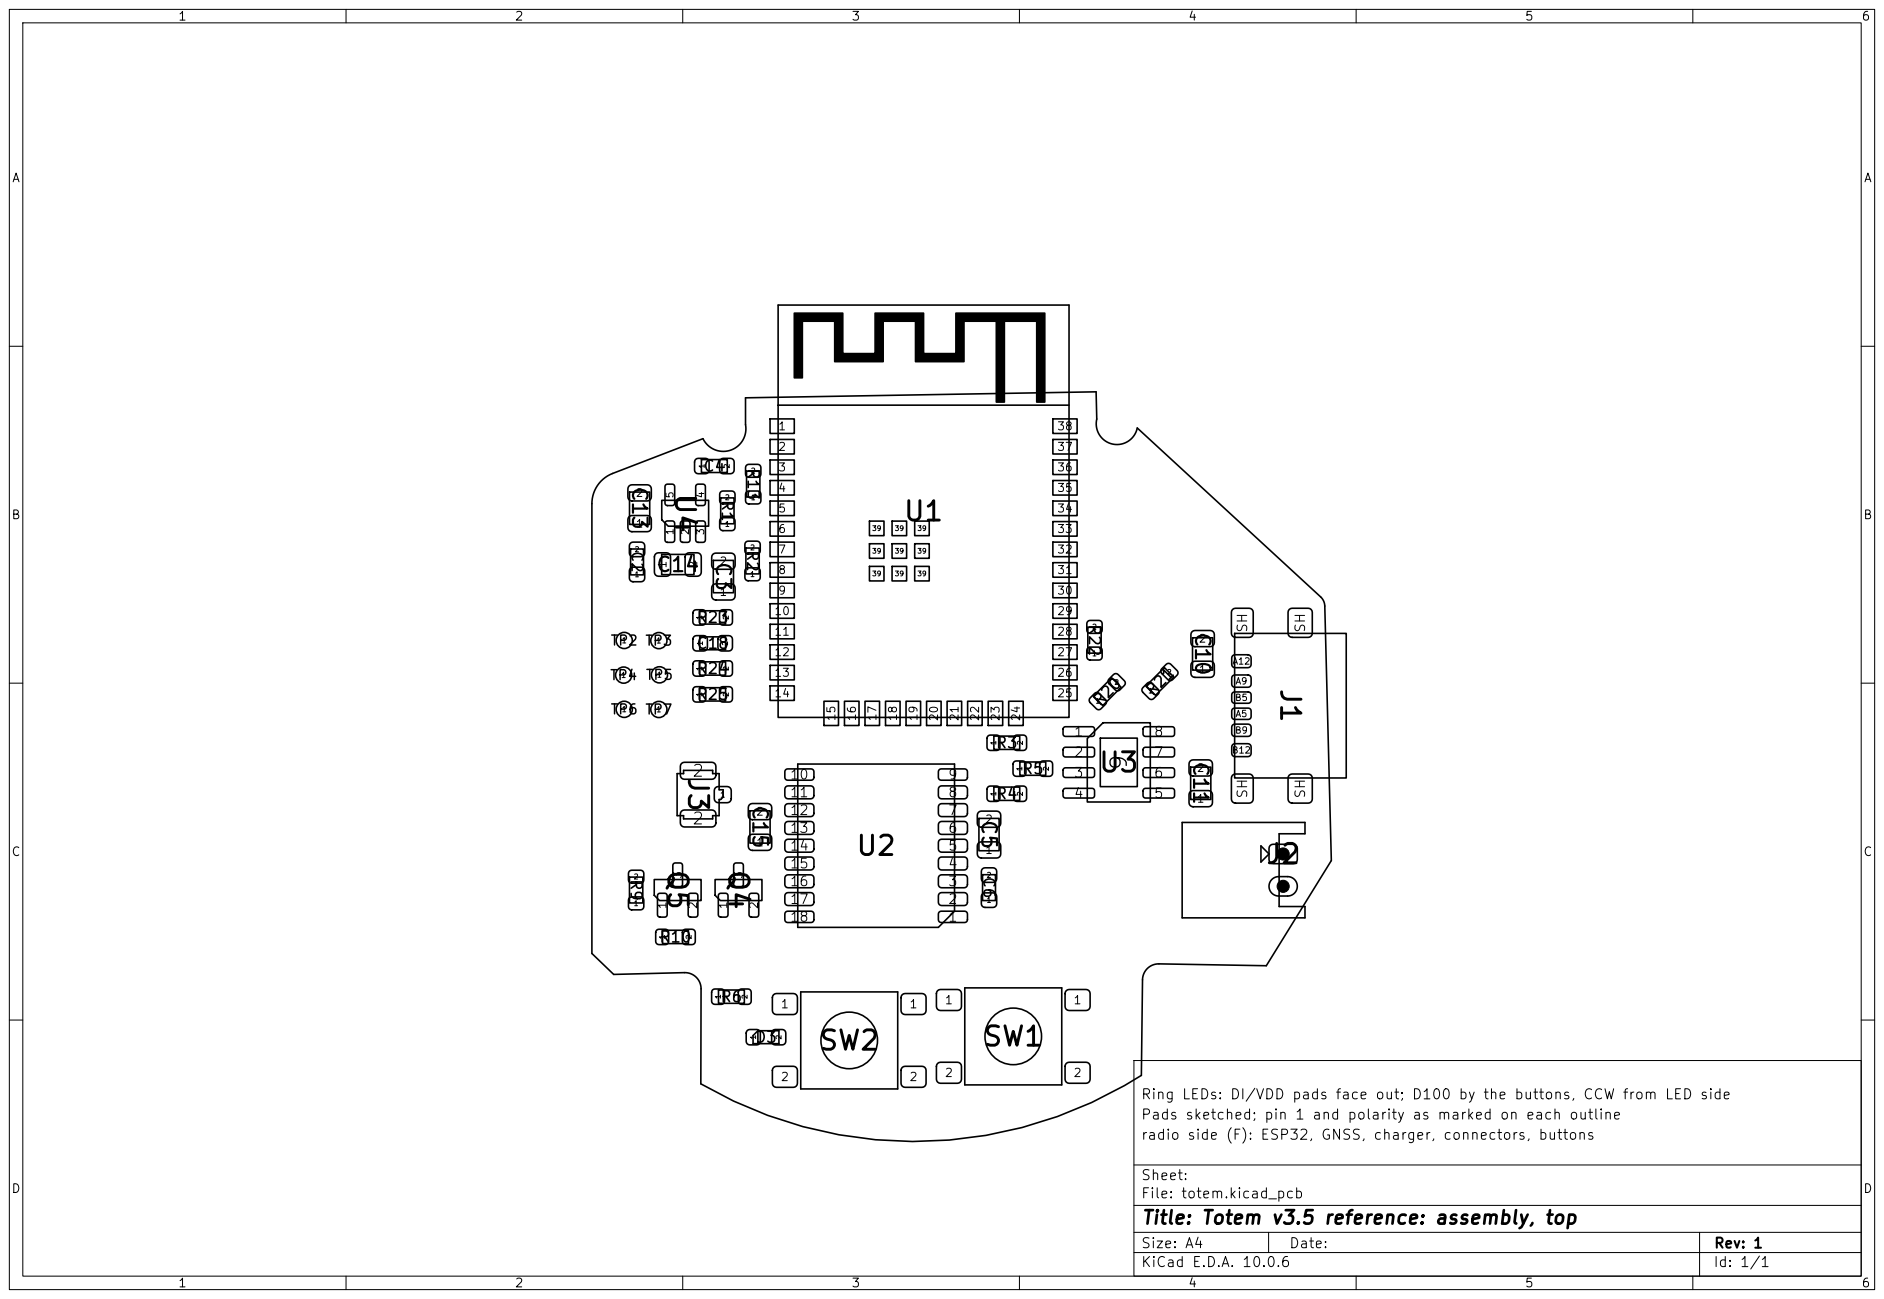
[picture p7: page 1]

Ring LEDs: DI/VDD pads face out; D100 by the buttons, CCW from LED side
Pads sketched; pin 1 and polarity as marked on each outline
radio side (F): ESP32, GNSS, charger, connectors, buttons

Sheet:
File: totem.kicad_pcb
Title: Totem v3.5 reference: assembly, top

Size: A4 | Rev: 1
KiCad E.D.A. 10.0.6 | Id: 1/1

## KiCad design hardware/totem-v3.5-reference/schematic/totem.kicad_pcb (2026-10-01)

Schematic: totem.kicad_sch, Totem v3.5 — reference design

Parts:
C1, C4, C6, C7, C12, C19, C21: 100n; C_0603_1608Metric
C2, C18: 1u; C_0603_1608Metric
C3, C5, C10, C11, C13, C14, C15, C16, C17, C20: 10u; C_0805_2012Metric
C8: 220n; C_0603_1608Metric
D1: 1N4148W; D_SOD-123
D2: BAT54W; SOT-323_SC-70
D3, D4: red; LED_0603_1608Metric
D5: green; LED_0603_1608Metric
D100, D101, D102, D103, D104, D105, D106, D107, D108, D109, D110, D111, D112, D113, D114, D115, D116, D117, D118, D119, D120, D121, D122, D123, D124, D125, D126, D127, D128, D129, D130, D131, D132, D133, D134, D135, D136, D137, D138, D139, D140, D141, D142, D143, D144, D145, D146, D147, D148, D149, D150, D151, D152, D153, D154, D155, D156, D157, D158, D159, D200, D201, D202, D203, D204, D205, D206: XL-1515RGBC-WS2812B; LED_XL-1515RGBC-WS2812B
J1: USB4135-GF-A; USB_C_Receptacle_GCT_USB4135-GF-A_6P_TopMnt_Horizontal
J2: LiPo 1000mAh; JST_PH_S2B-PH-K_1x02_P2.00mm_Horizontal
J3: u.FL; U.FL_Hirose_U.FL-R-SMT-1_Vertical
MK1: electret; CUI_CMC-4013-SMT_RingGap
Q1, Q4: AO3401A; SOT-23
Q2, Q3, Q5: 2N7002; SOT-23
R1: 113k; R_0603_1608Metric
R2: 102k; R_0603_1608Metric
R3, R9, R10, R14, R18, R24, R25: 100k; R_0603_1608Metric
R4: 150k; R_0603_1608Metric
R5: 2k; R_0603_1608Metric
R6: 330; R_0603_1608Metric
R7, R8: 4.7k; R_0603_1608Metric
R11, R12: 33; R_0603_1608Metric
R13, R17, R19, R22, R26: 10k; R_0603_1608Metric
R15: 10M; R_0603_1608Metric
R16: 1M; R_0603_1608Metric
R20, R21: 5.1k; R_0603_1608Metric
R23: 2.2k; R_0603_1608Metric
R27, R28: 1k; R_0603_1608Metric
SW1: power; SW_SPST_PTS645Sx43SMTR92
SW2: SOS; SW_SPST_PTS645Sx43SMTR92
TP1: touch pogo pin; TestPoint_Pad_D2.5mm
TP2: 3V3; TestPoint_Pad_D1.0mm
TP3: GND; TestPoint_Pad_D1.0mm
TP4: TXD0; TestPoint_Pad_D1.0mm
TP5: RXD0; TestPoint_Pad_D1.0mm
TP6: EN; TestPoint_Pad_D1.0mm
TP7: IO0; TestPoint_Pad_D1.0mm
U1: ESP32-WROOM-32E
U2: MAX-M10S; ublox_MAX
U3: TP4056-42-ESOP8; SOIC-8-1EP_3.9x4.9mm_P1.27mm_EP2.29x3mm
U4: AP2112K-3.3; SOT-23-5
U5: LSM6DSV16X; LGA-14_3x2.5mm_P0.5mm_LayoutBorder3x4y
U6: LIS2MDL; LGA-12_2x2mm_P0.5mm

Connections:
+3V3: C1.1, C3.1, C4.1, C5.1, C6.1, C7.1, C14.1, C19.1, C20.1, C21.1, R7.1, R8.1, R13.1, R16.1, R19.1, R22.1, R23.1, R24.1, TP2.1, U1.2 (VDD), U2.6 (V_BCKP), U2.7 (VCC_IO), U2.8 (VCC), U4.5 (VOUT), U5.5 (VDDIO), U5.8 (VDD), U5.12 (CS), U6.3 (~CS), U6.9 (Vdd), U6.10 (Vdd_IO)
/BTN: D1.2 (A), Q3.1 (G), R18.1, SW1.2
/BTN_SOS: R22.2, SW2.1, TP7.1, U1.25 (IO0)
/CC1: J1.A5 (CC1), R20.1
/CC2: J1.B5 (CC2), R21.1
/CHRG: D4.1 (K), U3.7 (~CHRG)
/CRYSTAL_DATA: R12.1, U1.33 (IO21)
/CRY_D0: D200.3 (DIN), R12.2
/ESP_EN: C2.1, R13.2, TP6.1, U1.3 (EN)
/GATE_MAIN: Q1.1 (G), Q2.3 (D), R14.2
/GNSS_RF: J3.1 (In), U2.11 (RF_IN)
/GNSS_RX: U1.28 (IO17), U2.3 (RXD)
/GNSS_TX: U1.27 (IO16), U2.2 (TXD)
/GPIO4: D2.3 (K), Q3.3 (D), R19.2, U1.26 (IO4)
/HOLD: C12.1, D1.1 (K), Q2.1 (G), R15.1, R16.2, R17.1
/I2C0_SCL: R8.2, U1.11 (IO26), U5.13 (SCL), U6.1 (SCL/SPC)
/I2C0_SDA: R7.2, U1.10 (IO25), U5.14 (SDA), U6.4 (SDA/SDI/SDO)
/IMU_INT1: U1.8 (IO32), U5.4 (INT1)
/IMU_SA0: R26.1, U5.1 (SDO/SA0), U5.2 (SDX), U5.3 (SCX)
/LED_EN: Q5.1 (G), R10.1, U1.31 (IO19)
/MAG_C1: C8.1, U6.5 (C1)
/MAG_DRDY: U1.9 (IO33), U6.7 (DRDY)
/MIC: C18.2, R24.2, R25.1, U1.4 (SENSOR_VP)
/MIC_RAW: C18.1, MK1.2 (+), R23.2
/PROG: R5.1, U3.2 (PROG)
/RING_D0: D100.3 (DIN), R11.2
/RING_D20: D119.1 (DOUT), D120.3 (DIN)
/RING_D40: D139.1 (DOUT), D140.3 (DIN)
/RING_DATA: R11.1, U1.30 (IO18)
/RING_GATE: Q4.1 (G), Q5.3 (D), R9.2
/RXD0: TP5.1, U1.34 (RXD0/IO3)
/SOS_LED: R6.1, U1.13 (IO14)
/SOS_LED_A: D3.2 (A), R6.2
/STDBY: D5.1 (K), U3.6 (~STDBY)
/TOUCH: TP1.1, U1.12 (IO27)
/TXD0: TP4.1, U1.35 (TXD0/IO1)
/VBAT_SENSE: R1.2, R2.1, U1.6 (IO34)
/VBUS_SENSE: R3.2, R4.1, U1.5 (SENSOR_VN)
GND: C1.2, C2.2, C3.2, C4.2, C5.2, C6.2, C7.2, C8.2, C10.2, C11.2, C12.2, C13.2, C14.2, C15.2, C16.2, C17.2, C19.2, C20.2, C21.2, D3.1 (K), D100.2 (VSS), D101.2 (VSS), D102.2 (VSS), D103.2 (VSS), D104.2 (VSS), D105.2 (VSS), D106.2 (VSS), D107.2 (VSS), D108.2 (VSS), D109.2 (VSS), D110.2 (VSS), D111.2 (VSS), D112.2 (VSS), D113.2 (VSS), D114.2 (VSS), D115.2 (VSS), D116.2 (VSS), D117.2 (VSS), D118.2 (VSS), D119.2 (VSS), D120.2 (VSS), D121.2 (VSS), D122.2 (VSS), D123.2 (VSS), D124.2 (VSS), D125.2 (VSS), D126.2 (VSS), D127.2 (VSS), D128.2 (VSS), D129.2 (VSS), D130.2 (VSS), D131.2 (VSS), D132.2 (VSS), D133.2 (VSS), D134.2 (VSS), D135.2 (VSS), D136.2 (VSS), D137.2 (VSS), D138.2 (VSS), D139.2 (VSS), D140.2 (VSS), D141.2 (VSS), D142.2 (VSS), D143.2 (VSS), D144.2 (VSS), D145.2 (VSS), D146.2 (VSS), D147.2 (VSS), D148.2 (VSS), D149.2 (VSS), D150.2 (VSS), D151.2 (VSS), D152.2 (VSS), D153.2 (VSS), D154.2 (VSS), D155.2 (VSS), D156.2 (VSS), D157.2 (VSS), D158.2 (VSS), D159.2 (VSS), D200.2 (VSS), D201.2 (VSS), D202.2 (VSS), D203.2 (VSS), D204.2 (VSS), D205.2 (VSS), D206.2 (VSS), J1.A12 (GND), J1.B12 (GND), J1.SH (SHIELD), J2.2, J3.2 (Ext), MK1.1 (-), Q2.2 (S), Q3.2 (S), Q5.2 (S), R2.2, R4.2, R5.2, R10.2, R15.2, R18.2, R20.2, R21.2, R25.2, R26.2, SW2.2, TP3.1, U1.1, U1.15, U1.38, U1.39, U1.[1,15,38,39] (GND), U2.1 (GND), U2.10 (GND), U2.12 (GND), U3.1 (TEMP), U3.3 (GND), U3.9 (EPAD), U4.2 (GND), U5.6 (GND), U5.7 (GND), U6.6 (GND), U6.8 (GND)
unnamed: D2.1 (A), R17.2
unnamed: D4.2 (A), R27.2
unnamed: D5.2 (A), R28.2
unnamed: D100.1 (DOUT), D101.3 (DIN)
unnamed: D101.1 (DOUT), D102.3 (DIN)
unnamed: D102.1 (DOUT), D103.3 (DIN)
unnamed: D103.1 (DOUT), D104.3 (DIN)
unnamed: D104.1 (DOUT), D105.3 (DIN)
unnamed: D105.1 (DOUT), D106.3 (DIN)
unnamed: D106.1 (DOUT), D107.3 (DIN)
unnamed: D107.1 (DOUT), D108.3 (DIN)
unnamed: D108.1 (DOUT), D109.3 (DIN)
unnamed: D109.1 (DOUT), D110.3 (DIN)
unnamed: D110.1 (DOUT), D111.3 (DIN)
unnamed: D111.1 (DOUT), D112.3 (DIN)
unnamed: D112.1 (DOUT), D113.3 (DIN)
unnamed: D113.1 (DOUT), D114.3 (DIN)
unnamed: D114.1 (DOUT), D115.3 (DIN)
unnamed: D115.1 (DOUT), D116.3 (DIN)
unnamed: D116.1 (DOUT), D117.3 (DIN)
unnamed: D117.1 (DOUT), D118.3 (DIN)
unnamed: D118.1 (DOUT), D119.3 (DIN)
unnamed: D120.1 (DOUT), D121.3 (DIN)
unnamed: D121.1 (DOUT), D122.3 (DIN)
unnamed: D122.1 (DOUT), D123.3 (DIN)
unnamed: D123.1 (DOUT), D124.3 (DIN)
unnamed: D124.1 (DOUT), D125.3 (DIN)
unnamed: D125.1 (DOUT), D126.3 (DIN)
unnamed: D126.1 (DOUT), D127.3 (DIN)
unnamed: D127.1 (DOUT), D128.3 (DIN)
unnamed: D128.1 (DOUT), D129.3 (DIN)
unnamed: D129.1 (DOUT), D130.3 (DIN)
unnamed: D130.1 (DOUT), D131.3 (DIN)
unnamed: D131.1 (DOUT), D132.3 (DIN)
unnamed: D132.1 (DOUT), D133.3 (DIN)
unnamed: D133.1 (DOUT), D134.3 (DIN)
unnamed: D134.1 (DOUT), D135.3 (DIN)
unnamed: D135.1 (DOUT), D136.3 (DIN)
unnamed: D136.1 (DOUT), D137.3 (DIN)
unnamed: D137.1 (DOUT), D138.3 (DIN)
unnamed: D138.1 (DOUT), D139.3 (DIN)
unnamed: D140.1 (DOUT), D141.3 (DIN)
unnamed: D141.1 (DOUT), D142.3 (DIN)
unnamed: D142.1 (DOUT), D143.3 (DIN)
unnamed: D143.1 (DOUT), D144.3 (DIN)
unnamed: D144.1 (DOUT), D145.3 (DIN)
unnamed: D145.1 (DOUT), D146.3 (DIN)
unnamed: D146.1 (DOUT), D147.3 (DIN)
unnamed: D147.1 (DOUT), D148.3 (DIN)
unnamed: D148.1 (DOUT), D149.3 (DIN)
unnamed: D149.1 (DOUT), D150.3 (DIN)
unnamed: D150.1 (DOUT), D151.3 (DIN)
unnamed: D151.1 (DOUT), D152.3 (DIN)
unnamed: D152.1 (DOUT), D153.3 (DIN)
unnamed: D153.1 (DOUT), D154.3 (DIN)
unnamed: D154.1 (DOUT), D155.3 (DIN)
unnamed: D155.1 (DOUT), D156.3 (DIN)
unnamed: D156.1 (DOUT), D157.3 (DIN)
unnamed: D157.1 (DOUT), D158.3 (DIN)
unnamed: D158.1 (DOUT), D159.3 (DIN)
unnamed: D200.1 (DOUT), D201.3 (DIN)
unnamed: D201.1 (DOUT), D202.3 (DIN)
unnamed: D202.1 (DOUT), D203.3 (DIN)
unnamed: D203.1 (DOUT), D204.3 (DIN)
unnamed: D204.1 (DOUT), D205.3 (DIN)
unnamed: D205.1 (DOUT), D206.3 (DIN)
VBAT: C11.1, J2.1, Q1.2 (S), R14.1, SW1.1, U3.5 (BAT)
VBUS: C10.1, J1.A9 (VBUS), J1.B9 (VBUS), R3.1, R27.1, R28.1, U3.4 (V_{CC}), U3.8 (CE)
VLED: C15.1, C16.1, D100.4 (VDD), D101.4 (VDD), D102.4 (VDD), D103.4 (VDD), D104.4 (VDD), D105.4 (VDD), D106.4 (VDD), D107.4 (VDD), D108.4 (VDD), D109.4 (VDD), D110.4 (VDD), D111.4 (VDD), D112.4 (VDD), D113.4 (VDD), D114.4 (VDD), D115.4 (VDD), D116.4 (VDD), D117.4 (VDD), D118.4 (VDD), D119.4 (VDD), D120.4 (VDD), D121.4 (VDD), D122.4 (VDD), D123.4 (VDD), D124.4 (VDD), D125.4 (VDD), D126.4 (VDD), D127.4 (VDD), D128.4 (VDD), D129.4 (VDD), D130.4 (VDD), D131.4 (VDD), D132.4 (VDD), D133.4 (VDD), D134.4 (VDD), D135.4 (VDD), D136.4 (VDD), D137.4 (VDD), D138.4 (VDD), D139.4 (VDD), D140.4 (VDD), D141.4 (VDD), D142.4 (VDD), D143.4 (VDD), D144.4 (VDD), D145.4 (VDD), D146.4 (VDD), D147.4 (VDD), D148.4 (VDD), D149.4 (VDD), D150.4 (VDD), D151.4 (VDD), D152.4 (VDD), D153.4 (VDD), D154.4 (VDD), D155.4 (VDD), D156.4 (VDD), D157.4 (VDD), D158.4 (VDD), D159.4 (VDD), Q4.3 (D)
VSYS: C13.1, C17.1, D200.4 (VDD), D201.4 (VDD), D202.4 (VDD), D203.4 (VDD), D204.4 (VDD), D205.4 (VDD), D206.4 (VDD), Q1.3 (D), Q4.2 (S), R1.1, R9.1, U4.1 (VIN), U4.3 (EN)

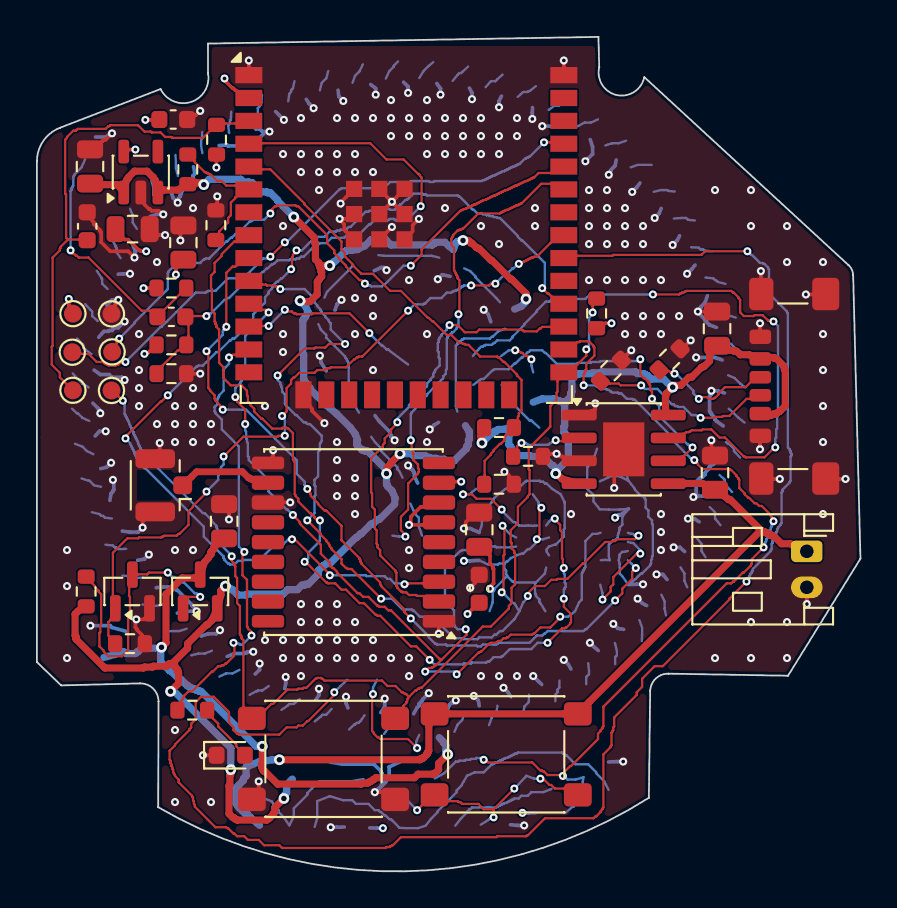
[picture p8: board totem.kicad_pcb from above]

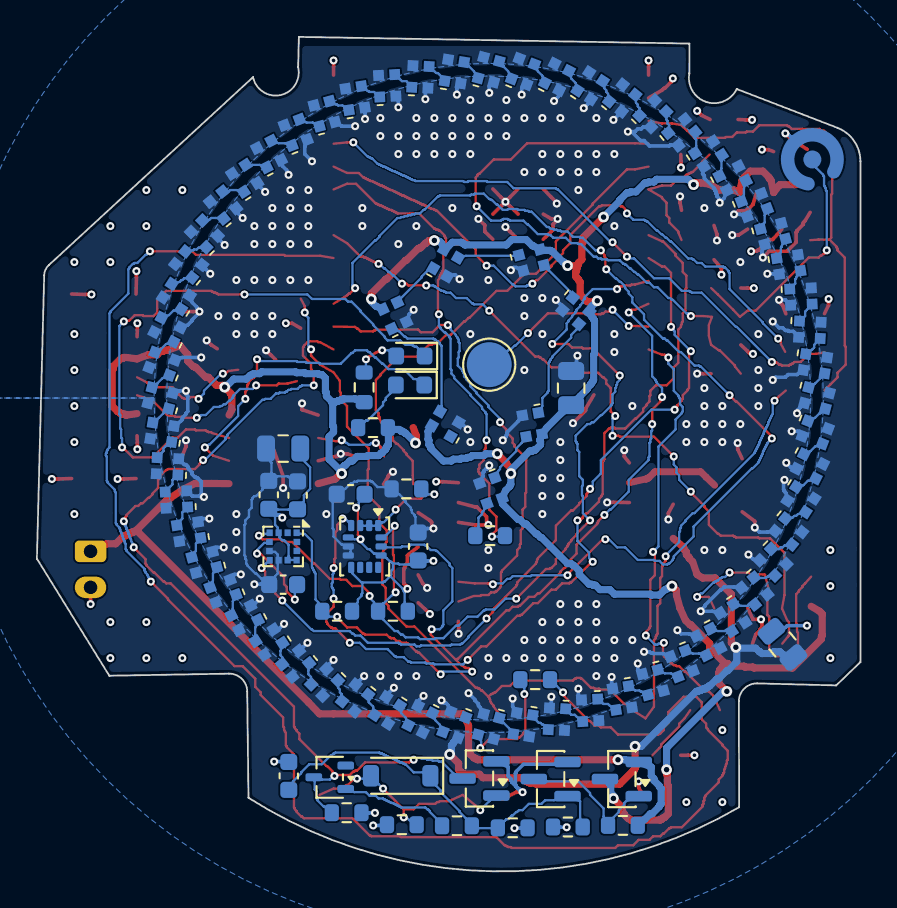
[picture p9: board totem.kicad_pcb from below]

Board: 4 copper layers, 45.8 x 46.4 mm, 144 parts (100 on the bottom side), 109 nets.

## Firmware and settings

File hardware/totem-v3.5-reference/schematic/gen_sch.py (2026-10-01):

#!/usr/bin/env python3
"""Write a KiCad sheet from the circuit, drawn the way a schematic is drawn.

An earlier version of this put a label on every pin. That is technically a
schematic and it passed ERC, but nothing on the sheet *looked* connected,
which fails the only job a schematic has. This draws it properly:

  - **Rails** (GND, +3V3, VBUS, VBAT) get KiCad's power symbols at each pin,
    the way every real schematic does it. That alone takes about 150 labels
    off the sheet.
  - **Point-to-point signals** — the 12 nets with exactly two ends — are
    wired, so the connection is a line you can follow.
  - **Nets with more than two ends** keep a label, which is also what a real
    schematic does once a signal has several destinations.

Parts are placed by hand below, grouped by what they do, because automatic
placement is what made the first attempt unreadable.

Symbols are copied out of KiCad's own libraries by kicad_sexp.py, so the
drawing of a resistor is KiCad's drawing of a resistor. The sheet comes from
the same totem.py the ERC checks, so it cannot drift from the netlist.

Run: python3 gen_sch.py
Writes: totem.kicad_sch (upgraded to the current format by kicad-cli)
"""

import datetime
import json
import math
import subprocess
import uuid as uuidlib

import builtins
import totem  # noqa: F401  (builds the circuit as a side effect)
from kicad_sexp import dump, pin_positions, symbol

GRID = 1.27
STUB = 3 * GRID
TODAY = datetime.date.today().isoformat()

# Rails drawn as power symbols rather than labels. A power symbol's Value is
# the net it names, so VSYS and VLED can ride on the generic VCC symbol.
RAILS = {"GND": "GND", "+3V3": "+3V3", "VBUS": "VBUS", "VBAT": "+BATT",
         "VSYS": "VCC", "VLED": "VCC"}

# Placed by function on an A0 sheet: power path along the top, the latch and
# the MCU through the middle, the two LED chains as grids along the bottom.
# Coordinates are millimetres and get snapped to the grid.
FLOORPLAN = {
    # USB-C and its CC resistors
    "J1": (60, 75), "R20": (150, 45), "R21": (150, 90), "C10": (185, 70),
    # charger and cell
    "U3": (265, 75), "R5": (335, 60), "C11": (365, 60), "J2": (410, 75),
    # regulator
    "U4": (490, 65), "C13": (455, 115), "C14": (535, 115),
    # sense dividers
    "R1": (600, 45), "R2": (600, 95), "R3": (645, 45), "R4": (645, 95),
    # GNSS
    "U2": (770, 95), "C5": (705, 170), "C6": (735, 170), "J3": (860, 80),
    # charge-status LEDs, under the charger
    "R27": (235, 145), "D4": (235, 190), "R28": (295, 145), "D5": (295, 190),
    # the motion sensor and the magnetometer
    "U5": (935, 95), "C1": (890, 175), "C7": (920, 175), "R26": (950, 175),
    "R7": (1000, 55), "R8": (1030, 55),
    "U6": (1085, 95), "C8": (1045, 175), "C19": (1075, 175), "C20": (1105, 175), "C21": (1135, 175),
    # the power latch
    "SW1": (60, 290), "R18": (100, 335), "D1": (150, 290), "Q3": (165, 365),
    "R19": (215, 330), "D2": (255, 300), "R17": (295, 300), "Q2": (245, 415),
    "R15": (195, 440), "C12": (225, 460), "R16": (305, 385), "Q1": (335, 445),
    "R14": (385, 425),
    # the MCU, its reset, its strap and its programming pads
    "U1": (565, 375), "C3": (470, 300), "C4": (500, 300),
    "R13": (665, 265), "C2": (695, 295), "R22": (470, 455), "SW2": (470, 505),
    "TP2": (760, 265), "TP3": (760, 300), "TP4": (760, 335),
    "TP5": (760, 370), "TP6": (760, 405), "TP7": (760, 440),
    # SOS indicator, touch, microphone
    "R6": (850, 300), "D3": (900, 300), "TP1": (850, 380),
    "R23": (1000, 255), "MK1": (1000, 305), "C18": (1050, 305),
    "R24": (1095, 265), "R25": (1095, 345),
    # ring power switch and data resistors
    "R9": (840, 445), "Q4": (875, 475), "Q5": (935, 475), "R10": (965, 505),
    "R11": (1005, 475), "C15": (1065, 455), "C16": (1095, 455),
    "R12": (1005, 525), "C17": (1065, 525),
}
# The ring: 60 pixels, 20 to a row, close enough that each pixel's DOUT
# wires straight to the next one's DIN.
for _i in range(60):
    FLOORPLAN[f"D{100 + _i}"] = (60 + (_i % 20) * 40, 600 + (_i // 20) * 65)
# The crystal: 7 more, one row.
for _i in range(7):
    FLOORPLAN[f"D{200 + _i}"] = (60 + _i * 40, 800)


def snap(v):
    return round(v / GRID) * GRID


# A fixed namespace, so the same circuit always produces the same file.
NS = uuidlib.UUID("6ba7b811-9dad-11d1-80b4-00c04fd430c8")


def uid(key=None):
    """A uuid derived from `key`, or a random one when there is no key.

    Symbols and footprints are linked by uuid, not by reference designator,
    so a board updated from a schematic whose uuids changed sees no
    matching footprints: it deletes every one and adds them again, losing
    all placement and routing. Random uuids would make every regeneration
    of this file destroy a layout built on the last one. They also key ERC
    exclusions, which would evaporate the same way.
    """
    return str(uuidlib.uuid5(NS, key) if key else uuidlib.uuid4())


def rename(sym, lib_id):
    out = list(sym)
    for i, child in enumerate(out):
        if isinstance(child, tuple) and child[0] == "str":
            out[i] = ("str", lib_id)
            break
    return out


def outward(rot):
    """Where a pin's wire runs, away from the body, in sheet coordinates."""
    return -math.cos(math.radians(rot)), math.sin(math.radians(rot))


def label_angle(dx, dy):
    if abs(dx) > abs(dy):
        return 0 if dx > 0 else 180
    return 270 if dy > 0 else 90


class Sheet:
    def __init__(self):
        self.items = []
        self.libs = {}
        self.footprints = {}
        self.power_n = {}
        self.uuid = uid("sheet:totem")

    def need(self, lib, name):
        lib_id = f"{lib}:{name}"
        if lib_id not in self.libs:
            sym = symbol(lib, name)
            self.libs[lib_id] = rename(sym, lib_id)
            # Several library symbols name the package they are normally
            # fitted in. Carrying that through means those parts arrive with
            # a footprint already chosen rather than blank, which is what
            # "Symbols can specify a preselected footprint" is for. The rest
            # are passives and connectors, where the library cannot know and
            # a person has to decide.
            for child in sym:
                if (isinstance(child, list) and child and child[0] == "property"
                        and len(child) > 2 and isinstance(child[1], tuple)
                        and child[1][1] == "Footprint"
                        and isinstance(child[2], tuple) and child[2][1]):
                    self.footprints[lib_id] = child[2][1]
                    break
        return lib_id

    def power_ref(self, prefix):
        """Sequential #PWR01, #FLG01… rather than random hex.

        References must be unique and ERC checks for duplicates. Four random
        hex characters over 55 symbols is about a two percent chance of a
        collision on any given run — it had not happened yet, which is not
        the same as it being safe.
        """
        self.power_n[prefix] = self.power_n.get(prefix, 0) + 1
        return f"{prefix}{self.power_n[prefix]:02d}"

    def place(self, lib_id, x, y, ref, value, hide=False, on_board=True,
              hide_ref=False, value_below=False, footprint=None, in_bom=None):
        """Place a symbol.

        `hide_ref` hides the reference but leaves the value showing, which
        is what a power symbol wants: its Value field *is* the net name, so
        hiding it leaves a sheet full of unlabelled arrows where no rail can
        be told from another. KiCad's own power library hides the reference
        and shows the value, for that reason.
        """
        eff = ["effects", ["font", ["size", "1.27", "1.27"]]]
        if hide:
            eff.append(["hide", "yes"])
        hidden = ["effects", ["font", ["size", "1.27", "1.27"]], ["hide", "yes"]]
        ref_eff = list(hidden) if (hide or hide_ref) else list(eff)
        val_eff = list(hidden) if hide else list(eff)
        # Ground hangs below its connection point, the supplies rise above
        # it, so the name goes on the far side in each case rather than on
        # top of the stub wire.
        val_y = y + 5 if value_below else y - 8
        footprint = footprint or self.footprints.get(lib_id, "")
        self.items.append(
            ["symbol",
             ["lib_id", ("str", lib_id)],
             ["at", f"{x:.2f}", f"{y:.2f}", "0"],
             ["unit", "1"],
             ["exclude_from_sim", "no"],
             ["in_bom", "yes" if (on_board if in_bom is None else in_bom) else "no"],
             ["on_board", "yes" if on_board else "no"],
             ["dnp", "no"],
             ["uuid", ("str", uid(f"sym:{ref}"))],
             ["property", ("str", "Reference"), ("str", ref),
              ["at", f"{x:.2f}", f"{y - 12:.2f}", "0"], ref_eff],
             ["property", ("str", "Value"), ("str", value),
              ["at", f"{x:.2f}", f"{val_y:.2f}", "0"], val_eff],
             ["property", ("str", "Footprint"), ("str", footprint),
              ["at", f"{x:.2f}", f"{y - 4:.2f}", "0"], list(hidden)],
             ["instances",
              ["project", ("str", "totem"),
               ["path", ("str", "/" + self.uuid),
                ["reference", ("str", ref)], ["unit", "1"]]]]]
        )

    def wire(self, x1, y1, x2, y2):
        if (x1, y1) == (x2, y2):
            return
        self.items.append(
            ["wire",
             ["pts", ["xy", f"{x1:.2f}", f"{y1:.2f}"], ["xy", f"{x2:.2f}", f"{y2:.2f}"]],
             ["stroke", ["width", "0"], ["type", "default"]],
             ["uuid", ("str", uid(f"wire:{x1},{y1}-{x2},{y2}"))]]
        )

    def label(self, name, x, y, angle):
        """A local label.

        The manual is explicit that local labels connect within a sheet and
        global labels connect across sheets regardless of hierarchy. This
        design is one flat sheet, so globals would be claiming a scope it
        does not have — and their boxed outlines are much of what made the
        first drawing unreadable.
        """
        self.items.append(
            ["label", ("str", name),
             ["at", f"{x:.2f}", f"{y:.2f}", str(angle)],
             ["effects", ["font", ["size", "1.27", "1.27"]], ["justify", "left"]],
             ["uuid", ("str", uid(f"label:{name}@{x},{y}"))]]
        )

    def no_connect(self, x, y):
        self.items.append(
            ["no_connect", ["at", f"{x:.2f}", f"{y:.2f}"],
             ["uuid", ("str", uid(f"nc:{x},{y}"))]]
        )

    def render(self, paper="A0"):
        return dump(
            ["kicad_sch",
             ["version", "20250114"],
             ["generator", ("str", "gen_sch.py")],
             ["generator_version", ("str", "10.0")],
             ["uuid", ("str", self.uuid)],
             ["paper", ("str", paper)],
             # A sheet with an empty title block says nothing about what it
             # is or how far to trust it, and this one needs to say both.
             ["title_block",
              ["title", ("str", "Totem v3.5 — reference design")],
              ["date", ("str", TODAY)],
              ["rev", ("str", "A")],
              ["company", ("str", "reconstruction, not the Totem's recovered circuit")],
              ["comment", "1", ("str", "Parts and MCU pins are established; passive "
                                       "values are designed to satisfy the firmware.")],
              ["comment", "2", ("str", "Generated by gen_sch.py from totem.py — "
                                       "edit the source, not this sheet.")],
              ["comment", "3", ("str", "U3 (TP4056) has no KiCad symbol and is absent "
                                       "from this sheet; it is in the netlist.")],
              ["comment", "4", ("str", "Verified: kicad-cli sch erc, and ngspice "
                                       "decks under ../sim.")]],
             ["lib_symbols", *self.libs.values()],
             *self.items,
             # The root sheet's own instance. The format documentation lists
             # this as a section of its own, and the path for a root sheet is
             # always "/" because nothing points at it.
             ["sheet_instances", ["path", ("str", "/"), ["page", ("str", "1")]]]]
        )


def main():
    circuit = builtins.default_circuit
    sheet = Sheet()
    where = {}          # ref -> (lib_id, x, y)
    pin_at = {}         # (ref, pin num) -> (x, y, outward dx, dy)
    undrawn = []

    spare_x, spare_y = 55, 500
    for part in sorted(circuit.parts, key=lambda p: p.ref):
        try:
            lib = str(part.lib.filename).replace(".kicad_sym", "")
        except AttributeError:
            undrawn.append(part)
            continue
        try:
            lib_id = sheet.need(lib, part.name)
        except (KeyError, FileNotFoundError, OSError):
            undrawn.append(part)
            continue
        x, y = FLOORPLAN.get(part.ref, (spare_x, spare_y))
        if part.ref not in FLOORPLAN:
            spare_x += 45
        where[part.ref] = (lib_id, snap(x), snap(y))

    for part in circuit.parts:
        if part.ref not in where:
            continue
        lib_id, x, y = where[part.ref]
        sheet.place(lib_id, x, y, part.ref, str(part.value or part.name), footprint=getattr(part, "footprint", None) or None,
                    in_bom=getattr(part, "in_bom", True))
        geom = pin_positions(sheet.libs[lib_id])
        for pin in part.pins:
            nums = pin.num if isinstance(pin.num, list) else [pin.num]
            for num in nums:
                g = geom.get(str(num))
                if g is None:
                    continue
                px, py, rot, _ = g
                ax, ay = x + px, y - py
                dx, dy = outward(rot)
                if pin.net is None:
                    sheet.no_connect(ax, ay)
                else:
                    pin_at[(part.ref, str(num))] = (ax, ay, dx, dy)

    # Rails become power symbols, one per pin, which is how a schematic says
    # "this is ground" without drawing a line to every other ground.
    #
    # Deduplicated by point, because a symbol's pins can be stacked: the
    # USB-C receptacle has four GND contacts and four VBUS contacts at one
    # place each, and drawing per pin put four wires and four ground symbols
    # on top of each other. Stacked pins are one connection, so they get one
    # symbol.
    drawn = set()
    for net in circuit.nets:
        if net.name not in RAILS:
            continue
        lib_id = sheet.need("power", RAILS[net.name])
        for pin in net.pins:
            nums = pin.num if isinstance(pin.num, list) else [pin.num]
            for num in nums:
                spot = pin_at.get((pin.part.ref, str(num)))
                if spot is None:
                    continue
                ax, ay, dx, dy = spot
                if (ax, ay) in drawn:
                    continue
                drawn.add((ax, ay))
                bx, by = snap(ax + dx * STUB), snap(ay + dy * STUB)
                sheet.wire(ax, ay, bx, by)
                sheet.place(lib_id, bx, by, sheet.power_ref("#PWR"), net.name,
                            hide_ref=True, on_board=False,
                            value_below=(net.name == "GND"))

    # PWR_FLAG says a rail is fed by something off-sheet or by a part that
    # is not a power output, which is what KiCad's power_pin_not_driven rule
    # asks for. VBUS comes from a connector, VLED through a switch, and
    # ground from nothing that drives it.
    #
    # VBAT is deliberately NOT flagged: the charger's BAT pin is a real
    # power output, so the rail has a genuine driver. It needed a flag only
    # while U3 was missing from the sheet — the flag was standing in for the
    # part, which is exactly the kind of quiet compensation that hides a
    # hole rather than showing it.
    flag_id = sheet.need("power", "PWR_FLAG")
    for n, rail in enumerate(("VBUS", "VSYS", "VLED", "GND")):
        fx, fy = snap(420 + n * 60), snap(820)
        sheet.place(flag_id, fx, fy, sheet.power_ref("#FLG"), "PWR_FLAG",
                    hide=True, on_board=False)
        fg = pin_positions(sheet.libs[flag_id])
        px, py, rot, _ = next(iter(fg.values()))
        ax, ay = fx + px, fy - py
        dx, dy = outward(rot)
        bx, by = snap(ax + dx * STUB), snap(ay + dy * STUB)
        sheet.wire(ax, ay, bx, by)
        if rail in RAILS:
            sheet.place(sheet.need("power", RAILS[rail]), bx, by,
                        sheet.power_ref("#PWR"), rail, hide_ref=True,
                        on_board=False, value_below=(rail == "GND"))
        else:
            sheet.label(rail, bx, by, label_angle(dx, dy))

    # Two-ended signals are wired, so the connection is a line to follow.
    # Everything else keeps a label, as a real sheet does once a signal has
    # more than one destination.
    for net in circuit.nets:
        if net.name in RAILS:
            continue
        ends = []
        for pin in net.pins:
            nums = pin.num if isinstance(pin.num, list) else [pin.num]
            for num in nums:
                spot = pin_at.get((pin.part.ref, str(num)))
                if spot:
                    ends.append(spot)
        near = False
        if len(ends) == 2:
            (ax, ay, adx, ady), (bx, by, bdx, bdy) = ends
            near = math.dist((ax, ay), (bx, by)) <= 45
        if near:
            a2 = (snap(ax + adx * STUB), snap(ay + ady * STUB))
            b2 = (snap(bx + bdx * STUB), snap(by + bdy * STUB))
            sheet.wire(ax, ay, *a2)
            sheet.wire(bx, by, *b2)
            # One corner between them, which keeps the run orthogonal.
            sheet.wire(a2[0], a2[1], b2[0], a2[1])
            sheet.wire(b2[0], a2[1], b2[0], b2[1])
        else:
            for ax, ay, dx, dy in ends:
                bx, by = snap(ax + dx * STUB), snap(ay + dy * STUB)
                sheet.wire(ax, ay, bx, by)
                sheet.label(net.name, bx, by, label_angle(dx, dy))

    # Junction dots. KiCad adds these itself in the editor — "junction dots
    # will be automatically added to wires that start or end on top of an
    # existing wire" — but a file written from outside gets none, and
    # without them a reader cannot tell a join from a crossing. They are
    # readability rather than connectivity here: nothing in this sheet ends
    # mid-segment, so the netlist is the same either way.
    ends = {}
    for item in sheet.items:
        if item[0] != "wire":
            continue
        for xy in item[1][1:]:
            ends[(xy[1], xy[2])] = ends.get((xy[1], xy[2]), 0) + 1
    for (x, y), n in sorted(ends.items()):
        if n >= 3:
            sheet.items.append(
                ["junction", ["at", x, y], ["diameter", "0"],
                 ["color", "0", "0", "0", "0"],
                 ["uuid", ("str", uid(f"junction:{x},{y}"))]]
            )

    # The project file goes first, and it matters that it does. A loose
    # .kicad_sch opens in standalone mode, where KiCad disables design
    # synchronisation between the schematic and the board — so without this
    # there is no route from here to a layout at all. It also has to exist
    # before the upgrade below runs, or that step has no project in scope
    # and blanks the project name on all 85 symbol instances.
    #
    # `sheets` keys the root sheet by its own uuid, which is why this is
    # written here rather than kept as a static file: the two cannot drift.
    project = {
        "meta": {"filename": "totem.kicad_pro", "version": 3},
        "sheets": [[sheet.uuid, "Root"]],
        "libraries": {"pinned_footprint_libs": [], "pinned_symbol_libs": []},
        "erc": {}, "net_settings": {}, "schematic": {}, "text_variables": {},
        "board": {}, "boards": [], "cvpcb": {}, "pcbnew": {},
    }
    with open("totem.kicad_pro", "w") as fh:
        json.dump(project, fh, indent=2)
        fh.write("\n")

    with open("totem.kicad_sch", "w") as fh:
        fh.write(sheet.render() + "\n")

    # KiCad writes a newer format than anything that can be hand-built here,
    # and says so in a banner when it opens an older one. Let it do the
    # conversion rather than guessing the version number.
    subprocess.run(["kicad-cli", "sch", "upgrade", "totem.kicad_sch"],
                   capture_output=True, check=False)

    print(f"totem.kicad_sch: {len(where)} symbols, "
          f"{sum(1 for i in sheet.items if i[0] == 'wire')} wires")
    for part in undrawn:
        print(f"  not drawn (no KiCad symbol): {part.ref} {part.name}")


if __name__ == "__main__":
    main()

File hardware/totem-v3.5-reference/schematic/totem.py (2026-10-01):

#!/usr/bin/env python3
"""The Totem v3.5 reference design: every part, every net, every footprint.

This is the single source the schematic sheet, the simulation, the ERC and
the PCB are all generated from. It reproduces the circuit of a Totem v3.5 as
far as the board and the firmware establish it, and designs the rest so the
result works with that firmware.

What is established, and where from:
  - The parts: read off the board (docs/reference/hardware.mdx).
  - Every MCU pin, including the GNSS UART on 16/17 (`UART(1, rx=16, tx=17)`
    in ubx_gnss) and the ring power gate on 19 driven HIGH to light the ring
    (`LightStrip.power_on` calls `pwr_gate.on()` in leds).
  - That only the ring is gated; the crystal has no power gate (leds).
  - That GPIO 4 is read as the power button with a pull-up, and is driven
    low to switch the board off (power.mdx, `shut_down(method=0)`).

What is designed here, because a photograph cannot show it, and is marked
as such below: the power latch, the passive values, the programming pads.

Run: python3 check.py   (runs this and checks the result)
"""

import os

KICAD_SYMBOLS = "/Applications/KiCad/KiCad.app/Contents/SharedSupport/symbols"
os.environ.setdefault("KICAD10_SYMBOL_DIR", KICAD_SYMBOLS)

from skidl import ERC, Net, Part, Pin, generate_netlist  # noqa: E402

R0603 = "Resistor_SMD:R_0603_1608Metric"   # the reference board's resistors are 0603
C0805 = "Capacitor_SMD:C_0805_2012Metric"   # and its bulk capacitors 0805
C0603 = "Capacitor_SMD:C_0603_1608Metric"
SOT23 = "Package_TO_SOT_SMD:SOT-23"
# 6x6 mm SMD tact switch, top-actuated, tall stem through the rear cover (PTS645 land pattern)
SW6X6 = "Button_Switch_SMD:SW_SPST_PTS645Sx43SMTR92"
LED1515 = "totem:LED_XL-1515RGBC-WS2812B"   # schematic/totem.pretty, from the datasheet


def leave_unused(part, used, why):
    """Take a part's remaining pins out of ERC, on the record."""
    for pin in part.pins:
        nums = pin.num if isinstance(pin.num, list) else [pin.num]
        if not any(str(n) in used for n in nums):
            pin.do_erc = False
    part.unused_note = why


def R(ref, value, fp=R0603):
    return Part("Device", "R", ref=ref, value=value, footprint=fp)


def C(ref, value, fp=C0603):
    return Part("Device", "C", ref=ref, value=value, footprint=fp)


def net(name, *pins):
    n = Net(name)
    for pin in pins:
        n += pin
    return n


# The rails. VBAT is the cell and is always live; VSYS is VBAT switched by
# the power latch, so nothing downstream draws when the board is off; +3V3
# is the regulator; VLED is VSYS switched again for the ring only.
vbus, vbat, vsys, v3v3, vled, gnd = (
    Net(n) for n in ("VBUS", "VBAT", "VSYS", "+3V3", "VLED", "GND"))
for n in (vbus, vbat, vsys, v3v3, vled, gnd):
    n.drive = Pin.drives.POWER

# ------------------------------------------------------------------ USB-C
# Charge-only. The firmware updates over Wi-Fi and nothing in it reads USB
# data, so D+/D- are left unconnected. CC1/CC2 each need 5.1k to ground or a
# USB-C source will not turn VBUS on at all — the most common way a USB-C
# board ends up charging from an A-to-C cable and nothing else.
# A power-only 6-pin receptacle, then: it has everything a charge-only port
# uses. And it has to be all-SMD. The ring's LEDs pass within 5 mm of the
# board edge right behind the connector, on the other side, and the
# reference board's shell tabs sit just outside them (measured 18.75 and
# 21.4 mm from the centre line, 2.5 mm apart); a common 16-pin part's rear
# tabs (4.2 mm behind its front ones) would land on the ring. GCT USB4135's
# footprint was the one in KiCad's library that clears it and still reaches
# 1.75 mm past the edge (pcb/usbfit.py).
j1 = Part("Connector", "USB_C_Receptacle_PowerOnly_6P", ref="J1", value="USB4135-GF-A",
          footprint="Connector_USB:USB_C_Receptacle_GCT_USB4135-GF-A_6P_TopMnt_Horizontal")
r_cc1, r_cc2 = R("R20", "5.1k"), R("R21", "5.1k")
c_vbus = C("C10", "10u", C0805)
vbus += j1["A9"], j1["B9"], c_vbus[1]
gnd += j1["A12"], j1["B12"], j1["SH"], c_vbus[2], r_cc1[2], r_cc2[2]
net("CC1", j1["A5"], r_cc1[1])
net("CC2", j1["B5"], r_cc2[1])

# ---------------------------------------------------------------- charger
# TP4056, the part on the board (marked 4056). PROG sets the charge current
# as 1200/R: 2k gives 600 mA, 0.6C for the 1000 mAh cell. A linear charger
# burns (VBUS - VBAT) x I, which at 1 A is up to 1.5 W in a sealed enclosure
# and would throttle; 600 mA keeps that under 1 W. CE high enables it, and
# must be driven — floating, the part does nothing.
u3 = Part("Battery_Management", "TP4056-42-ESOP8", ref="U3",
          footprint="Package_SO:SOIC-8-1EP_3.9x4.9mm_P1.27mm_EP2.29x3mm")
r_prog = R("R5", "2k")
c_bat = C("C11", "10u", C0805)
vbus += u3["4"], u3["8"]
gnd += u3["1"], u3["3"], u3["9"], r_prog[2], c_bat[2]
net("PROG", u3["2"], r_prog[1])
vbat += u3["5"], c_bat[1]
# Charge status, as the reference board shows it: two 0603 indicator LEDs in
# the crystal, below the touch post (photographed; their colours, unlit, are
# not). CHRG and STDBY are open-drain and pull low while charging and once
# charged, so each LED hangs from VBUS through its resistor: lit only with a
# charger plugged in, and drawing nothing from the cell. 1k gives about 3 mA.
d_chrg = Part("Device", "LED", ref="D4", value="red", footprint="LED_SMD:LED_0603_1608Metric")
d_stdby = Part("Device", "LED", ref="D5", value="green", footprint="LED_SMD:LED_0603_1608Metric")
r_chrg, r_stdby = R("R27", "1k"), R("R28", "1k")
vbus += r_chrg[1], r_stdby[1]
net("CHRG_LED", r_chrg[2], d_chrg["A"])
net("STDBY_LED", r_stdby[2], d_stdby["A"])
net("CHRG", u3["7"], d_chrg["K"])
net("STDBY", u3["6"], d_stdby["K"])

# Through-hole, side entry, as the reference board's: its two pins show as
# solder joints 1.96 mm apart on the LED side (measured), which an SMD
# connector would not leave. A THT part can also overhang the corner chamfer
# as the original does, where the SMD one's rear pads could not.
j2 = Part("Connector_Generic", "Conn_01x02", ref="J2", value="LiPo 1000mAh",
          footprint="Connector_JST:JST_PH_S2B-PH-K_1x02_P2.00mm_Horizontal")
vbat += j2[1]
gnd += j2[2]
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

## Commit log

2026-09-19 docs: update to firmware v5.0.3 and correct BLE protocol findings (#2)
    Updates the docs site from firmware v5.0.2 to **v5.0.3** (release 339,
    SHA-256 `bfe1f5a4…23450dc4`, verified against the release API).
    ## How
    Every frozen module in both images was rebuilt and disassembled with
    MicroPython's `mpy-tool.py`, then diffed function by function: **74
    identical, 20 changed, 2 removed** (`imu_fusion.py`, `io_mgr.py`,
    neither imported). The new page `firmware/changes-5.0.3` lists every
    difference.
    ## Highlights
    - **The BLE and ESP-NOW wire formats are unchanged.** v5.0.3 adds a
    third characteristic (`…-0003`, log-upload chunks), an optional
    upload-capability byte in the Ready frame, and a 15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
2026-09-19 feat: add totemctl, a Go BLE client for the Totem Compass (#3)
    Adds the `totemctl` Go client that the docs already refer to
    (`protocol/`, `client/`, `cmd/totemctl/`), plus a README section on how
    to use it.
    ## What it does
    Speaks the Totem's BLE protocol the way the official app does: the
    ConnStatus-Ready handshake, Static/Live/Peer records with app-level
    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
2026-09-20 fix: dropped legacy ack on a repeat, and hex with a non-ASCII space (#5)
    Fixes both jobs that failed on main in [run
    35461379162](https://github.com/ljagiello/totem-compass/actions/runs/35461379162):
    `Test (ubuntu-latest)` and `Fuzz FuzzParseRawFrame`. Both were real, not
    runner noise.
    ## `client`: an ack could be dropped when a record repeated
    The legacy transmit loop repeats Static Data, the WiFi list and Peer
    Sync until the app acks them, and `legacyAck` suppresses an ack while
    the same one is already pending. The writer cleared that flag only
    **after** the write finished, so a repeat arriving while our ack was on
    the wire was suppressed and never answered. The device then repeats the
    r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
2026-09-21 feat: emulate a Totem on the ESP-NOW mesh with an ESP32 (#4)
    ## Summary
    An ESP32 running Go (TinyGo + `tinygo.org/x/espradio`) that joins the
    Totem ESP-NOW mesh as another Totem. It pairs with a real Totem on
    firmware 5.0.3 through the normal Touch Crystal pairing, then exchanges
    peer status with it in every radio window — with a modelled GNSS
    receiver, compass, motion sensor and battery, the halo and crystal, the
    Touch Crystal and buttons, power management and sleep, WiFi OTA, and
    settings that survive a reboot in a flash sector.
    **Hardware-tested** with an ESP32-D0WD-V3 and the author's Totem on
    5.0.3:
    - the bond completed, and came back by itself after the board rebooted;
    - the Totem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
2026-09-27 fix: match the firmware's locate-relay rules, and carry the mesh for strangers behind a flag (#6)
    Reading `Parser._relay_frame` and its callers properly, to answer "does
    a Totem in the middle pass frames between two out-of-range Totems?",
    turned up two things the relay documentation had wrong and one real gap
    in the emulator.
    ## The bonded path only relays requests
    `compass_mesh` tests `data[13]` — `is_ack` — before relaying a frame
    from one of our own bonded peers, and the reply is built as
    `gen_mesh_msg(cmd_id=0, is_ack=0)`. **A bonded peer's reply is never
    carried.** Both branches of that test land past both relay call sites
    (jump targets resolved, not eyeballed), and the tuple inde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
2026-09-27 chore: ignore .claude/ (#7)
    Claude Code keeps its session state in `.claude/`, and checks its git
    worktrees out under `.claude/worktrees` — including the one this was
    written in. None of it is source, and an untracked directory holding a
    worktree of this same repository is the kind of thing that gets
    committed by a wide `git add` exactly once.
    Nothing under it was tracked, so this only stops it being offered.
    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
2026-09-30 feat: run the emulator on a real T-Beam S3 Supreme, reading its own sensors (#8)
    `cmd/totememu` was an ESP32 program with simulated sensors. It now also
    runs on a LILYGO
    T-Beam S3 Supreme and reads that board's own parts: position, speed,
    course and clock from its
    GNSS receiver, the battery from its power chip, the orientation from its
    IMU, and — after a
    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
2026-09-30 hardware: a Totem v3.5 board, from photographs to fab files (#9)
    A Totem v3.5 board, from the reference unit's photographs to files a fab
    can build: the parts on it and the nets between them
    (`docs/reference/hardware.mdx`), a working circuit that satisfies what
    the firmware does (`hardware/totem-v3.5-reference/schematic`), and a
    4-layer board with the reference board's outline and part positions,
    routed and ready to order (`schematic/totem.kicad_pcb`, outputs in
    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
    [totem-B_Cu.gbr, totem-B_Mask.gbr, totem-B_Paste.gbr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]
2026-09-30 fix: ask the T-Beam's GNSS receiver what it is, instead of assuming an L76K (#10)
    The docs said the emulator's T-Beam carries a Quectel L76K, and blamed
    it for seeing 5–8 satellites where the Totem beside it saw 18. That came
    from a hedged driver comment read as a finding; nobody had asked the
    board. Asked, it answers **`MOD=MAX-M10S`, `FWVER=SPG 5.10`**: the
    Totem's own module and firmware. It also rejects Quectel's `PCAS`
    commands.
    So the receiver is now asked at every boot instead of assumed.
    - **`gnss.Identify`** reads the answer in both forms a u-blox gives it:
    the start-up NMEA banner and the binary UBX-MON-VER reply. It also reads
    a CASIC `SW=` answer for an L76K; that path follow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
2026-09-30 hardware: the package to have the Totem v3.5 board made and assembled (#11)
    One file to hand to a fab and an assembler:
    **`hardware/totem-v3.5-reference/pcb/fab/totem-v3.5-assembly-package.zip`**,
    with **[`ASSEMBLY.md`](hardware/totem-v3.5-reference/pcb/ASSEMBLY.md)**
    inside saying what to do with it.
    ## In the package
    | File | For |
    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
    [totem-B_Cu.gbr, totem-B_Mask.gbr, totem-B_Paste.gbr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]
2026-10-01 hardware: ST motion sensors, the LED side's missing parts, and a BOM of parts that exist (#12)
    Close-up photographs of the reference board's LED side, and a
    part-by-part check of the BOM against DigiKey and LCSC, changed the
    board.
    ## LED side: what the close-ups showed
    | Reference board | Before this PR | Now |
    | --- | --- | --- |
    | **Two 0603 LEDs** in the crystal below the touch post, each with an
    0603 resistor | Missing; the TP4056's `CHRG`/`STDBY` were left open | D4
    (red, charging) and D5 (green, charged) with 1k each, at the
    photographed positions. Colours aren't visible unlit; red/green is the
    TP4056 convention |
    | **Through-hole JST**: its pins' joints show on the LED side, 1.96 m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
    [totem-B_Cu.gbr, totem-B_Mask.gbr, totem-B_Paste.gbr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]
